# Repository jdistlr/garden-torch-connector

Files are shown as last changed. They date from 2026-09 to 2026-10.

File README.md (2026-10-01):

# Gartenfackel · gewählter Sockel D-V03

**Arbeitsstand 28.09.2026: prüfbares Konzept, keine Fertigungs- oder Betriebsfreigabe.** Ausschließlich Variante D wird weiterentwickelt: massive schwarze Aufnahme mit direkt eingeschnittenem axialem Gewindesackloch. Fünf Teile, keine Gewindebuchse oder Fügezone.

[Projekt öffnen](https://jdistlr.github.io/garden-torch-connector/web/projekt.html) · [Viewer öffnen](https://jdistlr.github.io/garden-torch-connector/web/variants.html) · [Entscheidungskette](docs/entscheidungen-d.md) · [Montage](docs/montage-d.md)

## Der rote Faden

1. **Verstehen:** [Originalfotos](sources/README.md) und [Steck-Dreh-Prinzip](docs/mechanik-d.md). Der frühere Erdspieß ist Referenz, kein Teil des neuen Sockels.
2. **Ausführung wählen:** 150 × 150 mm Grundplatte mit 5/8/9 mm, massive Aufnahme, radialer Stift, Senkschraube und geschlitztes Rohr. Detailmaße bleiben Konzeptwerte oder Fotoschätzungen.
3. **Nachweise unterscheiden:** Geometrie und nominale Bewegungsstichproben liegen vor. Reale Maße, Sicherungen, Werkzeugzugang, Kaufteilpassung und Standsicherheit sind offen.
4. **Teile abstimmen:** [Beschaffungskandidaten](docs/beschaffung-d.md) müssen gegen die [aktuelle Stückliste](docs/entscheidungen-d.md) freigegeben werden. Andere Rohr-/Stiftmaße sind bisher nicht im CAD übernommen.
5. **Kosten entscheiden:** [Budgetstudie](docs/kosten-d.md) für abweichende Kandidaten, ausschließlich 5 mm; noch kein Gesamtpreis des aktuellen CAD und kein Bestellpaket.
6. **Fertigen, montieren, prüfen:** [Konzeptanleitung und Prüfprotokoll](docs/montage-d.md). Erst nach den dokumentierten Nachweisen entsteht eine freigegebene Ausführung.

## Was vorhanden ist

- D-V03-STEP-Baugruppen und fünf Einzelteile für 5/8/9 mm, CAD-abgeleitete Browsermodelle.
- Je drei A3-Prüfzeichnungen für jede Plattenstärke. Im Viewer folgen PDF, Vorschau und STEP der Auswahl, auch wenn WebGL ausfällt.
- Freie 3D-Ansicht, Schnitt, Transparenz, Teileauswahl, Explosionsansicht, definierte Maße und PNG-Export.
- Geführte Konzeptmontage mit Pause, Schrittwahl, Zeitleiste und erklärenden Sockelschnitten. Die 50°-Demonstration zeigt keine Rastung.
- Regionale und Online-Beschaffungsrecherche, Budgetstudie für 1/5/10 Stück, druckbare Dokumentseiten.

Die gewählte Plattenstärke wird in Seitenlinks mitgeführt. Die Anzeige verändert keine CAD-Geometrie. Geometriebearbeitung im Frontend ist eine [spätere Ausbaustufe](docs/next-features.md).

## Was als Nächstes gebraucht wird

Drei Nachweispakete: (1) Rohr, Schlitz, Kopf und Stift direkt messen; (2) Originalbewegung einschließlich Rückweg filmen und Sicherung klären; (3) vollständige Fackel mit oberem Anschluss, Höhe und Gewicht erfassen. Daraus folgen passende Halbzeuge, Werkstoffe und eine gemeinsame Toleranz-/Sicherungsentscheidung. Verantwortlichkeiten und Abschlusskriterien: [Entscheidungskette](docs/entscheidungen-d.md).

## Dateien und Reproduzierbarkeit

| Bereich | Einstieg |
|---|---|
| Aktuelle Konstruktion / Grenzen | [sockel-d.md](docs/sockel-d.md) |
| Bestätigte Maße und offene Messungen | [measurements.md](docs/measurements.md) |
| CAD / Zeichnungen | `model/sockel_d.py`, `model/drawings_d.py` |
| Konzeptparameter | `parameters/sockel-d-v03.json` |
| Modelle, STEP, PDF, Prüfberichte | `web/assets/sockel-d/` |
| Bauen, prüfen, veröffentlichen | [viewer-runbook.md](docs/viewer-runbook.md) |
| Nächste Sitzung | [HANDOVER.md](docs/HANDOVER.md) |

`null` bedeutet unbekannt. 16 ursprüngliche Fotos entsprechen 14 verschiedenen Motiven; verkleinerte Vorschauen und Originalprüfsummen stehen unter `sources/`. Originaldateien nicht überschreiben.

D02 und V01 sind historische Referenzen. Der aktuelle Einstieg ist D-V03. GitHub Pages veröffentlicht den main-Branch; das Repository bleibt öffentlich.
# One More Thing

Zusätzlicher, Vectron-nah gestalteter, technisch fiktiver [Röntgenstrahler-Demonstrator](https://jdistlr.github.io/garden-torch-connector/web/one-more-thing.html): elf illustrative Baugruppen, schrittweise Erklärmontage, Kathode/Anodenteller/Flüssigmetalllager, schematische Strahlungsentstehung, erfundene Stückliste und zwei A3-Schemablätter. Kein realer Bauplan. [Abgrenzung und Implementierung](docs/xray-demo.md). Gartenfackel D-V03 bleibt ein eigenständiges Projekt.

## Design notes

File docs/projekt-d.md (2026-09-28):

# Gartenfackel · Projektübersicht

Alle Arbeitsbereiche der Gartenfackel an einem Ort. Aktuell: Sockel D-V03 und Rohrschnittstelle. Die vollständige Fackel und ihre Standsicherheit müssen noch erfasst werden.

[Zu allen Arbeitsbereichen](#im-projekt-arbeiten) · [Modell öffnen](variants.html)

## Jetzt: Original und gesamte Fackel erfassen

Der nächste Schritt ist ein belastbares Mess- und Funktionsprotokoll. Erst damit lassen sich passende Teile, Sicherungen und Kosten verbindlich festlegen.

1. **Rohr, Kopf, Stift und Schlitz messen.** [Messliste und zugehörige Fotos öffnen](quellen.html#erste-messrunde).
2. **Aufschieben, Verdrehen und Rückweg dokumentieren.** [Offene Funktionsprüfungen ansehen](mechanik.html#praktische-abnahme-noch-offen).
3. **Gesamte Fackel erfassen:** oberen Anschluss, Höhe, Gewicht, Wärme und Untergrund. [Entscheidungskette und Abschlusskriterien](entscheidungen.html#4-was-als-nachstes-getan-werden-muss).

Keine Maßzahl ist bislang als direkt gemessen bestätigt. Nominale CAD-Prüfungen ersetzen diese Arbeiten nicht.

## Im Projekt arbeiten

| Bereich | Was du dort tun kannst | Verbindung zum nächsten Schritt |
|---|---|---|
| [Fotos & Maße](quellen.html) | Originalbelege ansehen, Messliste und unbekannte Maße prüfen | Grundlage für [Bauteile](bauteile.html) und Passungen |
| [Entscheidungen](entscheidungen.html) | Festlegungen, Nachweise und offene Aufgaben nachvollziehen | Zeigt, welche Entscheidungen vor Fertigung fehlen |
| [Modell & Zeichnungen](variants.html) | 5/8/9 mm wählen; Schnitt, Transparenz, Explosion, Maße, Einzelteile und PNG nutzen | [A3-Zeichnungen](variants.html#drawing) und [STEP-Dateien](variants.html#engineering) folgen der Auswahl |
| [Bauteile](bauteile.html) | Jedes Teil mit Herkunft, CAD-Maß, Kandidat und offener Entscheidung verbinden | Direkt zu passender Beschaffung, Montage und STEP |
| [Mechanik & Prüfung](mechanik.html) | Bewegung, Spiel, Kontakte und Grenzen der Nachweise untersuchen | [Prüfprotokoll](montage.html#prufprotokoll-vor-freigabe) vor dem realen Einsatz |
| [Montage](montage.html) | Fertigung, Zusammenbau, Prüfung und Demontage nachvollziehen | [Geführte Animation öffnen](variants.html?mode=montage#design) |
| [Beschaffung](beschaffung.html) | Konkrete Artikel und regionale Anbieter vergleichen | Kandidaten erst nach Maß- und Materialentscheidung übernehmen |
| [Kosten](kosten.html) | 1/5/10 Stück, Eigenleistung und Werkstatt vergleichen | Noch keine vollständige Kalkulation der aktuellen CAD-Stückliste |

## Was zusammengehört

**Beispiel Querstift:** [Foto und Messung](quellen.html#foto-09) → [CAD, Kandidat und offene Sicherung](bauteile.html#pin) → [Artikel vergleichen](beschaffung.html#pin) → [Einbau erklären](variants.html?mode=montage&step=1#design) → [Funktion prüfen](mechanik.html#praktische-abnahme-noch-offen).

Die Plattenstärke gilt seitenübergreifend. Ein anderer Recherchekandidat verändert das CAD nicht automatisch. Downloads bleiben dem gewählten D-V03-Stand zugeordnet. Abweichungen und fehlende Kosten werden ausdrücklich angezeigt.

## Vorhanden und noch offen

Vorhanden: CAD/STEP, drei A3-Prüfblätter je Stärke, Modellwerkzeuge, geführte Konzeptanimation, geometrische Prüfberichte, Beschaffungsrecherche, Budgetstudie und Montageanleitung.

Offen: bestätigte Originalmaße, Werkstoffe und Oberflächen, realer Schraubenkopf, Stiftsicherung, Rückdrehsicherung, Einfluss auf die Sockelverschraubung und Nachweis der gesamten Fackel. **Keine Fertigungs- oder Betriebsfreigabe.**

Später: temporäre Maßänderungen im Browser mit Vergleich und Rücksetzen. Diese Funktion ist noch nicht implementiert; bestehende Prüfungen gelten nicht automatisch für veränderte Vorschauen.

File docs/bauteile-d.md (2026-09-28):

# Bauteile · vom Beleg zum Einbau

Fünf Teile bilden den aktuellen D-V03-Sockel. Jede Position verbindet ihre Herkunft mit CAD, Beschaffung und Montage. Alle Detailmaße sind Konzeptwerte oder Fotoschätzungen. Die vollständige Fackel oberhalb des Rohres ist noch nicht modelliert.

## 01 · Grundplatte

**CAD:** 150 × 150 mm; gewählte Stärke <span data-thickness>5</span> mm. Idealisierte Senkung Ø16,4 / 90°. Grundfläche aus vager Nutzerschätzung, Stärke eine Konzeptauswahl.

**Vor Übernahme entscheiden:** Werkstoff, Ebenheit, Beschichtung, reale Kopfkontur und Toleranzkette. Planer Bodenkontakt ist verbindlich, Belastbarkeit noch nicht belegt. Bepreister Kandidat bisher nur für 5 mm.

[Im Modell](variants.html?part=plate#design) · [Artikel für die Platte](beschaffung.html#plate) · [Senkung und Bodenfreiheit](mechanik.html#ergebnis-am-nominalen-konzept) · [Montageschritt](variants.html?mode=montage&step=4#design) · <a data-step-part="plate" href="assets/sockel-d/plate-5.step">STEP herunterladen</a>

## 02 · Massive Aufnahme

**CAD:** Ø24 × 50, direktes M8-Gewindesackloch. Vollmaterial ist entschieden; Länge, Sackloch und Stiftsitz sind Konzeptwerte. Der ursprüngliche Kopf ist Foto-Referenz, kein bestätigter Werkstoffnachweis.

**Kandidat:** Ø25-Vollmaterial auf Ø24 bearbeiten. Werkstoff, Oberfläche, tragende Gewindelänge und Stiftsitz auslegen. Keine separate Gewindebuchse.

[Originalkopf / Messung](quellen.html#foto-14) · [Im Modell](variants.html?part=adapter#design) · [Vollmaterial vergleichen](beschaffung.html#adapter) · [Gewindesitz erklären](variants.html?mode=montage&step=3#design) · <a data-step-part="adapter" href="assets/sockel-d/adapter-5.step">STEP herunterladen</a>

## 03 · Radialer Querstift

**CAD:** Ø4 × 21; 17 mm Überstand und 4 mm Sitz. Durchmesser und Überstand sind unbestätigte Fotoannahmen; Sitz ist eine Konzeptannahme.

**Kandidat:** Normstift Ø4 × 20 ist kein identischer Ersatz. Bei 4 mm Sitz verbleiben 16 statt 17 mm Überstand. Sicherung, Passung und Material klären; ein Händler nennt widersprüchlich A1/A2.

[Stiftfoto / Messung](quellen.html#foto-09) · [Im Modell](variants.html?part=pin#design) · [Stifte vergleichen](beschaffung.html#pin) · [Einbauschritt](variants.html?mode=montage&step=1#design) · [Kontakt und Rückdrehen](mechanik.html#kontakt-unter-gewicht-und-bedienmoment) · <a data-step-part="pin" href="assets/sockel-d/pin-5.step">STEP herunterladen</a>

## 04 · Senkschraube

**CAD:** M8 × 20 als idealisierte Hülle; nominal 0,2 mm über Bodenebene. Die Darstellung ist kein verifiziertes Normkaufteil.

**Vor Übernahme entscheiden:** Reale Kopfkontur, Festigkeitsklasse, Antrieb, tragendes Gewinde und Anziehverfahren. Die Schraube darf weder unterstehen noch am Sacklochgrund anschlagen.

[Senkkopf im Schnitt](variants.html?part=screw&view=detail#design) · [Schrauben vergleichen](beschaffung.html#screw) · [Verschraubung erklären](variants.html?mode=montage&step=3#design) · [Montageprüfung](montage.html#prufprotokoll-vor-freigabe) · <a data-step-part="screw" href="assets/sockel-d/screw-5.step">STEP herunterladen</a>

## 05 · Geschlitztes Fackelrohr

**CAD:** Ø27, innen Ø25, Länge 180; Schlitz aus unbestätigtem Fotoentwurf. Das Rohr verbindet den Sockel mit der noch zu erfassenden oberen Fackelschnittstelle.

**Kandidat:** Ø28 × 1,5 hat nominal ebenfalls Ø25 innen, aber eine andere Außengeometrie und Wandstärke. Ovalität, Naht, Schlitz, Oberfläche und oberen Anschluss prüfen; keine automatische Ersetzung.

[Rohr und Schlitz messen](quellen.html#erste-messrunde) · [Schlitzfoto](quellen.html#foto-15) · [Im Modell](variants.html?part=tube#design) · [Rohre vergleichen](beschaffung.html#tube) · [Aufschieben und Drehen](variants.html?mode=montage&step=6#design) · <a data-step-part="tube" href="assets/sockel-d/tube-5.step">STEP herunterladen</a>

## Kosten und gemeinsame Entscheidung

[Die Budgetstudie](kosten.html) verwendet das andere Rohr und den kürzeren Stift. Sie ist kein Gesamtpreis dieser unveränderten CAD-Stückliste. Nach der Teileentscheidung müssen CAD, Zeichnungen, Kosten und Anleitung gemeinsam aktualisiert werden. [Offene Entscheidungen](entscheidungen.html).

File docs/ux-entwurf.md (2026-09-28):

# Mobiler Bedienentwurf

Stand: 2026-09-28. Separate Vorschau `ux.html`; bestehender Viewer unverändert. Kein neuer CAD-Stand, keine Fertigungsfreigabe.

## Roter Faden

Modell verstehen → Aufbau nachvollziehen → Teile, Nachweise und Beschaffung beurteilen.
Drei gleichbleibende Bereiche: Modell, Aufbau, Projekt. Unterlagen bleiben aus ihrem sachlichen Zusammenhang erreichbar. Mobile Navigation unten, Desktop oben. Keine zweite globale Navigation.

## Kritik und konkrete Antwort

| Problem | Umsetzung |
|---|---|
| Konkurrierende Navigation und pseudoaktive Links | Drei echte Bereichsschalter mit eindeutigem Aktivzustand |
| Zu kleine mobile Schrift | 16 px Fließtext, 14–15 px ergänzende Texte; kleine Schrift nur für Metadaten |
| Beliebige Karten, Radien und Farbfelder | Offene Flächen, typografische Hierarchie, feine Trennlinien; Radien auf Bedienelemente begrenzt |
| Unruhige Grüntöne | Graphit, warmer neutraler Hintergrund, gezieltes Terrakotta für aktive Navigation und Hauptaktion |
| Unbeabsichtigtes Drehen statt Scrollen | Statische CAD-Vorschau als Einstieg; 3D ausdrücklich aktivieren und beenden |
| Nur Gesten als Steuerung | Drehen, Zoomen und Rücksetzen auch über Schaltflächen |
| Montagebild und Erklärung getrennt | Ein Bild, ein Schritt, ein erklärender Text und direkt anschließende Steuerung |
| Unlesbare Stücklistentabellen | Fünf ausklappbare Bauteilzeilen mit CAD, Kandidat und offener Entscheidung |
| A3-Blatt als kleiner Modellersatz | Eigene Bilder aus bestehenden CAD-Netzen; Zeichnungen separat groß öffnen |
| Unklare Belastbarkeit von Angaben | Konzeptstatus; Kandidatenabweichungen, fehlende Nachweise und Kostenbasis ausdrücklich benannt |

Primäre Touch-Ziele mindestens 48 px hoch. Dialoge verwenden native Fokusführung und Escape. Reduzierte Bewegung erhält manuelle Schritte. Keine automatische 3D-Bewegung. Die CAD-Bildfolge ist keine kontinuierliche Montageanimation und keine Kontakt- oder Kraftsimulation.

## Erweiterungsvertrag für spätere Browseränderungen

Noch nicht implementiert: geometrische Maßänderungen. Heute wählt die Oberfläche nur vorhandene 5-/8-/9-mm-Dateien.

| Zustand/Parameter | Bedeutung | Folge |
|---|---|---|
| sourceRevision | D-V03 mit Quelldatei-Prüfsumme | Ausgangsstand nachvollziehbar |
| plate | 5, 8 oder 9 mm | Modell, Bilder, Zeichnung und Download gemeinsam wechseln |
| view / step / selectedPart | Darstellung, Montageschritt, Bauteil | Reine Anzeigeänderung |
| camera / transparency | Ansicht und Transparenz | Keine Änderung der CAD-Geometrie |
| temporaryDimensions | Spätere temporäre Maßvorschau | Geometrisch veränderte Vorschau ausdrücklich ungeprüft |
| dirty / validationState | Änderung gegenüber Quelle; unbekannt, ungültig oder geprüft | Bestehende Nachweise nicht auf Vorschau übertragen |

Spätere Maßansicht: Ausgangswert, temporärer Wert, Einheit, Herkunft und zulässiger Eingabebereich zusammen anzeigen. Unbekannte Grenzen nicht erfinden. Aktionen: Vorschau anwenden, Ausgangsstand vergleichen, zurücksetzen. Keine STEP-Datei mit unveränderten Ausgangsmaßen als Export der geänderten Vorschau ausgeben. CAD-Neuberechnung bleibt ein eigenständiger späterer Arbeitsschritt.

## Prüfumfang

`ux-review.html` zeigt echte eingebettete Seiten bei 320, 375, 390 und 428 CSS-Pixeln. Dies ersetzt keine Prüfung auf iOS Safari oder Android. Desktop und schmale Browseransichten visuell prüfen; Navigation, Dialoge, Plattenwechsel und Downloads zusätzlich funktional prüfen. Ein grüner Build ist keine ästhetische Abnahme.

Die Modellbilder stammen aus den unveränderten D-V03-Netzen. Der Renderer verändert nur Projektion, Licht und bereits definierte Montagepositionen. Alle fünf Teile bleiben plate, adapter, pin, screw und tube.

### Durchgeführt

Live-Vorschau f00e2a9: Desktop visuell geprüft. Drei echte Browserrahmen mit Außenbreiten 320/375/390/428 px; wegen Rahmen und Desktop-Scrollbalken verfügbare Inhaltsbreite jeweils 17 px kleiner. Kein horizontaler Inhaltsüberlauf in Modell, Aufbau und Projekt. Geprüft: Plattenwechsel auf 9 mm einschließlich PDF-Link, Exportdialog öffnen/schließen, nächster Montageschritt, Abspielen/Pause, Kostenwahl 10 Stück. Screenshot: `ux-mobile-review.jpg`. Noch keine Geräteprüfung auf iOS/Android; 3D-WebGL-Funktion in dieser Cloud-Umgebung nicht visuell nachweisbar. Bestehende Unterseiten verwenden weiterhin ihr bisheriges Layout. Die neue Vorschau ist daher kein abgeschlossener Austausch aller Seiten.

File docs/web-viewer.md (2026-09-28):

# Viewer D-V03 · aktueller Funktionsvertrag

Fünf CAD-abgeleitete Teile, mm-Einheiten, drei vorhandene Plattenausführungen. Verfügbar: Drehen/Zoom, feste Ansichten, vorbereiteter Halbschnitt, Transparenz, Teileauswahl, Explosion, definierte Maßanzeigen, PNG-Export und geführte Konzeptmontage. Keine freie CAD-Messung, kein verschiebbarer exakter Schnitt, kein Geometrieeditor.

Plattenwahl, Zeichnungen, STEP und Dokumentnavigation funktionieren unabhängig von Three.js/WebGL. Die URL führt `plate=5`, `8` oder `9`; eine lokale Merkhilfe ist optional. Eine explizite URL-Auswahl hat Vorrang. Kosten zeigen die Auswahl, aber erklären ausdrücklich die abweichende 5-mm-Kandidatenstudie. Es wird kein Preis für 8/9 mm erfunden.

Montage: Zielbilder per Schrittwahl, passende Aktionsbeschreibung in Übergängen, Pause/Replay, kein Autoplay. Bei reduzierter Bewegung nur manuelle Schrittwahl. Freie Ansichts- und Ausblendwerkzeuge sind während geführter Montage gesperrt; Schnitt betrifft dort den Sockel, nicht das rotierende Rohr. Nach Verlassen ist freie Betrachtung wieder möglich. Auf kleinen Bildschirmen ist die Montageansicht verkleinert; sie bleibt im normalen Seitenfluss. Keine klebenden Elemente.

Keine Kraft-, Gewinde- oder Schwerkraftsimulation. Freier Rückweg; Kontakt unter Gewicht bleibt im Begleittext erklärt. Schnitte, Sichtbarkeit und Explosion verändern keine CAD-Datei. PNG enthält die 3D-Darstellung, keine vollständige Dokumentation oder Freigabe.

Fehlerfälle: 3D-Steuerung deaktivieren, verständlichen Status zeigen, keine veralteten Modelle als aktuelle Auswahl stehen lassen. Dokumente bleiben erreichbar. Revision und die fünf Teile-IDs werden beim Laden geprüft.

Spätere Vorschauänderungen ohne Modellgenerierung: [Backlog](next-features.md). Vor Umsetzung klare Trennung zwischen Anzeigeänderung und ungeprüfter Geometrieänderung festlegen.

## Gestaltung

Gemeinsame Navigation und `design.css` für alle sechs aktuellen Seiten. Keine dekorativen Karten, keine kastenförmigen Navigationslinks. Funktionale Bedienelemente sind von Dokumentlinks getrennt. Modell zuerst, weiterführende Texte auf den Fachseiten. WebGL-Ersatzansicht zeigt ausdrücklich die vorhandene Prüfzeichnung, kein vorgetäuschtes 3D.

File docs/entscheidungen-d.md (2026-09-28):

# D-V03 · Von der Entscheidung zum geprüften Sockel

Stand 28.09.2026. **Konzept, keine Fertigungs- oder Betriebsfreigabe.** Auf allen aktuellen Seiten bezeichnet D-V03 dieselben fünf CAD-Teile. Die Plattenwahl wählt einen vorhandenen Export; sie berechnet kein neues Modell.

## 1. Verbindlich entschieden

Nur Variante D: schwarze Aufnahme aus Vollmaterial mit direkt eingeschnittenem axialem Gewindesackloch; separater radialer Stift; Senkschraube von unten. Kein Bauteil darf unter die ebene Plattenunterseite ragen. Grundfläche etwa 150 × 150 mm, Plattenstärken 5/8/9 mm als Konzeptauswahl. Material, Toleranzen und Belastbarkeit sind damit nicht entschieden.

## 2. Eine Stückliste, klar getrennte Kandidaten

| Pos. / CAD-ID | Aktuelles CAD D-V03 | Recherchekandidat | Entscheidung vor Übernahme |
|---|---|---|---|
| 1 · plate | 150 × 150 × 5/8/9, ideale Senkung Ø16,4 / 90° | S235-Platte, bepreist nur 5 mm | Werkstoff, Ebenheit, reale Kopfkontur, Toleranzkette und Beschichtung festlegen |
| 2 · adapter | Ø24 × 50 massiv, direktes M8-Sackloch | Ø25-Vollstahl zu Ø24 bearbeiten | Material, Oberfläche, tragendes Gewinde und Stiftsitz auslegen |
| 3 · pin | Ø4 × 21, 17 Überstand + 4 Sitz | Normstift Ø4 × 20 | Kein identischer Ersatz. Sitz/Überstand/Sicherung und widersprüchliche Materialangabe klären |
| 4 · screw | M8 × 20, idealisierte Kopfhülle | Konkrete Norm-Senkschraube | Kopfkontur einschließlich Rand, Festigkeit, Antrieb und Anziehverfahren prüfen |
| 5 · tube | Ø27 / innen Ø25 × 180; Schlitz aus Fotoentwurf | Rohr Ø28 × 1,5, nominal innen Ø25 | Andere Wandstärke/Geometrie. Ovalität, Naht, Schlitz und obere Schnittstelle prüfen |

Die [Beschaffung](beschaffung-d.md) liefert Vergleichskandidaten. Die [Budgetstudie](kosten-d.md) rechnet mit dem anderen Rohr und dem kürzeren Stift. **Für die unveränderte CAD-Stückliste gibt es noch keine vollständige Gesamtsumme.** Kein Artikel ist allein durch einen Link als kompatibel freigegeben. Es wurden keine Händler kontaktiert.

## 3. Was belegt ist

- Fünf gültige CAD-Körper je Plattenstärke, keine Volumenüberschneidungen in der gespeicherten Einführlage, kein nominaler Bodenüberstand; STEP-Rückimport geprüft.
- Rohrweg und gesamte schematische Montage an diskreten Positionen geprüft. Keine lückenlose Bewegungs-, Toleranz-, Kraft- oder Dauerfestigkeitsprüfung.
- Rohrdrehung bis 50° als Demonstration; erster nominaler Anschlag etwa 55,8°. Rückweg frei. Keine selbsttätige Rastung nachgewiesen.
- In der Darstellung steht das Rohr mittig im 2-mm-Nutspiel. Unter Gewicht wäre etwa 1 mm Absenkung bis zum Kontakt nötig. Die Animation simuliert diesen Lastkontakt nicht.

Details und Prüfberichte: [Mechanik](mechanik-d.md). Die vollständige Fackel ist noch nicht Teil des CAD; der Sockel allein belegt keine Standsicherheit.

## 4. Was als Nächstes getan werden muss

| Reihenfolge | Tätigkeit / Zuständigkeit | Ergebnis, das die Entscheidung schließt |
|---|---|---|
| 1 | Besitzer des Originals: Rohrinnen-/Außenmaß, Kopf, Stift, Schlitz und Abzweig messen | Messprotokoll mit Bezug, Messmittel, Datum und Fotos; keine Foto-Schätzung als Istmaß |
| 2 | Besitzer / Werkstatt: kalte Originalbewegung bis Anschlag und zurück dokumentieren | Richtung, Endwinkel, Spiel, mögliche Rückdrehsicherung identifiziert; keine Freigabe durch Video allein |
| 3 | Besitzer: vollständige Fackel erfassen | Oberer Anschluss, Höhe, Gewicht, Schwerpunkt/Lastannahmen, Wärme und Untergrund bekannt |
| 4 | Konstruktion / Werkstatt: kompatible Halbzeuge, reale Schraube, Stiftsitz und Sicherung festlegen | Eine spezifizierte Stückliste; Toleranzen einschließlich Oberfläche, Gewinde und Klemmung ausgelegt |
| 5 | Werkstatt: Muster fertigen und Werkzeug-/Handzugang prüfen | Montage möglich; Kopf bleibt versenkt; Stift wandert nicht; Aufnahme dreht bei Bedienung nicht mit |
| 6 | Konstruktion / prüfende Werkstatt: Gesamtfunktion und Stand unter vorher festgelegten Lasten prüfen | Dokumentierte Abnahme einschließlich Rückdrehen, Kippen, Wiederholung und Pflege; erst dann Betriebsfreigabe |
| 7 | Nach Teileentscheidung: Preise und Fertigungsangebot vervollständigen | Gleiche Stückliste in CAD, Zeichnung, Kosten und Anleitung; Endpreise für gewünschte Mengen/Stärke |

Schritte 4 und 7 können vorbereitet werden. Die freigegebene Gesamtsumme kann erst nach Auswahl und Auslegung entstehen. Händlerkontakt und Bestellung benötigen einen gesonderten Auftrag.

## 5. So benutzt man die Seiten

**Viewer:** Form, Plattenstärke und nominelle Geometrie untersuchen. **Mechanik:** Weg, Kontakt und Grenzen verstehen. **Beschaffung:** Kandidaten vergleichen. **Kosten:** abweichende Budgetstudie bewusst einordnen. **Montage:** Herstellung, Benutzermontage und Prüfprotokoll unterscheiden.

Eine ganzzahlige Animationsposition zeigt das Zielbild des Schritts; dazwischen beschreibt der Text die laufende Bewegung zum nächsten Zielbild. Der Querstift-Einbau ist ein Fertigungsschritt. Der 35-mm-Hub zeigt lediglich Zugang von unten, keinen bestätigten Werkzeugfreiraum. Während der Montage bleibt das Rohr ungeschnitten, damit keine mitrotierende Halbschnittfläche als feste Schnittebene missverstanden wird.

## Später: im Frontend ausprobieren

Zurückgestellt: Maße als temporäre Vorschau verändern, ohne STEP/PDF neu zu erzeugen. Vor Umsetzung festlegen, welche Änderungen rein visuell sind und welche Geometrie/Passung verändern. Jede solche Vorschau muss als **ungeprüft** erscheinen; gespeicherte Prüfwerte, Zeichnungen und Preise dürfen nicht auf sie übertragen werden. Rücksetzen und Vergleich zum geprüften Ausgangsstand vorsehen. Noch nicht implementiert.

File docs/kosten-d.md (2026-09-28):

# Budgetstudie · abweichende Teile, 5-mm-Platte

[Gemeinsamer Stand, Stückliste und nächste Entscheidungen](entscheidungen-d.md)

Stand28.09.2026. **Vollständiges Kostenschema mit Planungsszenarien, kein vollständiges Händlerangebot.** Die Fertigungs-/Oberflächenkosten sind eigene Budgetannahmen. Für8/9mm Platte fehlen passende Endpreise; die folgende Rechnung gilt ausschließlich für5mm. Das Beispiel nutzt außerdem Kandidatenrohr28×1,5 und Stift4×20, die noch nicht die unveränderte D-V03-Geometrie darstellen. Nicht als fertigen Einkaufsauftrag benutzen.

## Öffentlich bepreister Teilwarenkorb

Quellen und Artikelnummern: [Beschaffungsmatrix](beschaffung-d.md). Kein tatsächlicher Warenkorb wurde bestellt oder reserviert. Keine Mehrwertsteuer doppelt addieren: Händlerpreise hier brutto.

| Position | 1 Stück | 5 Stück | 10 Stück |
|---|---:|---:|---:|
| Platte5mm, je5,99 | 5,99 | 29,95 | 59,90 |
| RundvollstahlØ25, ganzer1m-Stab | 10,78 | 10,78 | 10,78 |
| Versand Stahl-Shop24 gemeinsam | 8,90 | 8,90 | 8,90 |
| 10 Senkschrauben Norm-genau, Versand enthalten | 5,32 | 5,32 | 5,32 |
| RST Stifte4×20, Einzelteile bzw.10er-Pack | 0,17 | 0,85 | 1,54 |
| RST Versanduntergrenze | 5,90 | 5,90 | 5,90 |
| **Teilwarenkorb, noch ohne Rohr/Bearbeitung/Oberfläche** | **37,06** | **61,70** | **92,34** |

RST-Materialangabe ist widersprüchlich; diese Preisposition ist deshalb ein Vergleichskandidat. Versand5,90 ist als „ab“-Wert belegt, keine geprüfte finale Versandquote.

Rohr-DOLD: rechnerisch5€/m +0,50 je Schnitt, dazu3€ Logistik. Für185mm Rohling (180mm fertig plus5mm Planreserve) sind das1,425€ vor Logistik. Konservative Rechnung: **3€ je Zuschnitt** bis die tatsächliche Zuordnung im Warenkorb geklärt ist; Rohr und Logistik somit4,425€/St. Zusätzlich eigener Versandplatzhalter6/10/20€ je Auftrag. Das ist keine verifizierte Versandgebühr. Wenn3€ nur einmal pro Auftrag anfallen, reduziert sich die Rechnung um3×(n−1)€.

## Restmengen und Verschnitt vollständig bezahlen

| Kaufmenge / Verwendung | 1 | 5 | 10 |
|---|---:|---:|---:|
| Vollstab gekauft | 1000mm | 1000mm | 1000mm |
| Verbrauch mit angenommener Teilung55mm pro fertiger50-mm-Aufnahme | 55mm | 275mm | 550mm |
| Bezahltes Reststück vor Endverlusten | 945mm | 725mm | 450mm |
| Restschrauben aus10er-Pack | 9 | 5 | 0 |
| Rohr gekauft als185-mm-Zuschnitt | 185mm | 925mm | 1850mm |
| Rohr-Planreserve insgesamt | 5mm | 25mm | 50mm |

Sägeschnitt und Planreserve am Vollstab zusammen5mm/St. sind Kalkulationsannahmen, mit Werkstatt abstimmen. Kein Restmaterialverkaufserlös gegengerechnet. Reste sind in obigen Kaufbeträgen vollständig enthalten. 9/5 Restschrauben werden nicht fiktiv weiterverkauft.

## Eigene Budgetannahmen

| Kostenart | Niedrig | Mittel | Hoch |
|---|---:|---:|---:|
| Noch offener Rohrversand, brutto/Auftrag | 6 | 10 | 20 |
| Eigenleistung: Werkzeugzukauf/Auftrag | 25 | 50 | 90 |
| Eigenleistung: Oberflächenmittel, ganze Gebinde/Auftrag | 15 | 30 | 60 |
| Hilfsmittel, Reinigen, Sicherung nach Auswahl/Auftrag | 5 | 10 | 20 |
| Werkstatt: Rüsten/Programmieren h/Auftrag | 1 | 1,5 | 2,5 |
| Werkstatt: Bearbeitung/Montage/Prüfung h/Stück | 0,65 | 1 | 1,5 |
| Werkstatt: Stundensatz **netto** | 60 | 85 | 120 |
| Werkstatt: Oberflächencharge **brutto** | max(60;12×n) | max(100;20×n) | max(180;35×n) |

Bearbeitungszeit umfasst Ablängen/Planen/Ø24-Drehen, Direktgewinde und radialen Stiftsitz, Platte bohren/senken, Rohrschlitze, Entgraten, Montage und Maß-/Funktionskontrolle. Kein kalkuliertes Verfahren für eine zusätzliche Rückdrehsicherung. Dafür ist die Konstruktion noch offen. Werkstattsätze und Zeiten sind **keine recherchierten regionalen Angebote**.

Eigenleistung setzt bereits vorhandene geeignete Dreh-/Fräsmöglichkeit, sichere Spannmittel und Messausrüstung voraus; Maschinenkauf ist nicht in25–90€ Werkzeug enthalten. Fehlt diese Ausstattung, ist dieses Szenario nicht nutzbar. Eigenzeit: angenommene2h Vorbereitung plus1,5h/Stück, also3,5/9,5/17h; monetär mit0€ bewertet und separat ausgewiesen. Selbstkosten lassen sich durch persönlichen Stundenwert×Eigenzeit ergänzen.

## Gerundete Planungsspannen für die Kandidatenstudie

Bewusst auf etwa 10 EUR gerundet; die Rechenwerte im JSON sind keine Preisgenauigkeit. **Keine Gesamtsumme für das unveränderte D-V03-CAD.**

| Menge | Eigenleistung niedrig / mittel / hoch, EUR Auszahlung | Werkstatt niedrig / mittel / hoch, EUR gesamt brutto |
|---|---|---|
| 1 | ca. 90 / 140 / 230 | ca. 230 / 410 / 830 |
| 5 | ca. 130 / 180 / 270 | ca. 460 / 860 / 1.730 |
| 10 | ca. 190 / 240 / 330 | ca. 800 / 1.520 / 3.030 |

Keine Preisprognose oder garantierte Obergrenze. Externe Mindestauftragswerte, Rückdrehsicherung, andere Werkstoffe, Prototypwiederholungen und zusätzliche Nachweise sind nicht abschließend kalkuliert. Oberfläche enthält nur ein Budget für schwarze Aufnahme und Korrosionsschutz; Verfahren und Temperaturbeständigkeit bleiben offen. Für 8/9 mm fehlt eine entsprechende Studie.

Formel Werkstatt: bepreister Teilwarenkorb + Rohr/Logistik + Rohrversandplatzhalter + (Rüstzeit + n×Bearbeitungszeit)×Nettostundensatz×1,19 + Oberflächencharge brutto + Hilfsmittel. Eigenleistung: Teilwarenkorb + Rohr/Logistik + Versandplatzhalter + Werkzeug + Oberflächengebinde + Hilfsmittel.

Reproduzierbar: `python3 model/cost_d.py`; [JSON](../web/assets/sockel-d/cost-scenarios.json). Angebotspreise ersetzen die Annahmen positionsweise. Erst danach darf eine finale Gesamtsumme entstehen.

## Wirtschaftliche Reihenfolge

Für1Stück zuerst ein regionales Reststück-/Komplettfertigungsangebot vergleichen: der1m-Stab wird überwiegend Rest. Für5/10Stück gemeinsame Materialbestellung und gemeinsame Oberflächencharge; nicht pro Stück Versand/Rüsten berechnen. Bei passendem vorhandenen Rohr dessen Wiederverwendung als eigenes Szenario rechnen, nicht kommentarlos0€ ansetzen. Ein Händler mit billigstem Einzelpreis kann durch Versand und Restmengen insgesamt teurer sein.

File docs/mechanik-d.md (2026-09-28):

# D-V03 – Steck-Dreh-Prüfung

[Gemeinsamer Stand, Stückliste und nächste Entscheidungen](entscheidungen-d.md)

Stand 28.09.2026. Geprüft werden vorhandene STEP-Körper, keine gemessenen Originalteile. Geometrie und Zeichnungsrevision bleiben D-V03.

## Bezug und Bewegung

Boden z=0, Rohrachse +Z, Stift zeigt +Y. Blick **von oben zur Platte**: positive Rohrdrehung gegen den Uhrzeigersinn. Die bisherige STEP-Baugruppe zeigt die **Einführlage** (0°), nicht die verdrehte Endlage. Für die Animation wird ausschließlich das Rohr bewegt; die Sockelaufnahme bleibt fest.

1. Rohr 40 mm oberhalb der bisherigen Einführlage halten, Schlitz mittig auf +Y.
2. Rohr ohne Rotation um 40 mm absenken. Die Unterkante liegt anschließend bei Plattendicke +14 mm, die Stiftmitte bei Plattendicke +35 mm.
3. Rohr um +50° drehen. Diese Darstellungsposition liegt vor dem ersten geometrischen Anschlag, sie ist keine eingerastete Endlage.
4. Zum Lösen um −50° zurückdrehen und axial abziehen. Der Rückweg ist geometrisch ebenso frei.

## Ergebnis am nominalen Konzept

| Merkmal | Ableitung | Bedeutung |
|---|---|---|
| Radiales Spiel | (25−24)/2 = 0,5 mm | Unbelastet konzentrisch; kein Toleranznachweis |
| Schlitzspiel je Seite | (5−4)/2 = 0,5 mm | Ausrichtung beim Einführen erforderlich |
| Axiales Spiel im Abzweig | 6−4 = 2 mm gesamt | Von mittiger Lage je 1 mm bis Kontakt |
| Nutsektor | 65° | Ist nicht der mögliche Drehwinkel des endlichen Stifts |
| Erster Drehkontakt | 65°−asin(2/12,5) ≈ 55,79° | Stift berührt die radiale Endwand am Innenradius des Rohrs |
| Anzeigeweg | 0…50° | Nominale Reserve vor Anschlag; kein Fertigungs-Sicherheitsabstand |
| Rückdrehsicherung | nicht modelliert | Keine Rastung, Feder, Rampe oder Hinterschneidung, die Zurückdrehen blockiert |

`python3 model/check_motion_d.py` prüft jede Plattenstärke in Schritten von 0,5 mm bzw. 0,5° gegen die vier festen Körper. Der JSON-Bericht enthält Stichprobenzahl, Schnittvolumen, Mindestabstand, Gegenproben und STEP-Prüfsummen. Abtastung ist kein mathematisch lückenloser Hüllvolumennachweis. Konzentrische Zylinder und der durchgehende Einführschlitz erklären die freien Zwischenlagen zusätzlich geometrisch.

Absichtliche Gegenproben: −5° in falscher Richtung; +60° über den Anschlag; nach +50° axial um ±1,1 mm verschieben. Diese Lagen überschneiden den Stift. Damit wird insbesondere nicht nur das Ausbleiben einer Fehlermeldung als Prüfung gewertet.

## Kontakt unter Gewicht und Bedienmoment

In der mittigen Darstellungsposition trägt der Stift das Rohr noch nicht: je 1 mm axiale Luft. Unter Eigengewicht sinkt das Rohr bis zur oberen axialen Nutwand ab. Beim Hochziehen liegt die gegenüberliegende Wand am Stift an. Diese Kontaktlagen sind weder Reibungs- noch Festigkeitsnachweise. Die Animation stellt die mittige geometrische Position dar und simuliert keine Schwerkraft.

Drehmoment gelangt über Nutwand/Stift in die massive Aufnahme und über deren Klemmkontakt zur Platte. Bei festgehaltener Schraube mit Rechtsgewinde kann eine Mitdrehung der Aufnahme **gegen den Uhrzeigersinn von oben** die Aufnahme vom Schraubenkopf wegbewegen und die Klemmung lösen; **im Uhrzeigersinn von oben** kann sie sich weiter auf das Gewinde ziehen. Gerade das Eindrehen des Rohres muss deshalb am Muster geprüft werden. Drehrichtung allein ersetzt keine ausreichende Vorspannung oder Losdrehsicherung.

Der idealisierte Schraubenkonus liegt nominal an der Senkfläche: bei z=0,2 besitzt die Senkung Radius 8,0 mm, ebenso der Kopf. Reale Kopfkontur einschließlich Kopfrand ist hiervon nicht abgedeckt. Keine Vorspannung aus dem reinen Schnittvolumen ableiten.

## Toleranzen und Beschichtung

Reale Mindestluft radial = (kleinster Rohrinnendurchmesser − größter fertiger Kopfdurchmesser)/2; Beschichtung auf Kopf und Rohrinnenfläche reduziert das Spiel zusätzlich. Ovalität, Schweißnaht, Grat und Achsversatz berücksichtigen. Entsprechend Nutbreite minus größter fertiger Stiftdurchmesser prüfen. Bei Rohrersatz oder geändertem Stift CAD, Zeichnungen und Bewegungsprüfung gemeinsam neu erzeugen.

## Praktische Abnahme – noch offen

- Kalt und ohne Brennstoff prüfen; Stiftfestigkeit und Verschraubung vorher freigeben.
- Aufnahme/Platte mit gemeinsamem Kontrollstrich markieren, Einstecken und Drehen mehrfach durchführen. Kein Mitdrehen, kein Klemmen; reales Drehmoment erfassen.
- Axialspiel und Endwinkel messen; Stift darf nicht wandern. Gegen Zurückdrehen ist aktuell keine positive Sicherung nachgewiesen.
- Fackelhöhe, Gesamtgewicht, Schwerpunkt, Wind-/Stoßlast und Untergrund für Standprüfung festlegen. Die 150-mm-Platte ist kein Standsicherheitsnachweis.

Drei nächste Rückfragen: (1) Rohrinnen- und Kopfdurchmesser sowie Stiftmaß messen; (2) Originalbewegung bis Anschlag und zurück filmen, insbesondere mögliche Rastung; (3) vollständige Fackel mit Höhe/Gewicht und oberem Anschluss zeigen.

## Gesamte Montagefolge

Zusätzlich wurden je71Posen der vollständigen Animation für5/8/9mm geprüft: alle zehn Körperpaare, einschließlich radialem Stifteinsetzen, axialem Aufsetzen, Schraubenzuführung und Absetzen. Keine Volumenüberschneidung und kein Bodenunterstand an den Abtastpunkten. Bericht `web/assets/sockel-d/assembly-motion-checks.json`. Montageauflagen/Hand/Werkzeug fehlen im CAD; der35-mm-Hub zeigt den erforderlichen Zugang schematisch. Beim Schrauben wird nur die glatte Hülle geprüft, nicht das Gewindeprofil oder Vorspannung.

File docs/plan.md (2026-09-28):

# Aktueller Arbeitsplan D-V03

Der operative Einstieg ist die [Entscheidungskette](entscheidungen-d.md). Sie verbindet fünf Teile, Nachweise, Kandidaten und die nächsten Tätigkeiten.

Aktuell vorhanden: CAD/STEP/A3 für 5/8/9 mm, Viewer und Konzeptanimation, nominale Prüfberichte, Recherche, Budgetstudie und Konzeptanleitung. Kein Neubeginn bei D02; keine Varianten A–C weiterentwickeln.

Nächste reale Ergebnisse: Originalmaße und Bewegung, vollständige Fackel, kompatible Stückliste, Toleranz- und Sicherungsauslegung, Musterprüfung, darauf abgestimmte Kosten und Auftragspaket. Softwarekorrekturen ersetzen diese Nachweise nicht.

[Ausbaustufen und spätere Frontend-Vorschau](next-features.md) · [Reproduzieren](viewer-runbook.md)

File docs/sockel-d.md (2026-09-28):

# Gewählte Sockelvariante D-V03

Konzeptstand vom 28.09.2026. Grundplatte 150 × 150 mm; 5, 8 oder 9 mm Stärke. Massive Aufnahme mit direkt eingeschnittenem Gewindesackloch, von unten versenkte Schraube. Alle neuen Detailmaße sind Konstruktionsannahmen; ursprüngliche Maße sind unbestätigte Fotoschätzungen.

## Prüfergebnis

| Plattenstärke | Kopf über Bodenebene | Restdicke neben Senkung | Nominale Gewindeüberdeckung |
|---|---|---|---|
| 5 mm | 0,2 mm | 1,3 mm | 15,2 mm |
| 8 mm | 0,2 mm | 4,3 mm | 12,2 mm |
| 9 mm | 0,2 mm | 5,3 mm | 11,2 mm |

Für jeden Stand: fünf gültige Einzelkörper, keine volumetrischen Überschneidungen in Montagelage, kein Körper unter z=0, STEP-Rückimport mit fünf Körpern und übereinstimmendem Volumen. Siehe maschinenlesbare Ergebnisse in `web/assets/sockel-d/checks.json`.

Das beweist die geometrische Montagelage, nicht Festigkeit, Kippsicherheit oder Kollisionsfreiheit während der Montage. Die Gewindeüberdeckung ist geometrisch, nicht wirksame tragende Gewindelänge. Gewinde sind vereinfacht dargestellt. Schraube und Senkung sind ideale Konzeptgeometrie, noch kein maßgetreu verifiziertes Normkaufteil. Die Aufnahme ist Vollmaterial. Querstift und Aufnahme sind separate Körper; Stiftsitz und Sicherung sind auszulegen. Das M8-Gewinde ist als nominale glatte Hülle dargestellt, nicht als Kernloch-Fertigungsmaß. Konzept: Gewinde-Zieltiefe 18 mm, zylindrische Bohrtiefe 20 mm plus 2,4 mm Spitze. Platte und Fackelhöhe, Gewicht und Seitenlasten müssen gemeinsam beurteilt werden.

## Ansichten und Dateien

- `web/variants.html`: ausgewählte D-Version mit Plattenwahl, Schnitt, Explosion, Bodenansicht, Detail, Transparenz, Rohr ein/aus, Maßen und PNG-Export.
- `web/assets/sockel-d/`: STEP-Baugruppen und Einzelteile für jede Stärke, Viewer-Geometrien und Prüfbericht.
- `zeichnungen-D-V03-{5,8,9}mm.pdf`: je drei A3-Blätter pro Plattenstärke; Platte/Senkung, massive Aufnahme/Querstift, Zusammenbau. Klassische Schwarzweißdarstellung mit Schnitten und Schriftfeld, keine Behauptung vollständiger historischer Normkonformität.
- `web/variants-v01.html`: verworfenes Variantenarchiv.

## Reproduzieren

Python mit CadQuery und ReportLab: `python3 model/sockel_d.py`, danach je Stärke `D_PLATE_THICKNESS=5 python3 model/drawings_d.py` (ebenso mit 8 und 9). Die dokumentierten Konzeptparameter liegen in `parameters/sockel-d-v03.json`. Bei Maßänderungen Generator, Parameterdatei, Zeichnungen und Prüfwerte gemeinsam aktualisieren; noch keine universelle Parametrik für beliebige Produkte.

## Nächste Entscheidungen

[Entscheidungskette](entscheidungen-d.md): reale Maße und Funktion, vollständige Fackel, kompatible Stückliste, Sicherung und Belastbarkeit. Recherche, Budgetstudie, Konzeptanleitung und Animation sind vorhanden. Die Budgetstudie verwendet teilweise andere Teile und ist kein Preis des aktuellen CAD.

## Stückliste D-V03

| Pos. | Teil | Menge | Status |
|---|---|---|---|
| 1 | Grundplatte 150 × 150 × 5/8/9 | 1 | Stärke auswählen |
| 2 | Massive Aufnahme Ø24 × 50, direktes M8-Sackloch | 1 | Werkstoff und Detailmaße offen |
| 3 | Radialer Querstift Ø4, Gesamtlänge 21 | 1 | 17 Überstand + 4 Sitz: Konzept, Sicherung offen |
| 4 | Senkschraube M8 × 20 | 1 | Kaufteil auswählen, derzeit idealisierte Hülle |
| 5 | Geschlitztes Fackelrohr | 1 | D02-Fotoschätzung |

Keine Gewindebuchse, Passhülse oder ringförmige Fügezone. D-V02 wurde durch D-V03 ersetzt und bleibt nur in der Git-Historie rekonstruierbar. V01 ist ausdrücklich verworfenes Archiv.

Sacklochabstand zur Schraubenspitze: 4,8 / 7,8 / 8,8 mm für Platte 5 / 8 / 9 mm, gemessen bis zum Beginn der Bohrspitze. Die nominale Überdeckung beträgt weiterhin 15,2 / 12,2 / 11,2 mm; Gewindeauslauf und reale Schraubenspitze sind zusätzlich zu berücksichtigen.

## Montageübersicht

Aufnahme aus Vollmaterial fertigen, direktes Sacklochgewinde herstellen und Querstift sichern. Platte anheben, Aufnahme aufsetzen, Senkschraube von unten einschrauben und mit noch festzulegender Vorspannung sichern. Schraube darf nicht am Sacklochgrund anschlagen. Platte absetzen, Bodenfreiheit prüfen. Rohr erst nach Prüfung des Steck-Dreh-Wegs aufschieben und drehen. Kein bestätigtes Einrasten voraussetzen. Die Explosionsansicht ist eine Teileübersicht, keine geprüfte Bewegungsanimation.

## Ergänzung: Einführlage und geführte Montage

Die bestehende STEP-Baugruppe ist bei0° in **Einführlage**, nicht in verdrehter Endlage. Der nominale Weg bis50° ist abgetastet; ca.55,8° ist der erste geometrische Drehkontakt, obwohl der Nutsektor65° beträgt. Rückdrehen bleibt frei. Siehe [Mechanik](mechanik-d.md), [Montage](montage-d.md), [Beschaffung](beschaffung-d.md) und [Kosten](kosten-d.md). Die geführte Animation ersetzt nicht den Versuch am Original.

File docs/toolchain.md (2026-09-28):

# Aktuelle Werkzeugkette D-V03

CadQuery 2.7.0 erzeugt Volumenkörper, STEP und Mesh-JSON in Millimetern. `model/drawings_d.py` erzeugt die A3-PDFs mit ReportLab. Three.js stellt die CAD-abgeleiteten Netze und vorbereiteten Schnitte dar. FreeCAD/TechDraw war eine frühere Option und ist keine Voraussetzung des vorhandenen Exports. GLB ist derzeit nicht im Einsatz.

`model/render_docs.cjs` erzeugt Dokumentseiten aus Markdown. `model/check_release.py` prüft die gemeinsame Veröffentlichung gegen ein Dateihash-Manifest. Dieses Manifest dokumentiert Zusammengehörigkeit; es ist kein zusätzlicher mechanischer Nachweis.

Generatoren enthalten noch Konzeptkonstanten außerhalb der JSON-Parameterdatei. Bis zu einer vollständigen Parametrisierung müssen Geometrieänderungen gemeinsam durch CAD-, Zeichnungs-, Bewegungs- und Dokumentprüfung laufen. Keine beliebigen Werte als automatisch unterstützt darstellen.

[Konkrete Befehle und Grenzen](viewer-runbook.md).

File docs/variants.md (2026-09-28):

# Archivhinweis

Die ursprünglichen Varianten A–D (V01) sind überholt. Gewählt ist [D-V03](sockel-d.md) mit vollständig versenktem Schraubenkopf. Angaben unten dienen nur der Historie.

# Sockelvarianten V01

Zweite Seite: web/variants.html. Bestand D02 und seine Zeichnungen bleiben unverändert.

## Herkunft

Nutzerschätzung vom 28.09.2026: Grundplatte 150 × 150 mm, vorläufig 5 mm stark, eventuell 8–9 mm. Dargestellt ist nur die 5-mm-Version. Kopf und radialer Stift folgen den unbestätigten D02-Fotomaßen. Alle übrigen Maße sind frei gewählte Konzeptannahmen, in der Webseite aufgelistet und im Generator model/variants.py dokumentiert. Sie sind keine Fertigungsmaße.

A: Original kürzen, axialer Gewindegang als glatte Bohrung. B: breiter Fuß, Zentralverschraubung und Passstift. C: Flansch mit drei Schrauben. D: Hülse und gefügte Gewindebuchse; Fügezone nur schematisch. Schrauben sind vereinfachte Platzhalter, keine normmaßhaltigen Kaufteilmodelle. Das Gewinde selbst ist nicht modelliert. Für die 5-mm-Platte stehen Köpfe unterhalb hervor; Freiraum/Füße oder ein späteres Senkkopfkonzept erforderlich. Keine Füße im Modell.

## Reproduzieren

Nach model/build.py: `python3 model/variants.py`. CadQuery erzeugt volle Solids, echte halbe Schnittkörper, gemeinsame STEP-Konzeptdateien und Meshes je Variante. Schnitt zeigt y >= 0; Explosionsverschiebungen dienen nur der Darstellung. Modelleinheit mm. Alle Teile vor Export auf gültigen einzelnen Solid und positives Volumen geprüft.

## Kostenschätzung

Eigene Rechenannahme: 80–120 €/h netto. Zeit inklusive einfacher Rüst-/Bearbeitungsschritte, Material/Kleinteile zusätzlich; Gesamt brutto = (Stunden × Satz + Material) × 1,19. Einzelstück, bereitgestellte Platte. Anschlussbohrungen inklusive; Plattenbeschaffung, Oberfläche, Versand, Konstruktion und Prüfung nicht enthalten.

| Konzept | Zeit h | Material/Kleinteile netto | Gesamt brutto |
|---|---|---|---|
| A | 0,75–1,5 | 15–35 € | 89–256 € |
| B | 1,5–3 | 30–60 € | 179–500 € |
| C | 2–4 | 40–80 € | 238–666 € |
| D | 2–4 | 30–70 € | 226–655 € |

Kein Angebot, keine behauptete aktuelle Marktpreisliste. Hintergrund zu Kostentreibern: https://instawerk.de/wie-entstehen-die-kosten-bei-der-fraesteilfertigung (Artikel 2021; abgerufen 28.09.2026). Die Projektwerte sind eigene Schätzungen.

## Stabilität

Nur qualitative Konzeptbewertung. B ist der bevorzugte Kompromiss; C hat günstig verteilte Befestigungspunkte. A hängt stark vom unbekannten Original ab. D enthält eine zusätzlich auszulegende Fügezone. Halsquerschnitt, Gewinde, Vorspannung, Auflageflächen und Platte bleiben zu bemessen. Es gibt keine zulässige Last, keine FEM und keine Freigabe. Höhe, Gewicht, Schwerpunkt, Wind-/Stoßlast, Untergrund und freier/fester Stand fehlen.

Beispielgewicht bei angenommener Stahldichte 7.850 kg/m³: volle Platte 150 × 150 × 5 / 8 / 9 mm = 0,883 / 1,413 / 1,590 kg vor Bohrungen. Kein Nachweis gegen Kippen.

Technische Grundlagen: https://www.bossard.com/de-de/wissen/ressourcen/technische-informationen/flaechenpressung/ und https://website-assets.bossard.com/Thread-engagement-length-calculator/thread-engagement-length-calculator-en.html

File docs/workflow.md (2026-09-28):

# Wiederverwendbarer Ablauf: Foto → CAD → Ansicht → Auftrag

Für überschaubare mechanische Bauteile. Kein automatischer 3D-Scan: Aus Fotos wird die Geometrie interpretiert und durch gezielte Messungen abgesichert.

1. Quellen sammeln, Bilder nummerieren, Duplikate erkennen.
2. Zuerst alle getrennten Bauteile inventarisieren und den Modellumfang abgleichen. Dann sichtbare Merkmale markieren und die Funktion in einem Satz festhalten.
3. Nur die für den nächsten Entwurf erforderlichen Maße erfassen.
4. Ein parametrisches Modell und wenige Ansichten erzeugen.
5. Mit dem Original vergleichen, höchstens drei konkrete Fragen stellen, korrigieren.
6. Dasselbe Modell im einfachen Browser-Viewer zeigen.
7. Erst nach Maß- und Funktionsklärung Fertigungsunterlagen ableiten.

## Minimale Projektdaten

| Feld | Bedeutung |
|---|---|
| Bauteil | Name und Zweck |
| Merkmal | Eindeutige Bezeichnung, etwa Rohrlänge oder Schlitzbreite |
| Wert und Einheit | Unbekannt bleibt leer/null |
| Status | Foto-Schätzung, bestätigte Messung oder konstruktive Entscheidung |
| Quelle | Bildnummer, Messangabe oder Entscheidung |
| Unsicherheit | Ablesebereich oder Messunsicherheit, soweit bekannt |
| Revision | Stand, zu dem Angabe und Modell gehören |

Beispielstruktur ohne erfundene Maßzahlen:

```json
{
  "feature": "tube_length",
  "value": null,
  "unit": "mm",
  "status": "unknown",
  "source": null,
  "uncertainty": null
}
```

## Wiederverwenden ohne Umbau

Beim nächsten Bauteil diese Anleitung und die Ordnertrennung übernehmen: sources, parameters, model, exports und gegebenenfalls viewer. Ordner erst anlegen, sobald Inhalt entsteht. Bauteilgeometrie bleibt projektspezifisch. Ein gemeinsamer Viewer oder Exporthelfer wird erst nach praktischer Bewährung extrahiert.

## Qualität von Anfang an

Status und Einheiten sichtbar machen. Modell, Ansichten und Downloads aus derselben Revision ableiten. CAD-Kennwerte im CAD-Kern berechnen. Foto-Schätzungen nie als Fertigungsmaße ausgeben. Neue Infrastruktur nur hinzufügen, wenn sie ein beobachtetes Problem löst.

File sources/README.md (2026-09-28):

# Bildquellen

16 Originaldateien, 14 unterschiedliche Inhalte. 07 ist bytegleich mit 02; 12 mit 03. Prüfsummen beziehen sich auf die Originale, nicht auf die Vorschauen. Vorschauen: maximal 1000 Pixel Kantenlänge, neu als JPEG gespeichert. Originaldateien bleiben außerhalb dieses Repositories verfügbar; sie wurden nicht verändert.

## 10 — Rohrlänge mit Lineal

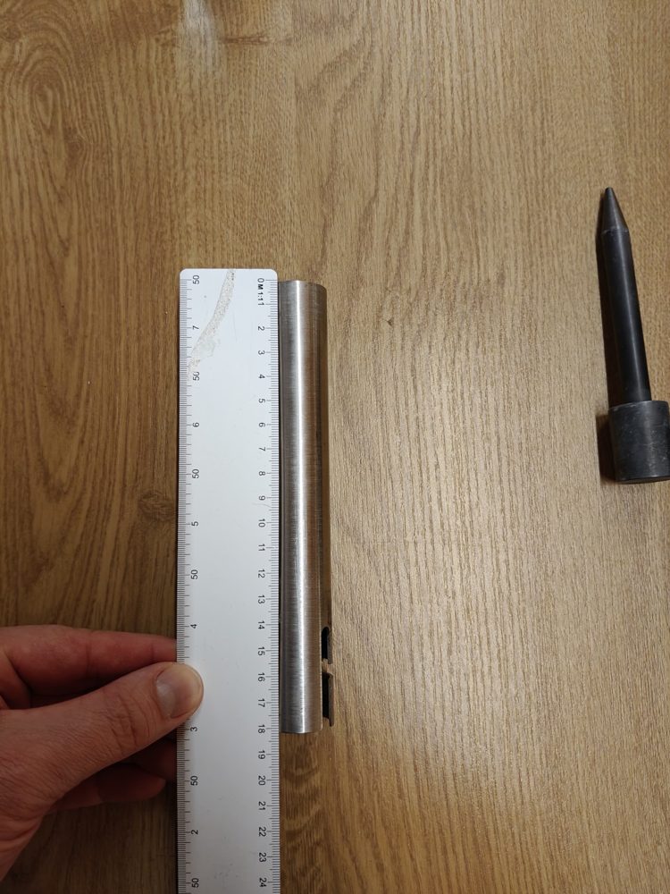
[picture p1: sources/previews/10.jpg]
Rohrlänge mit Lineal


## 11 — Schlitztiefe mit Lineal

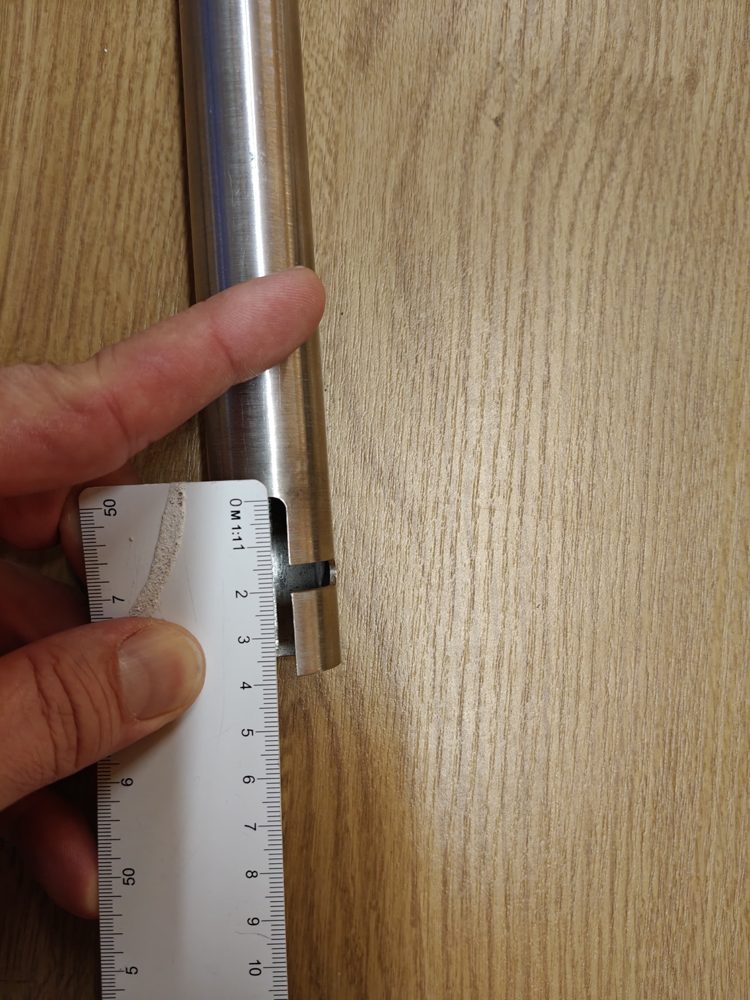
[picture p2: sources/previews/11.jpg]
Schlitztiefe mit Lineal


## 13 — Seitliche Aussparung mit Lineal

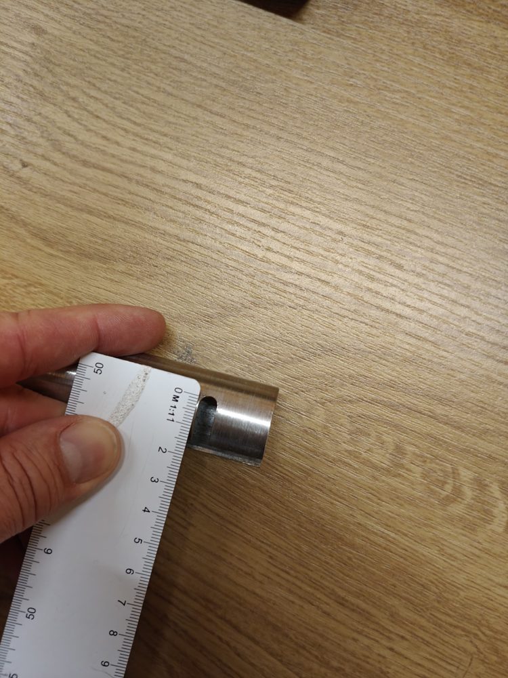
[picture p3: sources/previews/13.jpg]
Seitliche Aussparung mit Lineal


## 14 — Kopflänge mit Lineal

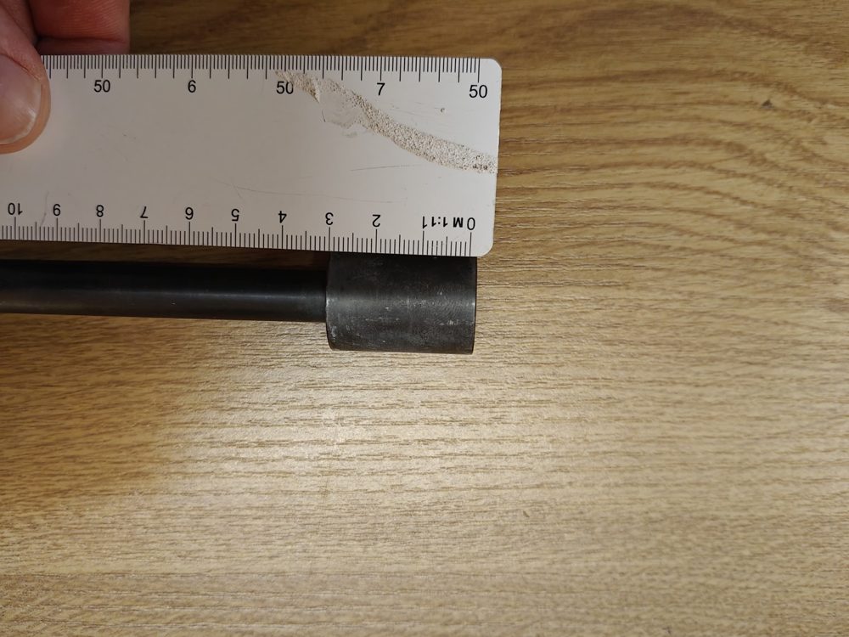
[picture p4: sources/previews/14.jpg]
Kopflänge mit Lineal


## 15 — Rohr und Ausschnitt ohne Gegenstück

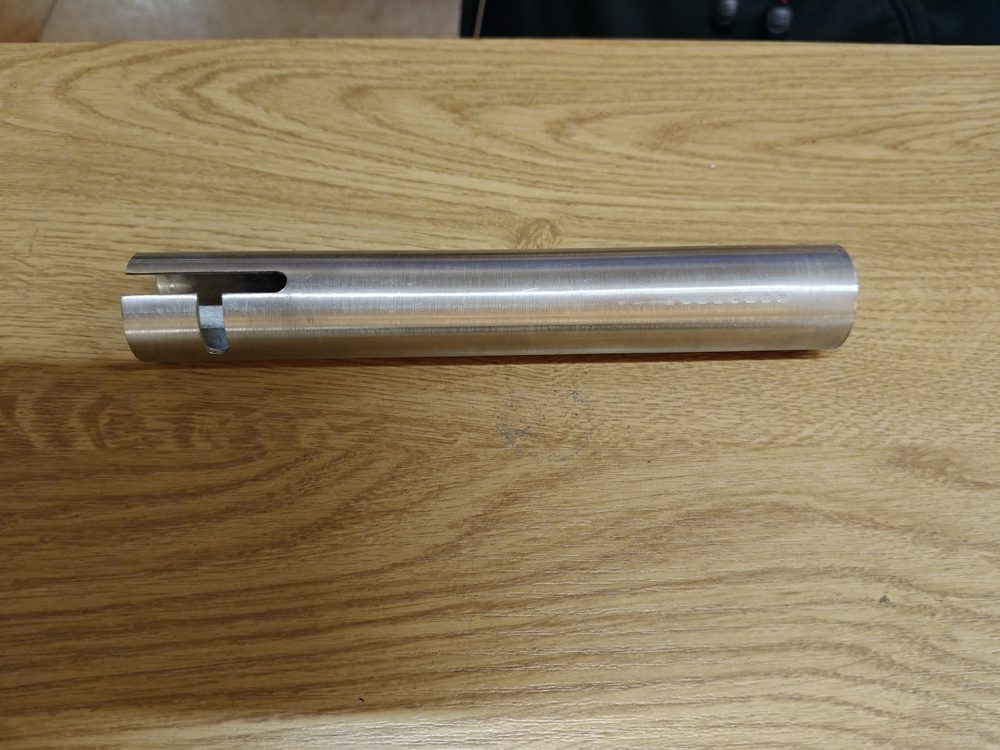
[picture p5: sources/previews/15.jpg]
Rohr und Ausschnitt ohne Gegenstück


## 16 — Kopf mit Lineal aus weiterer Ansicht

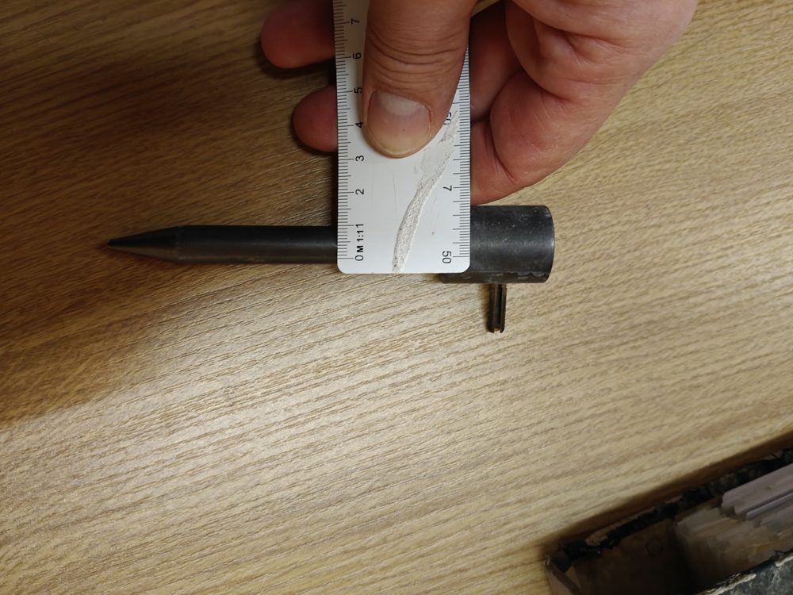
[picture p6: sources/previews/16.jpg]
Kopf mit Lineal aus weiterer Ansicht


## 01 — Montiertes Rohr und Stift

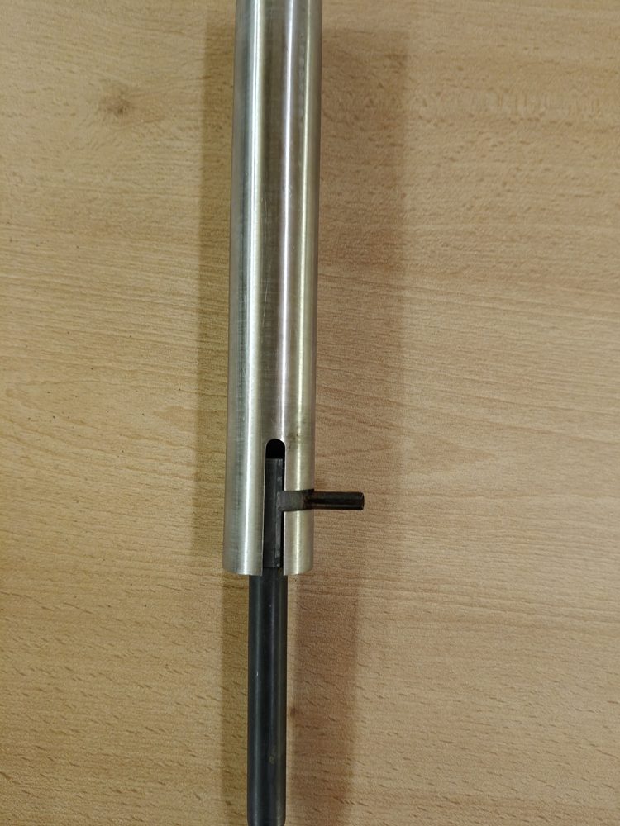
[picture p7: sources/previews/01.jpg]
Montiertes Rohr und Stift


## 02 — Separater Erdspieß

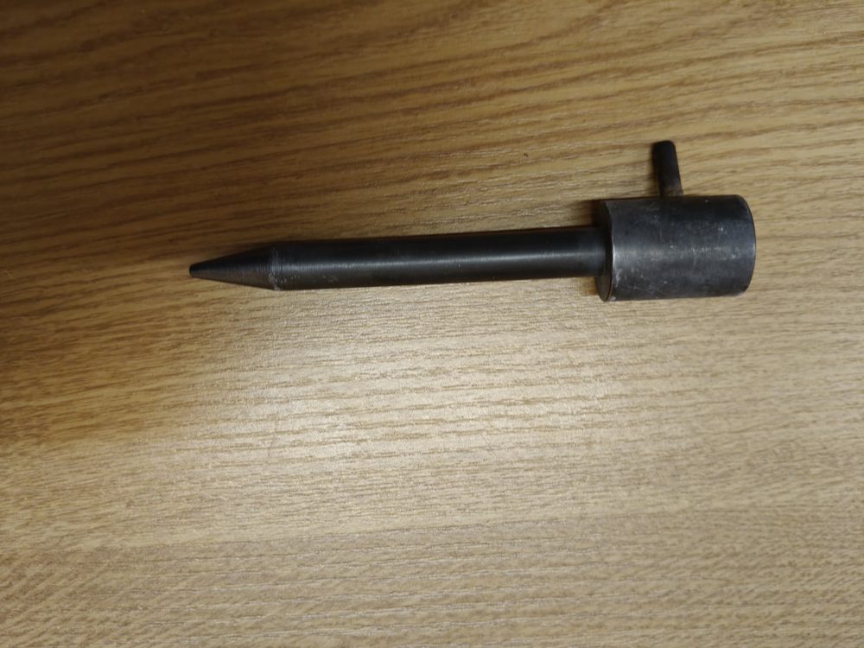
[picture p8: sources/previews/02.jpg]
Separater Erdspieß


## 03 — Kopf mit Lineal

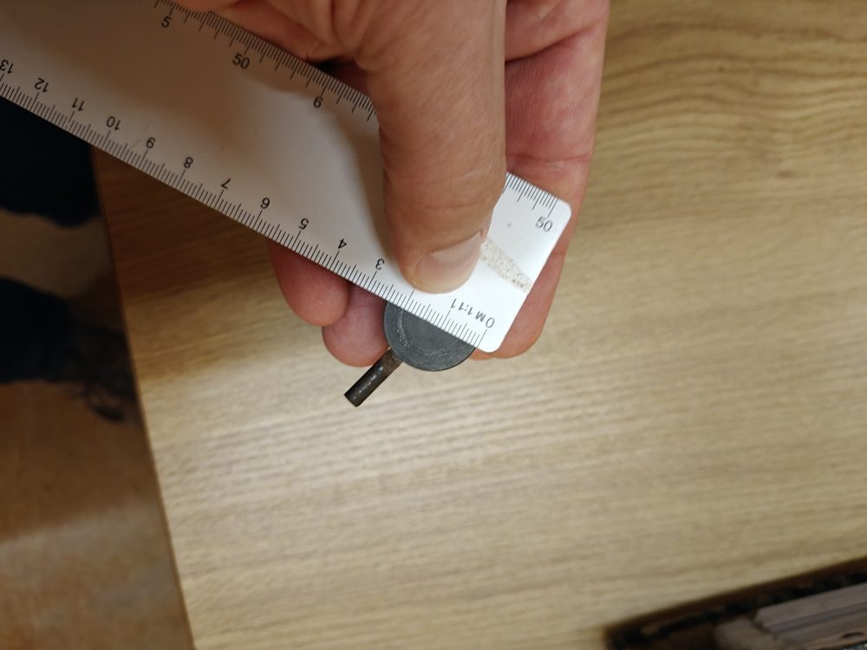
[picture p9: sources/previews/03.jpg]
Kopf mit Lineal


## 04 — Schlitzbereich mit Lineal

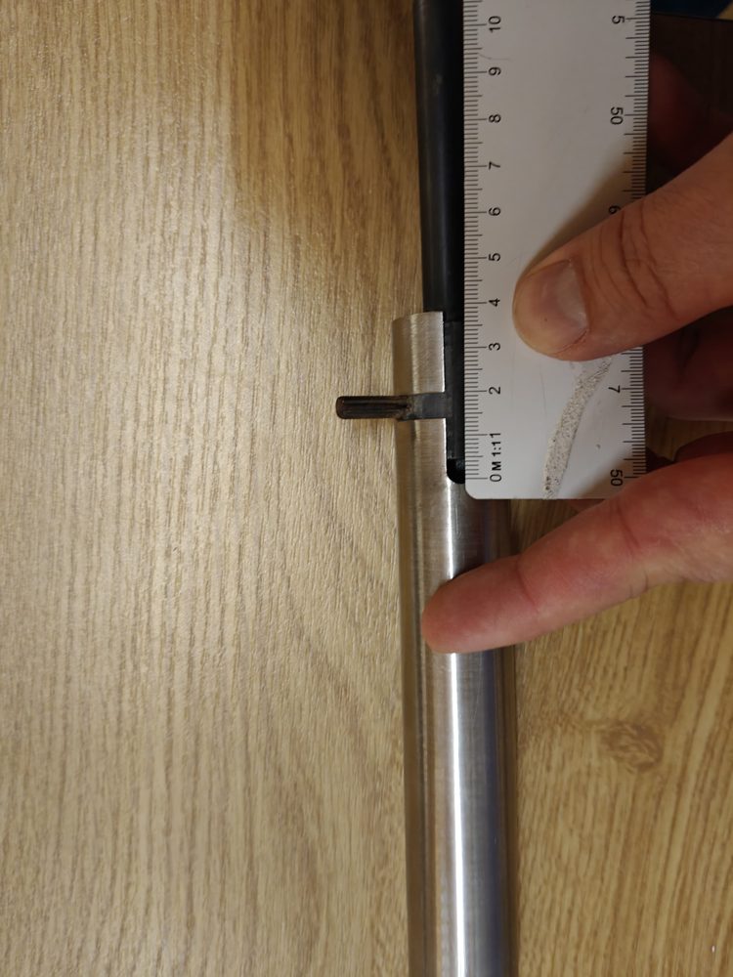
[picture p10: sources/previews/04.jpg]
Schlitzbereich mit Lineal


## 05 — Rohrstirnseite mit Lineal

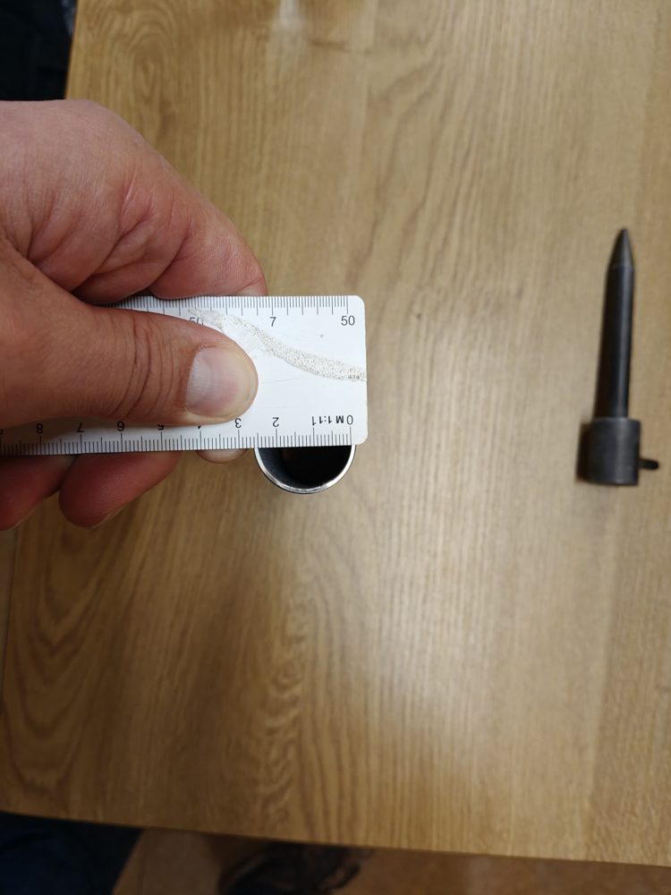
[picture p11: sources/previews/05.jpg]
Rohrstirnseite mit Lineal


## 06 — Rohr und Erdspieß nebeneinander

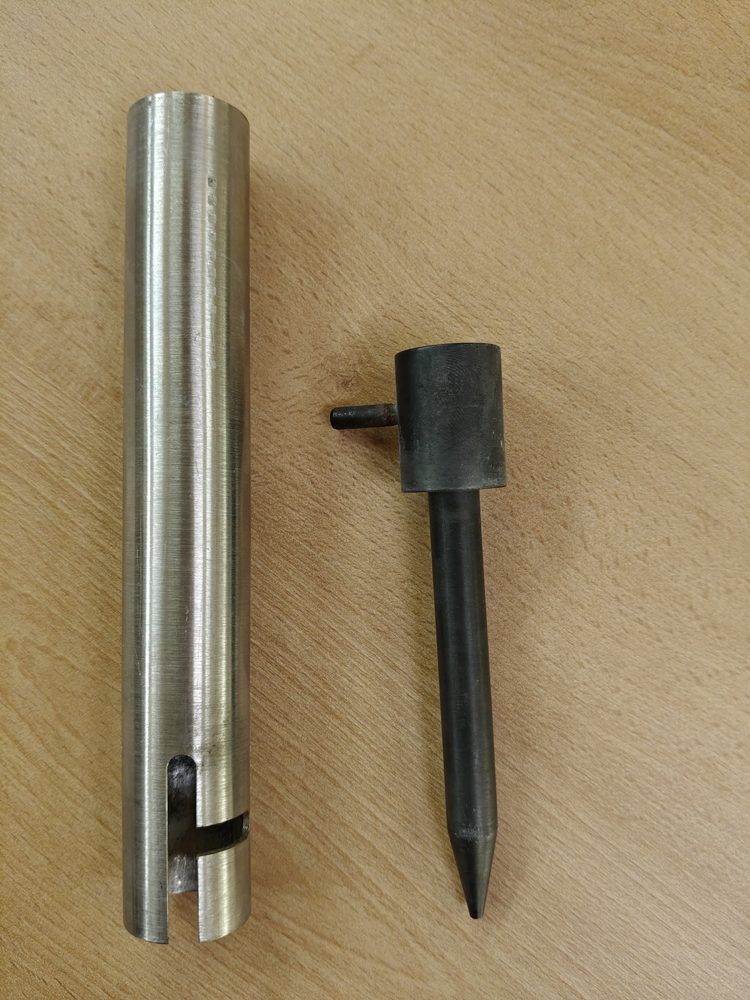
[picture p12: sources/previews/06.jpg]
Rohr und Erdspieß nebeneinander


## 08 — Erdspieß mit Längenvergleich

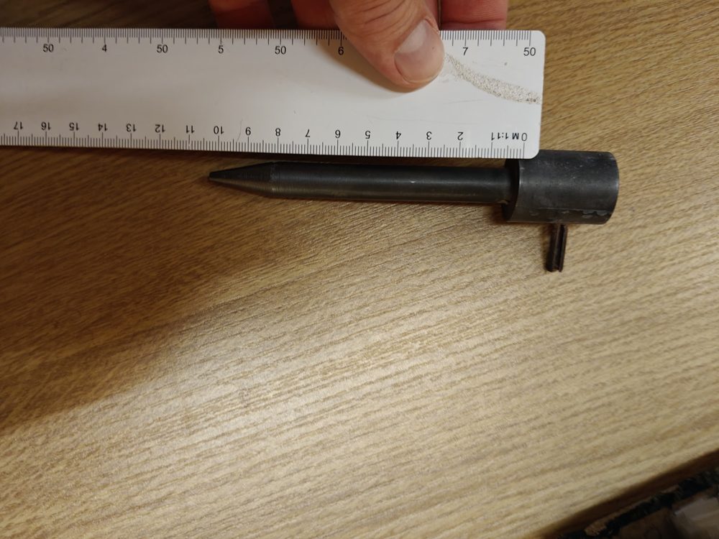
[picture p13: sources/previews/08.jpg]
Erdspieß mit Längenvergleich


## 09 — Radialer Stift mit Lineal

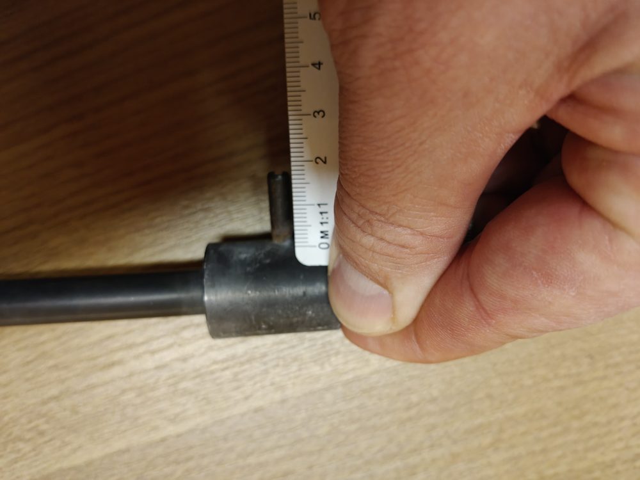
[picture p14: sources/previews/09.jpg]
Radialer Stift mit Lineal


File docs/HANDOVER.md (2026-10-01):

# Übergabe · D-V03 nach Konsistenzaudit

## Desktop-Arbeitsoberfläche · 01.10.2026

Neue gemeinsame Layoutschicht `web/workbench.css`: ab 1100 px dauerhafte, nach Tätigkeit gruppierte Projektnavigation. Bildgestützter Projekteinstieg aus vorhandener CAD-Explosionsansicht, nächster realer Messaufgabe und drei Arbeitsphasen. Fachseiten erhalten eine Abschnittsnavigation; Bauteile, Mechanik und Montage nutzen CAD-Abbildungen mit Verweis zum Viewer. Modell: Szene links, zusammenhängender Inspektor rechts, Nachweise darunter. Die bisher unsichtbare Überschrift der geschlossenen Darstellungsoptionen ist wieder bedienbar. Unter 760 px wird gestapelt; keine zweite Kopie der Modellsteuerung. Preview-Bilder folgen der Plattenwahl. Neue Präsentationsbausteine im Generator `model/desktop-layout.cjs`; Dokumentquellen und bestehende Funktions-IDs bleiben erhalten. Keine CAD-, Materialfestlegungs- oder Bewegungsänderung. `python3 model/test_workbench.py` prüft Navigation, IDs und Abschnittsanker aller neun Seiten. Visuelle Browserprüfung zusätzlich erforderlich; WebGL-Fähigkeit getrennt vom HTML-Layout bewerten.

Stand 28.09.2026. Ausgangscommit der Reparatur: `59661168c681c6fc0ee955d2f77ed9527727616c`. Frühere Übergabetexte sind in Git erhalten. Aktueller Einstieg: README und [Entscheidungskette](entscheidungen-d.md).

## Verbindlich

Nur D, Vollmaterial mit direktem axialem Gewindesackloch; fünf Teile plate/adapter/pin/screw/tube. Kein Bodenunterstand. Keine Buchse/Fügezone, keine Varianten A–C. Repository und Veröffentlichung autorisiert; Händlerkontakt/Bestellung nicht. Deutsch, sichtbare kleine Ergebnisse und regelmäßige Statusmeldungen; nach Abschluss keine laufenden Tasks behaupten.

## Reparaturumfang

- D-V03 als einheitlicher Einstieg, Original D02 und V01 als historische Referenzen; README/Plan/Toolchain/Viewer-Dokumentation bereinigt.
- Gemeinsame Entscheidungskette mit aktueller CAD-Stückliste, ausdrücklich abweichenden Recherchekandidaten, Nachweisen, Tätigkeiten und Abschlusskriterien.
- Plattenzustand über URL und Seitenlinks; Zeichnungs-/STEP-Auswahl unabhängig von WebGL. Keine 8/9-mm-Gesamtkosten vorgetäuscht.
- Animation erklärt die laufende Aktion statt den vorherigen Schritt. Ganzzahlige Schrittwahl zeigt Zielbild. Posefunktion unverändert. Sockelschnitt ohne rotierende Rohr-Halbschnitte; freie Ansichts-/Teilewerkzeuge während Montage gesperrt. Reset und Fehlerzustände bereinigt; reduzierte Bewegung über manuelle Schritte.
- Kostensummen im Text gerundet; exakte Rechenwerte bleiben im JSON. Studie betrifft andere Teile und ist kein Preis des aktuellen CAD.
- Dateihash-Manifest und Prüfung gegen generierte Dokumentseiten/lokale Links. Keine automatische universelle CAD-Parametrisierung behaupten.
- Frontend-Modifikationen ohne neue Modelle nur als spätere Ausbaustufe dokumentiert.

## Unverändert / offen

CAD, STEP, A3 und nominale Bewegungspose bleiben unverändert. Die gespeicherten mechanischen Prüfberichte stammen aus der vorherigen Sitzung. Aktuelle Softwareprüfung erzeugt keinen zusätzlichen Festigkeitsnachweis. Reale Maße, Schraubenkopf, Stiftsicherung, Losdrehen, Werkzeugzugang, obere Fackelschnittstelle und Standfestigkeit müssen physisch bzw. konstruktiv geklärt werden. Keine Fertigungs-/Betriebsfreigabe.

## Fortsetzung

Zuerst Remote-HEAD und Pages prüfen. `docs/viewer-runbook.md` enthält Befehle und Veröffentlichungskriterien. Bilder in `sources/previews/` zuerst nutzen; alte Scratch-Pfade können fehlen. Details zur Originalbewegung, Spiel und Schraubenwirkung: `docs/mechanik-d.md`. Nächste drei Nachweispakete in `docs/entscheidungen-d.md`.

## Softwareprüfung dieser Reparatur

Release-Prüfung: drei Modellidentitäten, generierte Dokumentseiten und lokale Links. 2.103 Posen gegenüber dem Ausgangscommit exakt identisch; ein festgehaltener Hash der 213 nominalen Abtastposen erkennt spätere Bewegungsänderungen. DOM-Integration prüft Plattenwahl und Downloads mit/ohne WebGL, Seitenkontext, Aktionszuordnung, Pause/Reset und reduzierte Bewegung. Dafür wird der Renderer ersetzt; das ist keine visuelle 3D-Prüfung. Der lokale Chromium-Download schlug fehl. Live-Dokumentprüfung folgt nach Veröffentlichung.

## Layoutkorrektur nach Nutzerkritik

Die frühere Karten-/Linkleisten-Erweiterung wurde gestalterisch zurückgenommen. Aktuelle Seiten nutzen `web/design.css` und die gemeinsame Navigation aus `model/site-shell.cjs`. Hauptseite: kurzer Kopf, drei Sprunglinks, Modellarbeitsfläche, danach Zeichnungen und Maße/Dateien. Doppelte Budget-/Montage-/Statuszusammenfassungen entfernt; vollständiger Inhalt bleibt auf den Fachseiten. Darstellungsoptionen sind aufklappbar, Montagebedienung erscheint nur im Modus. Kein klebender Kopf oder klebender Viewer. Bei WebGL-Ausfall wird die vorhandene Zusammenbau-Prüfzeichnung eindeutig als Ersatzansicht gezeigt. CAD und Posen unverändert.

## Separate mobile UX-Vorschau (2026-09-28)

`web/ux.html` bietet Modell / Aufbau / Projekt; `web/ux-review.html` dient der schmalen Browserprüfung. Hauptviewer nicht ersetzt. Konzept, Erweiterungsvertrag und tatsächlicher Prüfumfang: `docs/ux-entwurf.md`. CAD unverändert. Bildfolge mit acht Zielbildern, keine neue kontinuierliche Montageanimation. Mobile Browserrahmen geprüft, reale iOS-/Android-Geräte und WebGL noch offen. Für vollständige Umstellung müssen auch verlinkte Bestandsdokumente ins neue Layout überführt werden.

## Gemeinsame Projektoberfläche · 29.09.2026

Nutzer lehnt auch die Drei-Bereiche-Vorschau ab: vollständige Orchestrierung aller vorhandenen Funktionen beauftragt. Neuer Einstieg `web/projekt.html` mit nächster Tätigkeit und vollständigem Funktionsverzeichnis. Fotos/Maße, Entscheidungen, Modell/Zeichnungen, Bauteile, Mechanik, Montage, Beschaffung und Kosten verwenden die gemeinsame Oberfläche. `docs/projekt-integration.md` dokumentiert Quelle und Verbindung jeder Funktion. Bauteile verbinden Fotos, Kandidaten, Prüfungen, STEP und konkrete Animationsschritte. `web/ux.html` bleibt alter Entwurf; nicht zur Hauptseite machen. CAD und Posen unverändert. Reale Smartphone-Geräte und WebGL in der Cloud weiterhin nicht nachweisbar.

## Szenenwerkzeuge · September 2026

- Bauteilwahl per Liste und 3D-Treffer, Hervorhebung und Verbindungen zu Bauteilangaben, Fotos/Messliste, Beschaffung und Einbauschritt. Die Textauswahl funktioniert auch ohne WebGL.
- Fünf Untersuchungsfragen führen zu Kamerapositionen; Übergänge sind unterbrechbar und bei reduzierter Bewegung unmittelbar.
- Verschiebbarer Y-Schnitt mit Stencil-Schnittflächen; nur Darstellung, keine Änderung an CAD oder Downloads. Während Montage gelten die vorhandenen erklärenden Sockelschnitte.
- Montage hebt das aktive Teil hervor; Richtungspfeile und optionale vorherige Position ergänzen die unveränderte Posefunktion. Keine Rastung ergänzt.
- Technische/Produktdarstellung mit prozeduraler Studioumgebung; automatische oder manuelle Renderqualität. Oberflächen sind Visualisierungen, keine Materialfestlegung.
- Ansichtslink speichert Kamera, Plattenwahl, Teil, Darstellungszustand und pausierten Montageschritt. PNG kann Revision, Plattenstärke und Konzeptstatus enthalten.

Prüfung: DOM-Integration mit realer Three.js-Geometrie/Mathematik und ersetztem Renderer prüft Auswahl, Schnittzustand, Montage, Positionshilfe, Teilen, Reset und Qualität. Nominale Posen bleiben durch bestehenden Regressionstest geschützt. Der Cloud-Browser kann keinen WebGL-Kontext erstellen: Licht, Schatten, Stencil-Kappen und Antialiasing sind dort **nicht visuell geprüft**. Vor visueller Abnahme auf einem WebGL-fähigen Smartphone und Desktop insbesondere Schnitt durch Gewindesackloch, Bauteilauswahl, Touch-Scroll/Drehen und Wiederöffnung eines Ansichtslinks prüfen.
# Zusatzübergabe · One More Thing · 01.10.2026

Aktuell XR-DEMO / 02: vom Nutzer gewählte Vectron-nahe Designstudie. Formreferenz, Abgrenzung und Quellen in `docs/xray-demo.md`. Bronzehaube, Schraubflansch, Silberrahmen, runder Körper und seitliche Anschlüsse ersetzen das Kastengehäuse. Elf Teile-IDs bleiben erhalten; Größen kommen aus den illustrativen Netzen. Alle XR-Exporte nach Geometrieänderung mit `model/render_xray.mjs` neu erzeugen. Revision 01 ist historisch.

`web/one-more-thing.html` ergänzt den separat beauftragten XR-DEMO. Elf fiktive Baugruppen einschließlich Kathode, Anodenteller/Rotormodul und symbolischem Flüssigmetalllager. Modellmontage und Funktionsprinzip sind getrennte steuerbare Erklärabläufe. Alle Maße, Anbieter und Kosten erfunden; keine technische Auslegung. Details und Grenzen: [xray-demo.md](xray-demo.md). D-V03-Geometrie und Montageposen nicht verändern. Nach Änderungen `npm run docs`, betroffene Prüfungen, anschließend Release-Manifest prüfen/erneuern.

## Navigation vereinfacht · 01.10.2026

Gemeinsame Sidebar für alle zehn aktiven Seiten: heller Hintergrund, typografischer Projektkopf ohne Logo-Kachel, keine Statuspunkte, keine abgerundeten Navigationsflächen oder linke aktive Akzentkante. Aktive Links nutzen Schriftgewicht, Kupferton und Unterstreichung; Tastaturfokus bleibt sichtbar. Mobile Navigation bleibt ein natives aufklappbares Menü mit mindestens 48 px hohen Linkzeilen. Gemeinsame Quelle `model/site-shell.cjs`, Darstellung `web/workbench.css` Revision 4; XR-Sonderregel für gefüllte aktive Links entfernt. Modellgeometrie und Funktionen unverändert.

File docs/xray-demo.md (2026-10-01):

# One More Thing · XR-DEMO / 02 · Vectron-nahe Designstudie

## Formwechsel vom 01.10.2026

Auf ausdrücklichen Nutzerwunsch wird die äußere Erscheinung jetzt an der öffentlich abgebildeten Siemens-Healthineers-Vectron-Baugruppe orientiert: bronzefarbene konturierte Haube mit Schraubflansch, silberner Trägerrahmen, kompakter runder Röhrenkörper und seitliche Leitungs-/Anschlussattrappen. Kein Logo, keine Herstellerzugehörigkeit, keine Behauptung einer originalgetreuen Replik. Innengeometrie, Proportionen und Montagebewegungen sind weiterhin eigene schematische Darstellungen. Die Maßanzeigen werden aus den erfundenen Modellnetzen abgeleitet, nicht aus dem Produktfoto gemessen.

Öffentliche Formreferenz: [NAEOTOM Alpha / Full Vectron X-ray power](https://www.siemens-healthineers.com/en-us/computed-tomography/naeotom/naeotom-alpha), dort [Produktabbildung](https://marketing.webassets.siemens-healthineers.com/ddef0cf99f6e35a6/a8002f0892c5/v/ceff17427d70/siemens-healthineers_DI_CT_PCCT_Vectron-tube.jpg). Das Herstellerbild wird verlinkt, nicht als eigene Darstellung oder als Download neu veröffentlicht.

Das öffentliche [SOMATOM-Force-Whitepaper, Abb. 2](https://academy.siemens-healthineers.com/_/en-us/somatom-force--get-two-steps-ahead-with-dual-source-ct/) benennt beim Vectron-Schema unter anderem Flüssigkeitslager, Kathode, Anode, Stator, Ablenkspulen, Elektronenfänger und Wasserkühlung. Das belegt die allgemeine Komponentenbenennung, nicht unsere vereinfachte Baugruppenaufteilung oder Geometrie. Das Flüssigmetalllager bleibt als Symbol gekennzeichnet; keine Spalte, Zusammensetzung oder Betriebsdaten werden übernommen.

Separater Nutzerauftrag vom 01.10.2026: eine fiktive Röntgenstrahler-Demonstration als Beleg für die Übertragbarkeit des Projekt-Workflows. **Kein realer Bauplan, keine Strahlenquelle, keine Fertigungs- oder Betriebsfreigabe.** D-V03 bleibt unverändert.

## Zusammenhängender Ablauf

Menüpunkt → Übersicht → Modell und Erklärmontage → Funktionsprinzip → fiktive Stückliste/Beschaffung → zwei A3-Schemablätter → zurück zur Gartenfackel.

Elf auswählbare Baugruppen einschließlich Kathode, Anodenteller mit Rotor und symbolischem Flüssigmetalllager. Die Erklärmontage verschiebt Baugruppen einzeln; sie ist weder Kollisionsprüfung noch reale Fertigungsfolge. Der separate Funktionsablauf visualisiert Elektronen, Entstehung von Röntgenstrahlung und Wärme sowie die Rolle der Rotation/Lagerung. Farben und Teilchenbahnen sind Symbolik, keine Simulation. Keine Betriebswerte oder reale Lagerauslegung.

Alle Maßzahlen, Anbieter und Preise sind erfunden. Summe 1.065 Demo-Euro pro Satz; keine echte Kostenkalkulation. Keine Händlerkontakte oder Bestellungen.

## Implementierung und Grenzen

- `web/xray-model.js`: gemeinsame illustrative Three.js-Netze, Posen, Metadaten und CPU-Vektorprojektion.
- `model/render_xray.mjs`: reproduzierbare HTML-, SVG-, JSON- und STL-Ausgaben. STL enthält Darstellungsnetze, keine fertigungstauglichen Volumenkörper; bewusst kein STEP.
- `web/xray.js`: Auswahl, Fokussieren, Sichtbarkeit, Transparenz, offener Halbschnitt, Schrittsteuerung/Pause, Ansichtslink und gekennzeichneter PNG-Export.
- `web/xray-principle.js`: separat steuerbarer schematischer Erklärablauf.
- Browser ohne WebGL erhalten dieselben Netze als interaktive CPU-SVG-Projektion. Überdeckungen und Transparenz sind vereinfacht. Reduzierte Bewegung verhindert automatisches Abspielen; Einzelsteps bleiben möglich.
- `npm run check` prüft Datenbezüge, endliche Posen, Sichtbarkeit und Veröffentlichungskonsistenz. Kein Test bestätigt Strahlenschutz, Festigkeit, Herstellbarkeit oder Physik.

## Hintergrundquellen

Zusätzliche Grundlagen für die allgemein erklärten Zusammenhänge; die Formreferenz der Revision 02 ist oben getrennt aufgeführt:

- [Siemens Healthineers Academy: X-ray technology basics](https://academy.siemens-healthineers.com/_/en-us/x-ray-essentials-basics-of-x-ray-technology-job-aid/)
- [Siemens Healthineers OEM: X-ray tubes](https://www.oem-products.siemens-healthineers.com/x-ray-tube)

Quellenstand: 01.10.2026. Keine maßgetreue oder funktionsfähige Nachbildung eines Herstellerprodukts.

## Vorheriger Prüfstand der Revision 01

Revision 02: sämtliche elf Netze und abgeleiteten STL-/SVG-Dateien neu erzeugt. Größenkonsistenz pro Teil und Gesamt-Hüllmaße automatisch geprüft; 45 Montagezustände weiterhin endlich. Zusätzliche Projektionstests prüfen, dass die neue Standardkamera bei 320-/375-Pixel-Seitenbreite das vollständige Modell zeigt. Schemablätter und Explosionsansicht lokal gerendert und visuell geprüft. Keine mechanische Kollisions- oder Herstellbarkeitsprüfung. WebGL-GPU-Abnahme weiterhin offen.

Automatische Prüfungen erfolgreich: elf IDs, 45 endliche Montageposen, Stücklisten-/Beschaffungsanker, isolierte Bauteilwahl, transparente Hülle, SVG-Projektion und unveränderte D-V03-Posen. Vier SVG-Dateien als XML geprüft.

Live-Browser: Desktop-Einstieg, Lagerauswahl/Fokussieren, Lager-Einbauschritt 4 → Kathode Schritt 5, Montage-Start/Pause, Funktionsschritte und Rücksprung zum Anodenteller sowie Ansichtslink-Erzeugung geprüft. Mobile 320-Pixel-Prüfansicht: Schrittwahl und Bedienelemente nutzbar; Kamera nach Prüfung an schmale Szenen angepasst. `web/xray-review.html` stellt echte 320/375/768/1280-Pixel-Browserrahmen bereit, keine Geräteemulation.

Der Cloud-Browser bietet keinen WebGL-Kontext. Visuell geprüft ist deshalb die CPU-Vektor-Ersatzansicht; reale GPU-Beleuchtung/Transparenz und Touch-Gesten auf einem physischen Telefon sind weiterhin nicht abgenommen. Schematische Bewegung ist kein Kollisionsnachweis.

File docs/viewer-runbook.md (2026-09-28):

# D-V03 · Bauen, prüfen, veröffentlichen

Öffentlicher Einstieg: https://jdistlr.github.io/garden-torch-connector/ → `web/projekt.html`. Historisches Original: `web/index.html`. Aktueller Arbeitsstand: [Entscheidungskette](entscheidungen-d.md).

## Dokumente und Oberfläche

- `npm ci` installiert die fixierte Markdown-Abhängigkeit.
- `npm run docs` erzeugt die acht Dokumentseiten einschließlich Projekt, Bauteile und Fotos/Maße aus `docs/*-d.md`.
- `python3 -m http.server 8765 --directory web`; lokal `/variants.html?plate=9` öffnen.
- `web/project-state.js` hält Plattenwahl/URL, Dokumentlinks, PDF/STEP und Vorschau unabhängig von Three.js aktuell. Explizite URL gewinnt vor lokaler Merkhilfe. Keine Modell-Neugenerierung.
- `web/montage-d.js` definiert Posen und Aktionszuordnung. Ganzzahlen sind Zielbilder; Übergänge erklären die nächste Handlung. Änderungen an `stepAt` sind keine Änderungen an `poseAt`.
- `node model/test_montage.mjs` prüft die Handlungszuordnung und die nominalen Rohrposen.

## CAD und geometrische Prüfung

Python-Abhängigkeiten: `python3 -m pip install -r model/requirements.txt`. D-V03: `python3 model/sockel_d.py`, dann `D_PLATE_THICKNESS=5 python3 model/drawings_d.py` (auch 8 und 9). PNG-Vorschauen aus den entsprechenden PDFs erzeugen und vollständig dekodieren/visuell prüfen.

`python3 model/check_motion_d.py` prüft den nominalen Rohrweg aus STEP und schreibt `motion-checks.json` mit STEP-Hashes. `node model/export_assembly_poses.mjs /tmp/torch-poses.json`, danach `python3 model/check_assembly_d.py /tmp/torch-poses.json` prüft die Gesamtmontage. Keine Kraft-/Gewindeflanken-/Schwerkraftsimulation; diskrete Prüfung ist kein lückenloser Bewegungsnachweis.

`python3 model/cost_d.py` reproduziert die abweichende 5-mm-Kandidatenstudie. Nicht als CAD-Stücklistenkosten behandeln.

## Freigabe einer Veröffentlichung

1. Geänderte Inhalte prüfen; bei Geometrie/Posenänderungen auch CAD, Zeichnungen und beide Bewegungsprüfungen erneuern. Kopierte Zahlen in Generator/Parametern/Dokumenten bleiben bis zur vollständigen Parametrisierung eine manuelle Prüfpflicht.
2. `npm run docs`; Browserfälle prüfen: 5/8/9, URL/Seitenwechsel, Downloads ohne WebGL, echte 3D-Funktionen, Fehlerzustand, Schritte/Übergänge, reduzierte Bewegung, mobile Ansicht. Nicht erfolgreich prüfbare Fälle im Übergabetext benennen.
3. `python3 model/check_release.py --write` erstellt nach der Prüfung das Dateihash-Manifest. `npm run check` prüft Modellidentität, Aktionszuordnung, aktuelle HTML-Generierung, lokale Links und Manifestgleichheit. Das Manifest verhindert stilles Dateidriften, ist aber kein mechanischer Nachweis.
4. Commit auf main ohne Force-Push. Vorhandenes GitHub Pages aus Branch/root verwenden. Erfolgreichen Lauf zum neuen Commit und live ausgelieferte geänderte Dateien verifizieren.

## Tatsächliche Grenzen

Rohraufschieben und Drehen sind nominal geprüft, Originalfunktion und Rückdrehsicherung bleiben offen. 50° ist keine eingerastete Endlage. Werkzeug-/Handzugang ist nicht modelliert. Download-Auswahl funktioniert auch bei WebGL-Ausfall; bei vollständig deaktiviertem JavaScript gilt die sichtbare statische 5-mm-Vorauswahl. Keine Frontend-Geometriebearbeitung implementiert.

## Szenenwerkzeuge · September 2026

- Bauteilwahl per Liste und 3D-Treffer, Hervorhebung und Verbindungen zu Bauteilangaben, Fotos/Messliste, Beschaffung und Einbauschritt. Die Textauswahl funktioniert auch ohne WebGL.
- Fünf Untersuchungsfragen führen zu Kamerapositionen; Übergänge sind unterbrechbar und bei reduzierter Bewegung unmittelbar.
- Verschiebbarer Y-Schnitt mit Stencil-Schnittflächen; nur Darstellung, keine Änderung an CAD oder Downloads. Während Montage gelten die vorhandenen erklärenden Sockelschnitte.
- Montage hebt das aktive Teil hervor; Richtungspfeile und optionale vorherige Position ergänzen die unveränderte Posefunktion. Keine Rastung ergänzt.
- Technische/Produktdarstellung mit prozeduraler Studioumgebung; automatische oder manuelle Renderqualität. Oberflächen sind Visualisierungen, keine Materialfestlegung.
- Ansichtslink speichert Kamera, Plattenwahl, Teil, Darstellungszustand und pausierten Montageschritt. PNG kann Revision, Plattenstärke und Konzeptstatus enthalten.

Prüfung: DOM-Integration mit realer Three.js-Geometrie/Mathematik und ersetztem Renderer prüft Auswahl, Schnittzustand, Montage, Positionshilfe, Teilen, Reset und Qualität. Nominale Posen bleiben durch bestehenden Regressionstest geschützt. Der Cloud-Browser kann keinen WebGL-Kontext erstellen: Licht, Schatten, Stencil-Kappen und Antialiasing sind dort **nicht visuell geprüft**. Vor visueller Abnahme auf einem WebGL-fähigen Smartphone und Desktop insbesondere Schnitt durch Gewindesackloch, Bauteilauswahl, Touch-Scroll/Drehen und Wiederöffnung eines Ansichtslinks prüfen.

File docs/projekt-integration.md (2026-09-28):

# Projektintegration · 29.09.2026

Der Nutzer hat die Reduktion auf einen Sockel-Viewer und die Drei-Bereiche-Vorschau verworfen. Ziel ist die gemeinsame Arbeitsumgebung für alle vorhandenen Funktionen. Der neue Einstieg ist `projekt.html`; `ux.html` ist kein aktueller Projekteinstieg.

| Funktion | Erreichbarkeit | Quelle / Zustand |
|---|---|---|
| Übersicht und nächste Tätigkeit | Projektstart | projekt-d.md; keine behauptete physische Erledigung |
| Originalfotos und Messliste | Fotos & Maße, Bauteillinks | measurements.md und sources/README.md; beim Rendern zusammengeführt |
| Festlegungen und offene Entscheidungen | Entscheidungen | entscheidungen-d.md |
| Modell, Schnitt, Transparenz, Explosion, Maße, Sichtbarkeit, PNG | Modell & Zeichnungen | unveränderte D-V03-Geometrien, sockel-d.js |
| Geführte Animation, Schritte, Pause, Tempo | Montage-Link öffnet Modell im Montagemodus | montage-d.js; Posen unverändert |
| Bauteilherkunft, Kandidat und Einbau | Bauteile, Modellseitenleiste | bauteile-d.md; Querverweise auf Originalbeleg und Artikelposition |
| Mechanik und Prüfberichte | Mechanik & Prüfung | bestehende geometrische Nachweise; keine neue Lastprüfung |
| Artikel und Händler | Beschaffung; Anker je Position mit Rückweg zum Bauteil | bestehende Recherche vom 28.09.; keine neue Preisabfrage |
| Mengen und Fertigungsannahmen | Kosten | bestehende 1/5/10-Studie mit abweichenden Teilen; keine 8/9-mm-Gesamtsumme |
| Zeichnungen, STEP und Druck | Modell & Zeichnungen, Bauteile, Dokumentdruck | Plattenwahl über URL und lokale Merkhilfe |

Auf allen neun aktuellen Seiten dieselbe Navigation. Plattenwahl 5/8/9 auf jeder Fachseite, URL gewinnt vor Merkhilfe. Bauteil- und Animationslinks erhalten zusätzliche Parameter. Mobile Tabellen zeigen Feldbeschriftungen ohne horizontalen Leseweg. Viewerwerkzeuge bleiben sichtbar. Modellgesten ausdrücklich aktivieren und beenden, Zoom auch mit Tasten.

Spätere Geometriebearbeitung bleibt zurückgestellt. Nachweise, Angebote und physische Prüfungen werden durch die Projektintegration nicht vervollständigt. Keine Händlerkommunikation.

## Verifikation

27 Kombinationen aus neun Seiten und drei Plattenstärken sowie Zustandswechsel per DOM geprüft. Alle neuen lokalen Sprungziele auf Existenz geprüft. Live: Plattenparameter im Montage-Link, Bauteil → Beschaffung und Rückverweis; mobile Rahmen 320/375/390 ohne horizontalen Inhaltsüberlauf. Desktop-Einstieg visuell geprüft. Cloud-WebGL nicht verfügbar; CAD-Bild und Downloads bleiben nutzbar. Keine reale iOS-/Android-Prüfung. Dokument- und Modellansichten enthalten weiterhin die vollständigen vorhandenen Fachinformationen.

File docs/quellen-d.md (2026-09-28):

# Maßaufnahme und offene Entscheidungen

Alle Längen in mm. Noch keine Maßzahl ist als bestätigt eingetragen.

Aktueller Verwendungszweck: die Originalschnittstelle für D-V03 bestätigen. Schaft und Spitze unten dokumentieren nur den historischen Erdspieß; sie gehören nicht zum neuen Sockel. Neue Sockelparameter und Nachweise: [Entscheidungskette](entscheidungen.html).

## Bezugssystem der Originalmessung (Vorschlag)

A = Stirnfläche am geschlitzten Rohrende; z zeigt von A entlang der Rohrachse zum anderen Ende. Winkelnull = Mitte des Längsschlitzes. Drehrichtung ausdrücklich mit Blickrichtung angeben. Diese Definition vor dem Modellaufbau gemeinsam bestätigen.

| Parameter | Zu erfassendes Maß | Bildhinweis | Status |
|---|---|---|---|
| tube_length | Gesamtlänge des Rohres | 10 | offen |
| outer_diameter | Außendurchmesser, an mehreren Stellen | 05 | offen |
| inner_diameter | Innendurchmesser an ungeschlitztem Ende | 05 | offen |
| slot_width | Breite des Längsschlitzes | 01, 04, 11, 15 | offen |
| slot_total_depth | Abstand von A bis zum entferntesten Schlitzpunkt, einschließlich Rundung | 04, 11 | offen |
| slot_end_radius | Radius des Schlitzendes | 01, 15 | offen |
| branch_z_min / branch_z_max | Beide axialen Begrenzungen der seitlichen Aussparung ab A | 13, 15 | offen |
| branch_angle | Umfangsausdehnung der seitlichen Aussparung, nicht aus schrägem Foto ableiten | 15 | offen |
| head_diameter | Durchmesser des Gegenstückkopfes | 03, 16 | offen |
| head_length | Axiale Länge des Kopfes | 14 | offen |
| shaft_length | Schaft einschließlich Spitze ab Kopfschulter | 08 | offen |
| shaft_diameter | Durchmesser des dünnen Schafts | 08 | offen |
| tip_length | Länge des konischen Endes | 08 | offen |
| pin_diameter | Durchmesser des radialen Stifts | 09 | offen |
| pin_projection | Überstand ab Mantelfläche des Kopfes | 09 | offen |
| pin_axial_position | Abstand Stiftmitte zu eindeutig benannter Kopfstirnfläche | 02, 14 | offen |

Wandstärke nach bestätigten Durchmessern als (Außendurchmesser − Innendurchmesser)/2 ableiten und möglichst direkt gegenprüfen. Slotradius nicht ungeprüft als halbe Schlitzbreite setzen.

## Erste Messrunde

1. Rohrlänge.
2. Außen- und Innendurchmesser, möglichst mit Messschieber.
3. Schlitzbreite und gesamte Schlitztiefe ab A.
4. Beide axialen Kanten der seitlichen Aussparung ab A.
5. Kopf- und Stiftdurchmesser des Gegenstücks.

## Funktionsfragen

- Vorhandenes Teil exakt nachbauen oder verändern?
- Wird der Stift eingeschoben und anschließend verdreht? In welche Richtung, und wie wird unbeabsichtigtes Lösen verhindert?
- Was greift am anderen Rohrende an? Ein Foto der gesamten Fackel-Vorrichtung würde die Schnittstelle klären.
- Besteht Kontakt zu Brennstoff oder relevanter Wärme, oder ist das Rohr nur Teil der Halterung?
- Materialgüte, Oberfläche, Stückzahl und gewünschtes Fertigungsverfahren?
- Welche Kräfte und welches Spiel sind im Betrieb zu erwarten?

Die Linealfotos liefern Hinweise, keine belastbaren Passungsmaße: Perspektive, Nullpunkt und Abstand zwischen Lineal und Bauteil sind zu berücksichtigen.

## Bildquellen und Herkunft

16 Originaldateien, 14 unterschiedliche Inhalte. 07 ist bytegleich mit 02; 12 mit 03. Prüfsummen beziehen sich auf die Originale, nicht auf die Vorschauen. Vorschauen: maximal 1000 Pixel Kantenlänge, neu als JPEG gespeichert. Originaldateien bleiben außerhalb dieses Repositories verfügbar; sie wurden nicht verändert.

### Foto 10 · Rohrlänge mit Lineal

Rohrlänge mit Lineal

### Foto 11 · Schlitztiefe mit Lineal

Schlitztiefe mit Lineal

### Foto 13 · Seitliche Aussparung mit Lineal

Seitliche Aussparung mit Lineal

### Foto 14 · Kopflänge mit Lineal

Kopflänge mit Lineal

### Foto 15 · Rohr und Ausschnitt ohne Gegenstück

Rohr und Ausschnitt ohne Gegenstück

### Foto 16 · Kopf mit Lineal aus weiterer Ansicht

Kopf mit Lineal aus weiterer Ansicht

### Foto 01 · Montiertes Rohr und Stift

Montiertes Rohr und Stift

### Foto 02 · Separater Erdspieß

Separater Erdspieß

### Foto 03 · Kopf mit Lineal

Kopf mit Lineal

### Foto 04 · Schlitzbereich mit Lineal

Schlitzbereich mit Lineal

### Foto 05 · Rohrstirnseite mit Lineal

Rohrstirnseite mit Lineal

### Foto 06 · Rohr und Erdspieß nebeneinander

Rohr und Erdspieß nebeneinander

### Foto 08 · Erdspieß mit Längenvergleich

Erdspieß mit Längenvergleich

### Foto 09 · Radialer Stift mit Lineal

Radialer Stift mit Lineal

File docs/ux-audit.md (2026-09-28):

# UX-/Gestaltungsaudit · 28.09.2026

## Konkrete Regression

Die Desktopansicht vor dieser Korrektur zeigte den Modellbereich erst nach rund 760 px: große Heroüberschrift, separater Statuskasten mit Akzentkante, acht gerahmte Links und danach wieder Karten. Hauptseite und Dokumentseiten hatten verschiedene Navigations- und Typografiesysteme. Das erschwerte den Einstieg und verteilte dieselben Aussagen über mehrere Flächen.

## Korrekturmaßstab

- Eine Hauptnavigation auf allen sechs aktuellen Seiten, aktiver Ort eindeutig; Sprunglinks nur für die drei Arbeitsbereiche der Modellseite.
- Kurzer Seitenkopf. Modell vor langen Erläuterungen, keine zusätzliche Entscheidungskarte vor dem Viewer.
- Flächen durch Abstand, Typografie und dünne Trennlinien gliedern. Keine dekorativen Rahmen, Rundungen, Schatten oder Akzentstreifen um Inhalte und Links.
- Sichtbare Hauptaktionen: Plattenwahl und Montage. Seltener benötigte Anzeigeoptionen gezielt öffnen. Montage-Steuerung nur im Montage-Modus.
- Fachinhalte vollständig auf den passenden Seiten, doppelte Zusammenfassungen von Budget/Stand/Montage von der Hauptseite entfernt.
- Gemeinsame Tabellen, Lesebreite und Druckausgabe. Breite Fachtabellen seitlich scrollbar, nicht die gesamte Seite.
- Kein Sticky-Verhalten. Mobile Bedienelemente mindestens 44 px hoch; sichtbarer Tastaturfokus.
- Ausfallzustand zeigt eine beschriftete bestehende Prüfzeichnung und einen kurzen Hinweis. Keine leere Modellfläche mit großer Fehlerkarte.

## Prüfung und Grenze

DOM-Integration prüft erhaltene Platten-/Download-/Navigations-/Montagefunktion. Modellidentitäten, Posen, generierte Seiten und lokale Links bleiben geprüft. Visuelle Prüfung der veröffentlichten Haupt- und Dokumentseiten im verfügbaren Browser; WebGL dort nicht verfügbar. Daher keine Behauptung einer neuen visuellen Prüfung des gerenderten 3D-Modells. Das Layout und die dokumentierte Ersatzansicht sind getrennt prüfbar.

Keine Geometrie-, Kosten-, Festigkeits- oder Freigabeänderung. Original D02 und Variantenarchiv behalten ihren historischen Darstellungsstand; die sechs aktuellen D-V03-Seiten verwenden das gemeinsame Template.

Nutzerkorrektur zur Farbgebung: zurück zu Weiß, kühlem Hellgrau, dunkler Schrift und sparsamem Blau. Grün aus aktueller Oberfläche sowie Viewer-Hintergrund/Boden entfernt. Materialfarben der CAD-Teile bleiben erhalten.

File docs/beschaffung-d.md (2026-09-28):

# D-V03 – Beschaffungsrecherche

[Gemeinsamer Stand, Stückliste und nächste Entscheidungen](entscheidungen-d.md)

Rechercheabruf: **28.09.2026**. Öffentliche Händlerseiten, keine Kontaktaufnahme und keine Bestellung. Preise sind abgerufene Anzeigen einschließlich ggf. älterer Suchindexstände, keine verbindlichen Angebote oder reservierten Bestände. Vor Bestellung im Warenkorb erneut prüfen. Schwarz ist eine Oberflächenanforderung, keine Werkstoffbestimmung.

## Ergebnis und Kompatibilität

Platte und Rundvollmaterial sind als gewöhnliche Halbzeuge erhältlich. Der geschätzte Kopf Ø24 kann aus Ø25 gedreht werden; nicht einfach Ø25 in ein Rohr mit nominal Ø25 innen stecken. Alternativ Rohr 28×1,5 mit nominal Ø25 innen: außen und Wandstärke ändern sich, daher keine stille Ersetzung des D-V03-Rohrs 27×1. Stift 4×20 ist ein Normteilkandidat, aber **kein identischer Ersatz** für den Konzeptstift 4×21: bei 4 mm Sitz verbleiben 16 statt 17 mm Überstand. Kürzerer Überstand, reale Fase und Sicherung sind neu zu prüfen.

## Artikelmatrix entlang der fünf Positionen

Alle Beträge EUR brutto, außer ausdrücklich anders genannt. „Offen“ heißt: nicht öffentlich verifiziert. Mindestmenge hier bezeichnet die kleinste belegte Verkaufsmenge, nicht eine garantierte Mindestauftragssumme.

| Pos. | Händler / konkreter Artikel | Material und Maße | Preis / Kaufmenge | Lieferung / Privatverkauf / offene Punkte |
|---|---|---|---|---|
| 1 | [Stahl-Shop24 SBL111-7](https://www.stahl-shop24.de/Stahl-Blech-150x150x5mm) | S235JR+N, roh, 150×150×5; Längentoleranz ±1 mm | 5,99 / Platte | Einzelstück im Verbrauchershop; Versand 8,90 je Bestellung, Abholung Crinitzberg nach Bereitstellung; Senkung/Bohrung fehlen |
| 1 | [Blechscout 150×150×5](https://www.blechscout.de/stahlplatte-quadratisch/Staerke-5-mm-69/stahlplatte-150x150-mm-816.html?language=de) | Stahlplatte 5 mm | Preis offen | Artikel im Suchindex gefunden, direkter Abruf fehlgeschlagen; Lieferbedingungen nicht bestätigt |
| 1 | [Stahl24 Zuschnitt](https://stahl24.de/products/stahlblech) | Stahlblech, unter anderem 5/8 mm auswählbar | 150×150-Konfiguration offen | Zuschnitt ohne Mindestmenge beworben; Endpreis/Versand offen. 9 mm nicht in ausgewählter Stärkenliste; nicht durch 10 mm ersetzen |
| 2 | [Stahl-Shop24 SRD111-1](https://www.stahl-shop24.de/Rundstahl-25mm-1000mm) | S235JR+C/+SH, gezogen h9, Ø25×1000 | 10,78 / 1-m-Stab | Verbraucherbestellung; zusammen mit Platte ein Versand. Ablängen, Ø24 drehen, planen, Gewinde und Stiftsitz, schwarze Oberfläche erforderlich |
| 2 | [Stahl-Shop24 ARD109-1](https://www.stahl-shop24.de/Alu-Rundstab-25mm-1000mm) | EN AW-6060 T66, Vollmaterial Ø25×1000 | 17,23 / Stab | Gleiche Versandbasis; Aluminium ist Materialalternative, Gewindetragfähigkeit und Oberfläche nicht freigegeben |
| 2 | [Metallparadies Rundstahl Ø25](https://www.metallparadies.de/rundstahl-25-mm.html) | S235JR warmgewalzt, Wunschlänge | Konfigurationspreis offen | Toleranz/Bearbeitungszugabe beachten; ±0,5 mm im Durchmesser laut Seite. Privatverkauf, Mindestwert und Versand noch prüfen |
| 3 | [RST S-A1-DIN7-M4X20-PAPA](https://www.rst-versand.de/Zylinderstift-M420-A1-DIN7-UNI1707_1) | DIN-7-Kandidat Ø4×20; **Titel A1, Beschreibung A2 widersprüchlich** | 0,17 einzeln / 1,54 für 10 | Verbraucherangebot; 1–3 Tage angezeigt; Versand ab 5,90. Werkstoff vor Auswahl klären. Kein Gewindestift trotz Shopbezeichnung „M4“ |
| 3 | [Theo DIN 7 Ø4×20](https://www.theo-schrauben.de/DIN-7-Zylinderstifte-Form-A-Toleranzfeld-m6-Edelstahl-14305-4-m6x20-200-Stueck) | 1.4305, Form A, m6 | 10,61 für 200 (Suchindex) | Großes Restpaket bei 1/5/10; Versand und Endpreis offen |
| 3 | [Würth 027004 20](https://eshop.wuerth.de/Zylinderstift-ungehaertet-DIN-7-Edelstahl-A4-blank-STI-ZYL-DIN7-UNGEH-M6-A4-4X20/027004%2020.sku/de/DE/EUR/) | DIN 7, A4, Ø4×20, m6 | Preis/VE nach Anmeldung | Nur Gewerbe; kein Privatkundenweg |
| 4 | [NormReich 7991A2-M080X020VISK](https://www.normreich.de/1x-Senkkopfschraube-M8x20-DIN-7991-A2) | A2, M8×20 Vollgewinde, P1,25; dk16, k4,4, SW5 laut Händler | 0,16 einzeln; ab10 ca.0,15/St. | Sofort verfügbar angezeigt; Verbraucherangebot; Versand offen. Festigkeitsklasse A2 allein nicht vollständig spezifiziert |
| 4 | [Norm-genau 100432](https://www.norm-genau.de/Senkkopfschraube-M8x20-Edelstahl-A2-V2A-DIN7991-10-Stk.) | A2, M8×20, DIN7991/ISO10642 angeboten, 700 N/mm² laut Seite | 5,32 für10 **inklusive Versand** | 1–3 Tage angezeigt; Rest9/5/0 bei 1/5/10. Kopfkontur vor Einbau abgleichen |
| 4 | [Dunken 1064210.9820](https://www.dunken.de/schrauben/senkschrauben/din-7991-iso-10642/iso-10642-senkschraube-109-m-8-x-20.html) | Stahl10.9, ISO10642, M8×20 | 0,595 einzeln, ab10 0,1714/St.; Versand7,90 | Korrosionsschutz und Voll-/Teilgewinde offen; angezeigter Liefertermin August ist veraltet |
| 5 | [DOLD / Aluprofile-Express Alu6060-RURO-28x1,5-Z](https://www.aluprofile-express.de/Rundrohr-28x15mm-Aluminium-EN-AW-6060-T66-AlMgSi05-0347kg-m-Zuschnitt-20-6000mm) | EN AW-6060 T66, pressblank, 28×1,5, Zuschnitt20–6000 mm | 5,00/m +0,50/Schnitt +3,00 Logistik angezeigt; 180 mm rechnerisch1,40 vor Logistik/Versand | Verbraucherangebot; 5–6 Werktage angezeigt. 3-Euro-Logistik-Zuordnung und Versand noch im konfigurierten Warenkorb bestätigen |
| 5 | [ATREON Artikel14541](https://www.atreon.de/aluminium-rundrohr-28x1-5--en-aw-6060-/) | AW6060, 28×1,5, Stablänge6m | 25,26/Stab inkl. MwSt. | 3–10 Arbeitstage angezeigt; Zuschnitt, Mindermenge und Langgutversand offen. Für Kleinserie große Restlänge |
| 5 | [IBL arr6060028015](https://shop.ibl-raimund.de/Alu/Rundrohre/Metallbau-AlMgSi0-5-6060/Rundrohre-AlMgSi0-5-6060-F22-ADxWD-28x1-5-mm.html) | AW6060 T66, 28×1,5, Zuschnitt/Restposten | 3,31 bei1m angezeigt, Steuerbasis offen | Restpostenstände August2026 nicht als verfügbar übernehmen; Mindestwert, Privatverkauf und Versand offen |

Die 5-mm-Platte ist damit konkret bepreist. 8-mm-Zuschnitt und insbesondere 9-mm-Platte bleiben Angebotslücken. Vorgebohrte Ankerplatten mit zusätzlichen Löchern sind keine identischen Ersatzteile. Ein Baumarkt-Alurohr 25×1,5 (OBI3324928) hat nur Ø22 innen und passt nicht über den Ø24-Kopf: ausdrücklich ausgeschlossen.

## Regionale Kontaktliste

Für alle folgenden Kandidaten außer ausdrücklich belegten Angaben: Preis, exakte Maße/Legierung am Lager, Mindestauftrag und Fertigung dieser Kleinserie **offen**. Kein Händler wurde kontaktiert. Ein Serviceangebot ist noch keine Zusage für unser Bauteil.

| Region / Anbieter | Kontakt / Adresse | Belegtes Angebot und Rolle | Privat / Abholung / Versand |
|---|---|---|---|
| Nürnberg · JERA | Hahnenbalz35, 90411; +49 911955905-0; nl-nuernberg@jera-metall.de; [Produkte/Service](https://www.jera-metall-nuernberg.de/) | Alu-Stangen, Platten, Edelstahlrohre; [Zuschnitte](https://www.jera-metall-nuernberg.de/bearbeitung/zuschnitte/); Dreh-/Frästeile und Oberflächenservice | Großhandel; Privat/Kleinauftrag und Abholung offen; Lieferung belegt |
| Nürnberg · Herrmann | Gartenstr.4–6,90443;0911263755;info@herrmann-buntmetall.de; [Kontakt](https://www.herrmann-buntmetall.de/kontakt.html) | [Schneide-Center](https://www.herrmann-buntmetall.de/service.html), Stangen/Platten, Kleinmengen ausdrücklich möglich | Privat/Abholung offen; Paket bis2m/40kg, auch Spedition; Preise offen |
| Wendelstein · RACKL | Nibelungenstr.15a,90530;0912929412-0;info@rackl-nuernberg.de; [Service](https://rackl-nuernberg.de/) | NE-Halbzeuge, Sägen ab Einzelstück; Bearbeitung/Beschichtung über Netzwerk | Privat/Abholung offen; Logistik angeboten |
| Forchheim · Prechtel | Daimlerstr.12,91301;0919170530;info@prechtel-gmbh.de; [Kontakt](https://prechtel-forchheim.de/kontakt) | Eisenlager, Befestigungstechnik, Werkzeuge; möglicher Sammelbezug Platte/Rundmaterial/Schraube | Laden/Eisenlager Mo–Fr7–17; Privatstatus, Kleinmenge, konkreter Zuschnitt und Versandpreis offen |
| Herzogenaurach · Metallbau Wein | Nelkenstr.2,91074;09132772689;info@metallbau-wein.de; [Kontakt](https://www.metallbau-wein.de/impressum/) | [Werkstatt](https://www.metallbau-wein.de/) für Metallkonstruktionen, Kleinreparaturen; Fertigungskandidat, kein verifizierter Halbzeugshop | Kleinauftrag, Drehen/Schlitzfräsen, Privatannahme, Abholung/Versand und Preis offen |
| Erlangen · Würth | Am Weichselgarten30,91058;091319330790;nl.erlangen@wuerth.com; [Niederlassung](https://www.wuerth.de/web/de/awkg/niederlassungen/niederlassung.php?branch=500707) | Normteile/Werkzeug, Click & Collect | **Kein Verbraucher-Verkauf.** Deshalb aus privatem Kostenwarenkorb ausgeschlossen |
| Erlangen · HORNBACH | Zum Hutacker6,91056; [Markt/Kontakt](https://www.hornbach.de/mein-markt/baumarkt-hornbach-erlangen/) | Ergänzender Einzelhandelsweg für Werkzeug/Oberfläche; projektgenaue Artikel noch nicht belegt | Privat ja; Abholung/Versand artikelabhängig; keine Zuschnittzusage für Metall |
| Fürth · HORNBACH | Magazinstr.90,90763; [Markt/Kontakt](https://www.hornbach.de/mein-markt/baumarkt-hornbach-fuerth/) | Ergänzender Einzelhandelsweg; kein verifizierter passender Vollmaterialbestand | Privat ja; lokale Verfügbarkeit/Versand offen |

Suchtreffer Tabrizi/Fürth betrifft Kunststoffverarbeitung und wird nicht als Metallquelle geführt. Schrotthändler-Annahme von Privatmaterial belegt keinen Verkauf geeigneter neuer Halbzeuge. Für Fürth wurde daher keine unbelegte passende Metallquelle behauptet.

## Onlinekontakte und Versandbelege

- Stahl-Shop24 / Döhler & Behr, Gewerbepark6–8,08147 Crinitzberg, info@stahl-shop24.de: [Versand8,90 und Abholung](https://www.stahl-shop24.de/Zahlung-und-Versand/).
- RST, Grothues22,48351 Everswinkel,025829029270,info@rst-versand.de: Kontakt und Versand ab5,90 auf Artikelseite.
- NormReich, Im Vorderen Burgfeld14,74348 Lauffen,071332339499: Kontakt auf verlinktem Artikel.
- DOLD, Schleifmattstr.2,77716 Haslach,078329744670,info@aluprofile-express.de: [Kontaktbeleg](https://www.aluprofile-express.de/Online-Widerrufsformular).
- IBL, Benzstr.5,69221 Dossenheim,0622170980-0,u.raimund@ibl-raimund.de: Kontakt auf Artikel.
- Weitere Anbieter: Kontakt über die verlinkten Artikel; fehlende Versandpreise/Abholoptionen bleiben offen.

## Vor einem beauftragten Angebot klären

Werkstoffpaarung einschließlich Korrosion und Wärme; fertige Passmaße nach Oberfläche; Stiftsitz und Sicherung; reale Schraubenkopfkontur; sichere Senkung insbesondere bei5mm; gewünschte Stückzahl und Fertigungsanteil. Für Werkstätten Positionen getrennt angeben: Rohmaterial, Rüsten, Drehen/Planen, Bohren/Senken, Direktgewinde, Stiftsitz, Rohrschlitz, Entgraten, Oberfläche, Montage, Prüfung, Versand und Restmaterialrückgabe. [Kostenmodell](kosten-d.md).

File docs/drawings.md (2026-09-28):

> Historische Originalreferenz, kein aktueller D-V03-Nachweis. Aktuell: [Entscheidungskette](entscheidungen-d.md) und [D-V03](sockel-d.md).

# Klassische technische Prüfzeichnungen D02

Die PDF unter `web/assets/werkstattzeichnungen-D02.pdf` enthält drei A3-Querformatblätter. Ziel ist eine gut lesbare Werkstattdarstellung in vertrauter Zeichenpraxis, keine dekorative Retro-Grafik.

## Darstellungsregeln

- Schwarze Vektorlinien; sichtbare Kanten 0,5 mm, Maßlinien 0,25 mm, Achsen und verdeckte Kanten 0,18 mm.
- Millimeter, geschlossene Maßpfeile, Durchmesserzeichen, Maßhilfslinien, Achsen als Strichpunktlinie, verdeckte Kanten gestrichelt.
- Hauptansichten 1:1; lokale Details ausdrücklich 3:1 bzw. 2:1. Separate Blickrichtungen sind beschriftet. Beim Rohr steht die Ansicht vom linken Ende rechts (Projektionsmethode 1).
- Rahmen, Schriftfeld, Zeichnungsnummern, Revision, Blattzählung, Werkstoff- und Prüfstatus; Zusammenbau mit Stückliste.
- Sämtliche Maße unterliegen dem deutlich sichtbaren Hinweis „unbestätigter Foto-Entwurf“. Keine Maßtoleranz, Passung oder Oberflächenanforderung ist stillschweigend ergänzt.

Historischer Bezug: ISO 128:1982 beschreibt allgemeine Darstellungsgrundsätze technischer Zeichnungen. Die DIN-Media-Ersatzhistorie nennt DIN 406-1:1977-04 und DIN 406-2:1981-08 als Vorgänger der späteren DIN 406-10. Die vollständigen historischen Normtexte wurden nicht für eine Konformitätsprüfung herangezogen. Deshalb wird ausdrücklich keine vollständige Normkonformität nach einer bestimmten Ausgabe behauptet.

Quellen:
- https://www.iso.org/standard/3938.html
- https://www.dinmedia.de/de/norm/din-406-10/1990706

## Neu erzeugen

```sh
python3 -m pip install -r model/requirements.txt
python3 model/build.py
python3 model/drawings.py
```

Der Zeichnungsgenerator nutzt dieselben STEP-Solids und dieselbe Parameterdatei wie der Viewer. Vor dem Zeichnen prüft er Parameter- und Gesamt-STEP-Prüfsummen gegen die Metadaten. Orthogonale Kantenprojektionen stammen aus OCCT mit verdeckter-Kanten-Ermittlung (HLR); Kurven werden für die PDF als fein abgetastete Vektorzüge ausgegeben. Kein Nachzeichnen aus Screenshots.

Die PDF-Erzeugung benötigt zusätzlich DejaVu Sans unter `/usr/share/fonts/truetype/dejavu/`. Der Blattaufbau ist auf die Proportionen D02 abgestimmt. Nach Maßänderungen alle Blätter erneut auf Layout und Maßzuordnung prüfen.

## Prüfung und Grenzen

Drei A3-Seiten, eingebettete Schrift, sichtbare Revisions- und Prüfkennzeichnung, Druckkontrollstrecke 50 mm. Alle Seiten gerendert und visuell geprüft. Einzelteilmaße aus D02; abgeleitete Gesamtlänge 130 als Hilfsmaß geklammert. Der vorläufige Schlitzradius R2,5 ist explizit eine Modellannahme. Die gemeinsame STEP-Datei bleibt unverändert.

Vor Verwendung zur Fertigung sind direkte Messungen, Material, Passungen, Toleranzen, Rauheit, Kanten und Herstellverfahren zu klären. Die Zeichnungen dienen jetzt der gemeinsamen Papierprüfung.

## Direkte Webansicht

Der Viewer enthält eine Werkstattansicht mit drei Blatt-Schaltflächen, Zoom (1 bis 4-fach), Einpassen und einer verschiebbaren Vorschau. Die PNGs sind aus derselben PDF gerendert; zum Drucken die Vektor-PDF nutzen. Nach Neuerzeugung der PDF Vorschauen aktualisieren:

```sh
pdftoppm -scale-to 2200 -png web/assets/werkstattzeichnungen-D02.pdf web/assets/zeichnung-D02
```

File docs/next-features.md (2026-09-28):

# Nächste Ausbaustufen – verbindlicher Arbeitsplan

Aufgenommen am 28.09.2026 nach Nutzerauftrag. Aktuell gewählt: D-V03. Fortschritt siehe unten; reale Freigaben bleiben offen. Keine Bestellung oder Kontaktaufnahme mit Händlern beauftragt.

## 1. Funktion vor Inszenierung prüfen

Nutzerbeschreibung: Rohr auf den schwarzen Kopf schieben, radialen Zapfen im offenen Schlitz führen und Rohr verdrehen, bis der Zapfen in der seitlichen Nut sitzt. Das ist das beabsichtigte Steck-Dreh-Prinzip. Ein selbsttätiges Einrasten ist nicht allein durch die seitliche Nut nachgewiesen.

- Koordinaten und Blickrichtung definieren; Einsteckweg, Drehrichtung und Endlage am Original klären.
- Kollisionsprüfung entlang des gesamten Bewegungswegs, nicht nur in zwei Endlagen. Spiel, Beschichtung und Toleranzen berücksichtigen.
- Axiale Sicherung und Sicherung gegen Zurückdrehen separat prüfen: Anschlag, Hinterschnitt, Rastung oder Vorspannung? Keine nicht vorhandene Rastfunktion animieren.
- Bedienmoment darf die Sockelverschraubung nicht lösen. Klemmung/Losdrehsicherung entsprechend prüfen.
- Sichtbare Abnahme: dokumentierte Bewegungsfolge mit Kontaktstellen und offenen Punkten; praktischer Funktionsversuch am Muster.

## 2. Beschaffungsstückliste auf gängige Teile ausrichten

- Alltagstaugliche Standardhalbzeuge (z. B. handelsübliche Aluminium- oder Stahlrohre, Rundmaterial, Platten) und Normschrauben priorisieren.
- Keine geschätzten Fotodurchmesser als zwingende Beschaffungsmaße behandeln. Falls Ø24/Ø27 etc. nicht günstig verfügbar sind: gesamte Paarung auf verfügbare Abmessungen umkonstruieren, Passung neu prüfen.
- Fachhandel, üblicher Metallhandel und Baumarkt prüfen; Spezialanbieter nur als begründete Ausnahme. Verfügbarkeit nicht pauschal bei „jedem Händler“ behaupten.
- Je Position: Material/Legierung, Abmessung/Norm, Länge/Menge, Kaufteil oder Bearbeitungsteil, mindestens zwei Bezugsquellen wenn möglich, Bruttopreis, Mindestmenge, Versand, Abrufdatum, Ersatzartikel.
- Werkstoffpaarung, Korrosion, Wandstärke, Gewindetragfähigkeit und Fügeverfahren berücksichtigen. Direktes Gewinde im Vollmaterial und Stiftsitz werkstoffgerecht auslegen; keine Buchse beschaffen.
- Eigene Konstruktion von Kaufteilen nur als vereinfachte Darstellung, nicht als Fertigungsauftrag.

## 3. Gesamtkostenrechnung

- Material, Bestellmengen, Reststücke/Verschnitt, Schrauben, Querstift und Beschichtung.
- Zuschnitt, Bohren/Senken, Gewinde, Stiftbohrung und Stiftsicherung, Fräsen des Schlitzes, Nacharbeit und Montage.
- Rüstkosten, Versand pro Lieferant, Mindestbestellwerte, Werkzeuge/Hilfsmittel und Prüfaufwand.
- Stückkosten für 1 / 5 / 10 Stück; Einmalkosten separat. Eigenleistung und beauftragte Werkstatt getrennt.
- Brutto-Gesamtpreis mit klarer Menge; niedrig/mittel/hoch und Preisstand. Angebote von eigenen Schätzungen unterscheiden.

## 4. Montageanleitung

- Explosionsbild mit Positionsnummern entsprechend Stückliste; Werkzeuge und benötigte Teile.
- Reihenfolge: Direktes Sacklochgewinde und Stiftsitz fertigen; Querstift sichern; Auflage prüfen; Adapter auf Platte; Senkschraube von unten einsetzen; nach festgelegtem Verfahren anziehen; Bodenbündigkeit kontrollieren; Rohr aufsetzen und verdrehen; Verriegelung und Stand prüfen.
- Anzugsmoment und Schraubensicherung erst nach Werkstoff-/Schraubenauswahl. Zugang von unten vor dem Aufstellen darstellen.
- Demontage, Korrosionspflege und wiederkehrende Sichtprüfung; druckbare Anleitung und synchronisierte Webschritte.

## 5. Gesamtanimation – Mechanik und Produktwirkung

- Zwei Modi: langsame erklärende Montage mit Pause/Schrittsteuerung und kurze ästhetische Produktdemonstration.
- Szenen: Teile geordnet präsentieren → Massive Aufnahme mit direktem Gewinde und separatem Querstift erklären → Platte zum Verschrauben anheben/umdrehen → Adapter positionieren → Schraube von unten einführen und drehen → Platte plan absetzen → Rohr axial aufschieben → Rohr um Kopf drehen → bestätigte Endlage zeigen → fertiges Produkt ruhig präsentieren.
- Stiftsicherung nicht als magisches Einrasten zeigen; Fertigungs- und Benutzermontage unterscheiden.
- Schnitt/Transparenz gezielt einsetzen, so dass verdeckte Kontakte sichtbar werden. Beleuchtung, Kamerafahrten und Materialdarstellung konsistent halten.
- Animation aus denselben CAD-Teilen, mit validierten Bewegungswegen; keine optischen Tricks zum Verdecken von Kollisionen. Modellannahmen sichtbar kennzeichnen.
- Responsive, touchfähig, reduzierte Bewegung respektieren; Start/Pause, Zeitleiste, Wiederholung, einzelne Schritte. Videoexport als spätere Ausgabe.

## Reihenfolge

Laufende D-V03-Korrektur fertigstellen → Funktionsprüfung und Standardteile-Recherche gemeinsam durchführen → Geometrie auf verfügbare Teile abstimmen → Kosten und Anleitung → Animation auf geprüfter Mechanik. Pro Runde ein sichtbares, nachvollziehbares Ergebnis.

## Ergänzung: regionale und überregionale Recherche in der Breite

Vom Nutzer ausdrücklich gewünscht: Klein- und Großraum Erlangen in Bayern; Suchradius einschließend Fürth, Nürnberg, Herzogenaurach und Forchheim. Parallel überregionale Internethändler. Für jedes benötigte Halbzeug und Normteil konkrete Artikel-/Zuschnittlinks suchen, keine bloße Liste allgemeiner Händlerstartseiten.

Je Händler: Name, Ort/Adresse, Website, belegter Telefon-/E-Mail-Kontakt oder Kontaktseite, Sortiment/Zuschnittmöglichkeiten, Privatkundenverkauf, Mindestmengen, Abholung, Versand. Ungeklärtes ausdrücklich offen lassen. Preis, Verfügbarkeit und Datenblatt pro Artikel mit Abrufdatum. Mehrere Alternativen vergleichen; keine Verfügbarkeit bei jedem Händler behaupten. Kontaktaufnahme, Reservierung und Bestellung erfolgen erst nach gesondertem Auftrag.

Ergebnisformat: Beschaffungsmatrix nach Stücklistenposition plus regionale Kontaktliste, online Artikelalternativen, wirtschaftlicher Warenkorb je Stückzahl und Hinweise auf erforderliche Maßanpassungen. Keine vorschnelle Bestellung aufgrund der unbestätigten D-V03-Konzeptmaße.

## Fortschritt dieser Fortsetzung

- D-V03 öffentlich für5/8/9mm geladen; Teile exakt plate/adapter/pin/screw/tube.
- Nominale Rohrbewegung und Gegenproben: [Mechanik](mechanik-d.md), reproduzierbarer STEP-Prüfbericht.
- Konzeptanimation mit8Schritten, Pause, Zeitleiste, Replay, langsamem Modus und Kurzdemo eingebaut; keine Verriegelungsbehauptung.
- [Beschaffung](beschaffung-d.md): zwei oder mehr Artikelkandidaten je Position; regionale Kontaktliste. 8/9mm-Endpreis, einige Versandwerte und Privatkundenbedingungen weiterhin offen.
- [Kosten](kosten-d.md):1/5/10-Stück-Szenarien einschließlich Restmengen, Eigenleistung und Werkstatt; Schätzungen von Anzeigenpreisen getrennt.
- [Montageanleitung](montage-d.md) mit Werkzeugen, Fertigung, Benutzermontage, Prüfung, Demontage und Pflege, druckbar als HTML.
- Noch zu tun: reale Maße und Funktion, Rückdrehsicherung, Stiftsitz, Werkstoffe/Oberfläche, reale Schraubenkopfkontur, belastbare Angebote, Stand-/Belastungsnachweis. Keine Fertigungsfreigabe.

## Konvergenz nach Audit · aktueller Vorrang

Die [Entscheidungskette](entscheidungen-d.md) führt den aktuellen Arbeitsstand und die nächsten realen Nachweise. Darstellung und Downloads bleiben D-V03; Kandidaten bleiben getrennt, bis ihre Kompatibilität geprüft ist. Keine visuelle Fertigstellung als mechanische Freigabe behandeln.

## Später beauftragt, jetzt ausdrücklich zurückgestellt

Frontend-Modifikationen ohne neue Modellgenerierung: zunächst Umfang definieren (Ansicht/Materialdarstellung gegenüber maßverändernder Vorschau). Temporäre Vorschau, Rücksetzen und Vergleich anbieten. Maßänderung muss bestehende Prüfwerte als nicht anwendbar kennzeichnen; keine unveränderten STEP/PDF als Vorschau-Export ausgeben. Reale CAD-Neuberechnung und erneute Prüfung bleiben getrennte Vorgänge. Noch nicht implementiert.

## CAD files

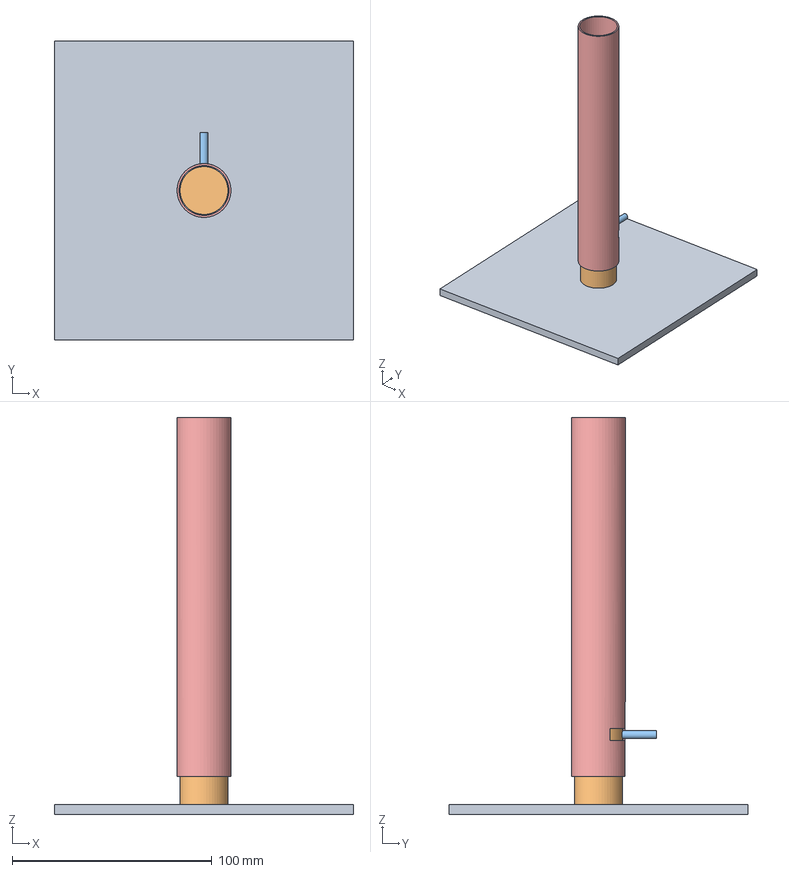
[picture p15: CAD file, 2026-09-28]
web/assets/sockel-d/assembly-5.step
150.0 x 150.0 x 199.0 mm

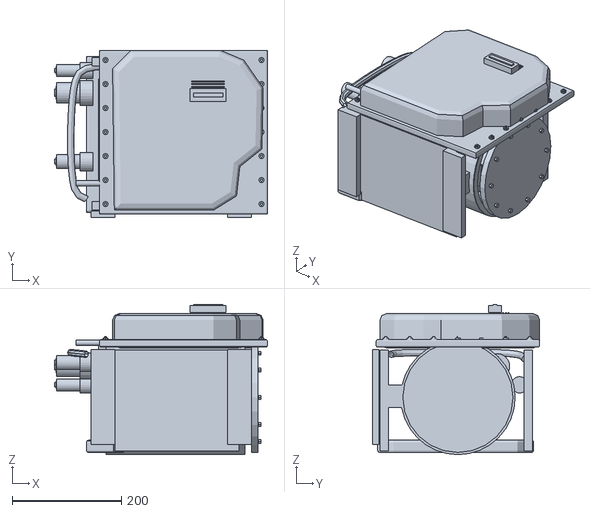
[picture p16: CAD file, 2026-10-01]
web/assets/xray-demo/assembly.stl
390.5 x 307.0 x 275.5

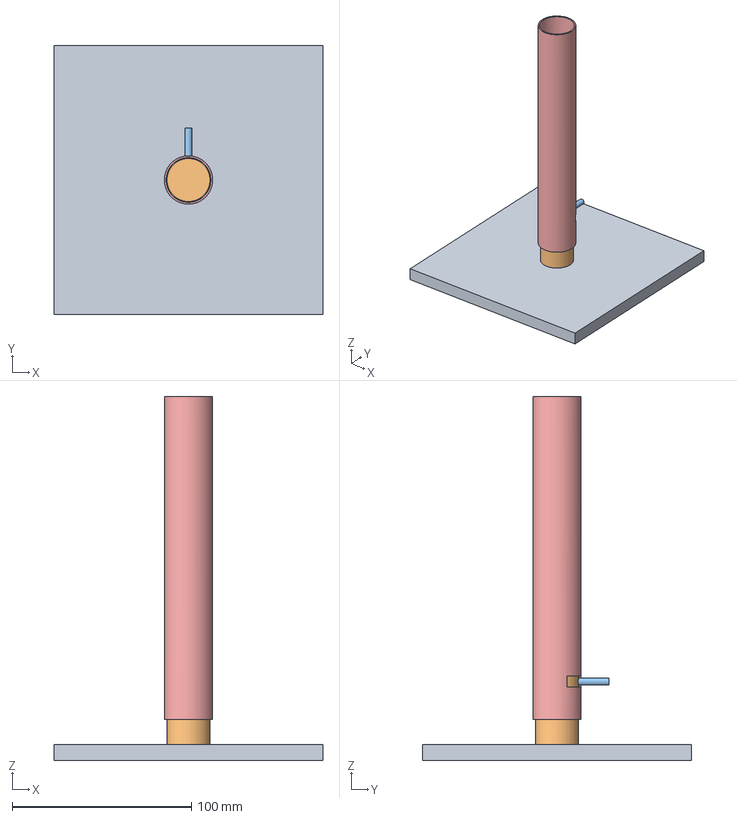
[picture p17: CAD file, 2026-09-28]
web/assets/sockel-d/assembly-9.step
150.0 x 150.0 x 203.0 mm

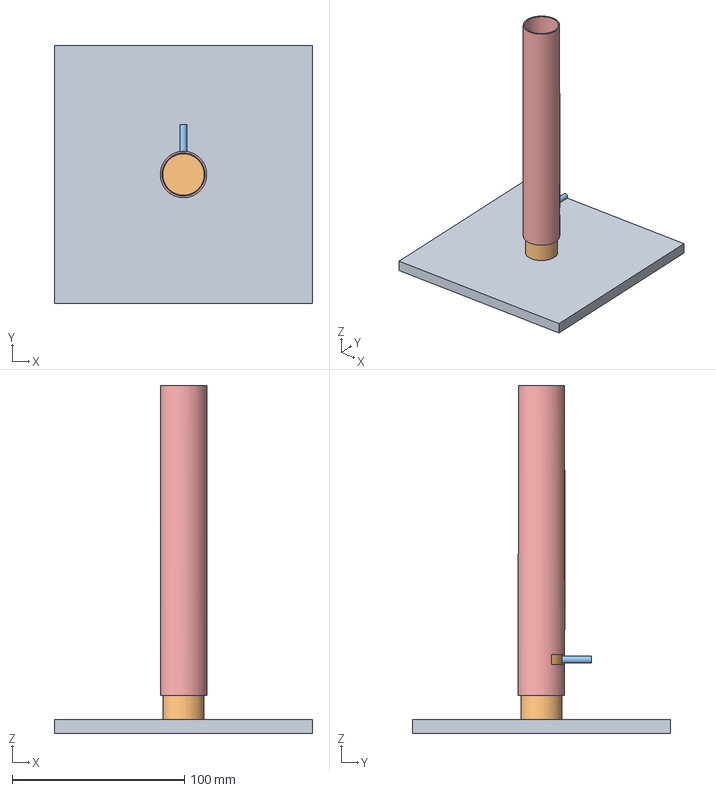
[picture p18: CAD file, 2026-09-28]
web/assets/sockel-d/assembly-8.step
150.0 x 150.0 x 202.0 mm

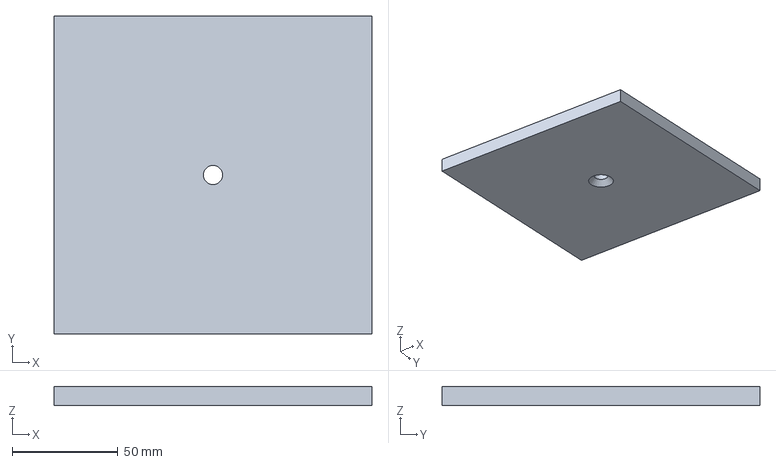
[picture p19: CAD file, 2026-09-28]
web/assets/sockel-d/plate-9.step
150.0 x 150.0 x 9.00 mm

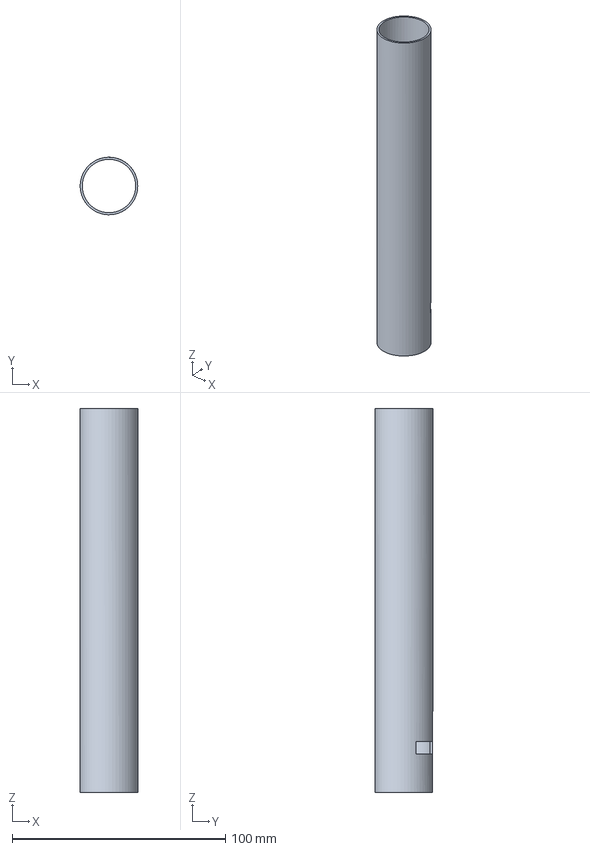
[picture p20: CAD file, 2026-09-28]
web/assets/tube-draft.step
27.0 x 27.0 x 180.0 mm

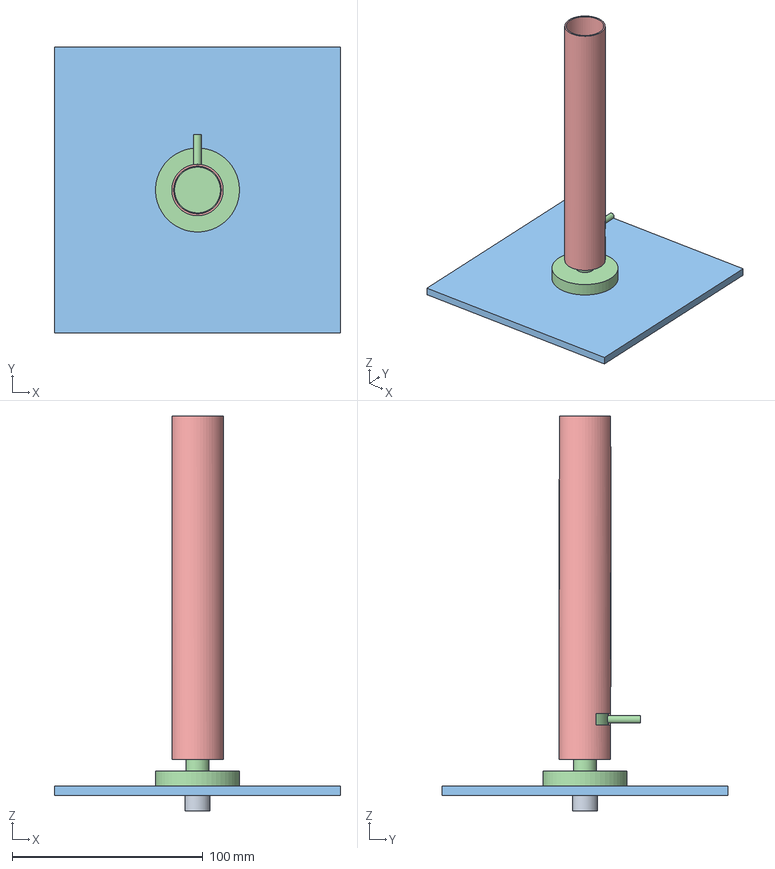
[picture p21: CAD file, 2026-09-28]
web/assets/variants/B-concept.step
150.0 x 150.0 x 207.0 mm

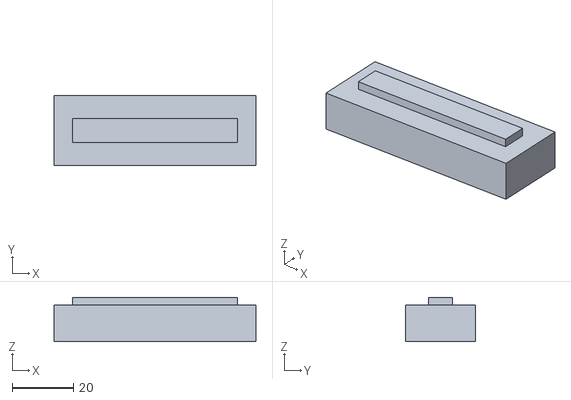
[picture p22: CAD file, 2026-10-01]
web/assets/xray-demo/window.stl
66.0 x 23.0 x 14.5

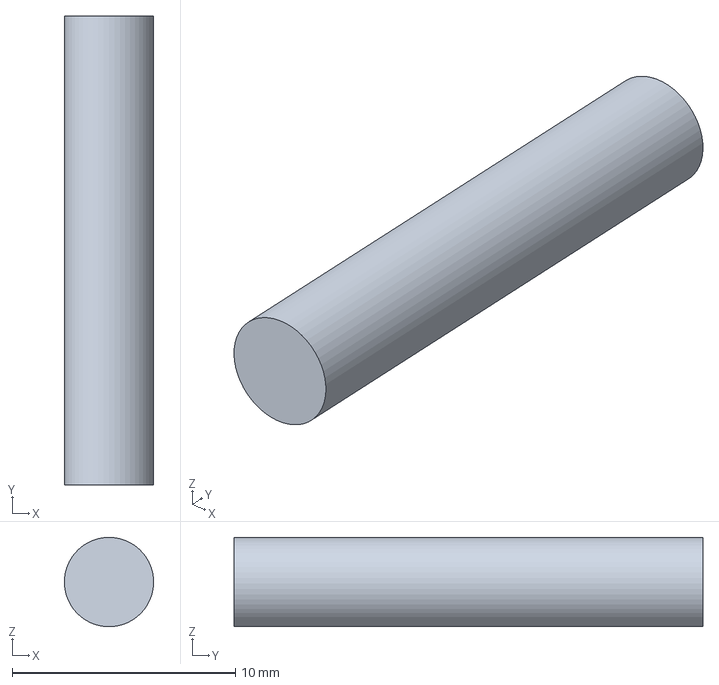
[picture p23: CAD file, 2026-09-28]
web/assets/sockel-d/pin-9.step
4.00 x 21.0 x 4.00 mm

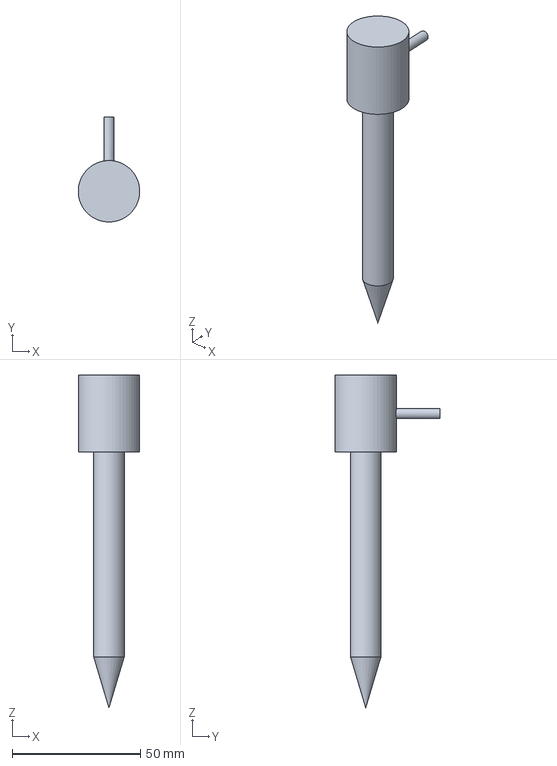
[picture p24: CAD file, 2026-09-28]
web/assets/spike-draft.step
24.0 x 41.0 x 130.0 mm

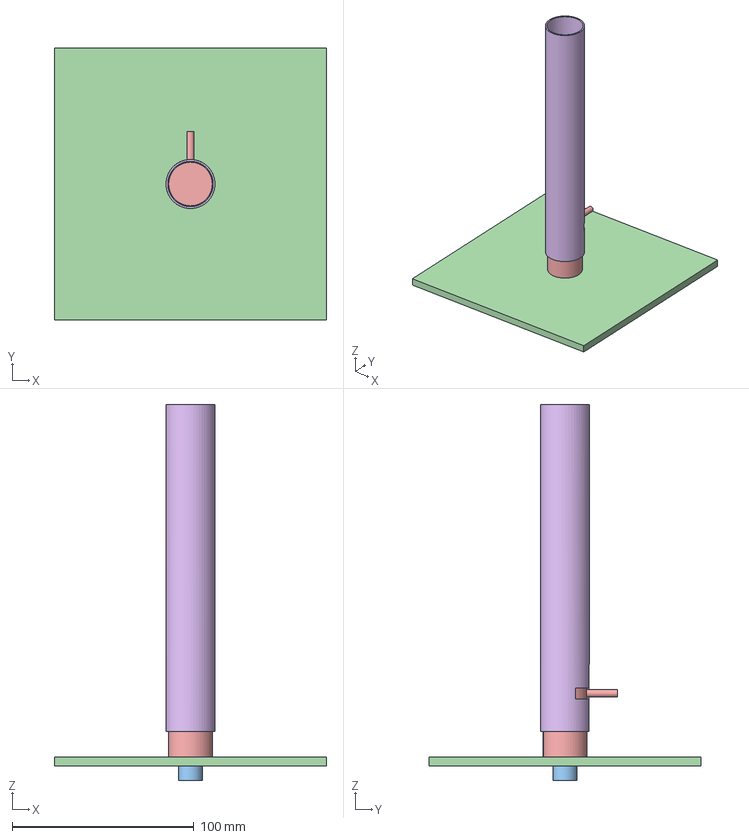
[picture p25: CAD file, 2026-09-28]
web/assets/variants/D-concept.step
150.0 x 150.0 x 207.0 mm

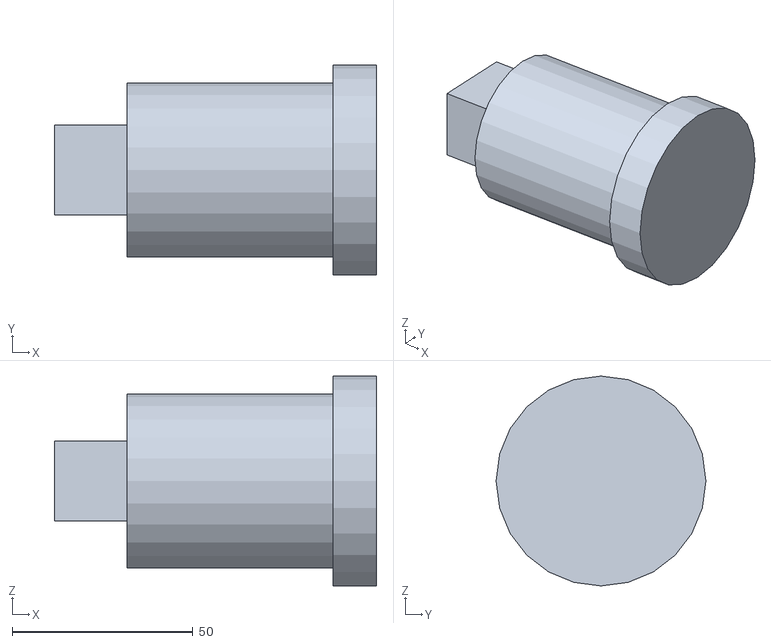
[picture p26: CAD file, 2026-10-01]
web/assets/xray-demo/cathode.stl
89.0 x 58.0 x 58.0

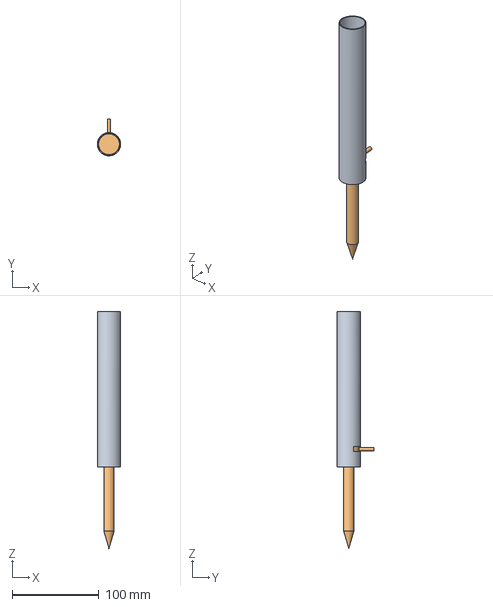
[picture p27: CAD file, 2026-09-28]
web/assets/connector-draft.step
27.0 x 42.5 x 274.0 mm

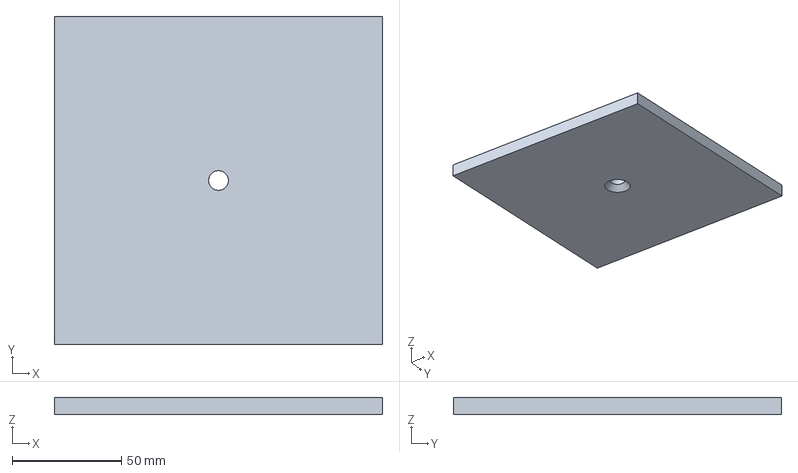
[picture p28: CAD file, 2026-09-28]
web/assets/sockel-d/plate-8.step
150.0 x 150.0 x 8.00 mm

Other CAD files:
web/assets/variants/A-concept.step
web/assets/xray-demo/cover.stl
web/assets/sockel-d/tube-5.step
web/assets/variants/C-concept.step
web/assets/sockel-d/adapter-5.step
web/assets/sockel-d/adapter-8.step
web/assets/sockel-d/adapter-9.step
web/assets/sockel-d/pin-5.step
web/assets/sockel-d/pin-8.step
web/assets/sockel-d/plate-5.step
web/assets/sockel-d/screw-5.step
web/assets/sockel-d/screw-8.step
web/assets/sockel-d/screw-9.step
web/assets/sockel-d/tube-8.step
web/assets/sockel-d/tube-9.step
web/assets/xray-demo/anode.stl
web/assets/xray-demo/base.stl
web/assets/xray-demo/bearing.stl
web/assets/xray-demo/carrier.stl
web/assets/xray-demo/cooler.stl
web/assets/xray-demo/endcap.stl
web/assets/xray-demo/envelope.stl
web/assets/xray-demo/housing.stl

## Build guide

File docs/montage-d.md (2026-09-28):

# Montage- und Prüfanleitung D-V03

[Gemeinsamer Stand, Stückliste und nächste Entscheidungen](entscheidungen-d.md)

Stand 28.09.2026 · **Konzeptanleitung, keine Fertigungs- oder Betriebsfreigabe.** Für kalte, unbeladene Bauteile. Fackel/Brennstoffbehälter, oberer Anschluss und Standsicherheit sind noch nicht ausgelegt. Die Nummern entsprechen Viewer und Stückliste.

## Teile und Vorbereitung

| Pos. | Teil / Menge | Vor Einbau prüfen |
|---|---|---|
| 1 | Grundplatte150×150×5/8/9;1 | Stärke, Ebenheit, gratfreie Unterseite, mittige Bohrung/Senkung passend zu realer Schraube |
| 2 | Massive Aufnahme;1 | Planfläche, fertiger Außendurchmesser, direktes Sacklochgewinde, ausreichende wirksame Gewindelänge |
| 3 | Radialer Stift;1 | Durchmesser, Überstand, Sitz und verbindlich festgelegte Sicherung |
| 4 | Senkschraube;1 | Gewinde, Länge inklusive Kopf, Kopfkontur, Festigkeitsklasse, Werkzeugaufnahme |
| 5 | Geschlitztes Fackelrohr;1 | Innenmaß/Ovalität, Schlitz und Abzweig, Gratfreiheit, oberer Fackelanschluss |

Benötigt: Messschieber, Tiefenmessmittel, Richtkante und Fühlerlehre, passende Einspann-/Montageauflagen, zum Kaufteil passender Innensechskantschlüssel (KandidatSW5), geeignetes Drehmomentwerkzeug nach festgelegtem Anziehverfahren, Markierstift und Reinigungstuch. Stiftmontagewerkzeug und Schraubensicherung hängen von der noch offenen Auslegung ab. Kein geratenes Drehmoment anwenden.

## Fertigung – von der Benutzermontage trennen

1. Werkstoff und Oberfläche festlegen. Rohmaterial ablängen; Aufnahme drehen/planen. Fertigmaße nach Beschichtung beurteilen.
2. Axiales Gewindesackloch nach Werkzeug-/Werkstoffvorgaben herstellen. **Die glatte Ø8-CAD-Hülle ist kein Kernlochmaß.** Kernloch, Bohrspitze, Auslauf, Spanraum und vollständige tragende Gewindelänge festlegen; anschließend reinigen und prüfen.
3. Radialen Stiftsitz herstellen. Stift entsprechend festgelegtem Verfahren einsetzen und gegen Wandern sichern. Das Modell mit4mm Sitz benennt keine freigegebene Presspassung. Bloßes Einstecken genügt nicht als Sicherungsnachweis.
4. Platte bohren und für das konkrete Kaufteil senken. Nicht allein nach dem idealisierten Kopf nacharbeiten. Kopf muss im fertig beschichteten Zustand vollständig oberhalb der unteren Plattenebene bleiben.
5. Rohr ablängen, Längsschlitz und seitliche Aussparung fertigen, sämtliche Schnittkanten entgraten. Geometrieänderungen durch andere Standardhalbzeuge gemeinsam nachprüfen.
6. Oberfläche herstellen; Gewinde, Kontakt-/Passflächen und Stiftsitz nach vereinbartem Beschichtungsplan behandeln. Gewinde und Schlitz dürfen nicht durch Beschichtung zugesetzt werden. Vor Montage vollständig aushärten lassen.

## Acht Schritte wie in der Animation

1. **Vorbereiten:** Teile anhand Positionen sortieren. Platte auf geeigneten Auflagen fixieren, damit von unten Zugang besteht. Die animierten35mm sind nur eine Darstellungshöhe, keine Werkzeugfreiraumvorgabe.
2. **Stift prüfen:** Gesicherten Stift der fertig bearbeiteten Aufnahme kontrollieren. Im Viewer wird seine radiale Einsetzrichtung separat erklärt; daraus folgt kein Sicherungsverfahren.
3. **Aufnahme aufsetzen:** Saubere Planfläche mittig auf die Platte setzen. Vollmaterial mit direktem Innengewinde; keine zusätzliche Buchse einsetzen.
4. **Verschrauben:** Schraube von unten zuerst von Hand ansetzen. Aufnahme gegen Mitdrehen halten. Erst nach Freigabe von Schraube/Werkstoff/Vorspannung nach festgelegtem Verfahren anziehen. Sicherstellen, dass die Spitze nicht im Sackloch anschlägt; geometrische Überdeckung ist nicht gleich tragende Gewindelänge. Kontrollstrich zwischen Aufnahme und Platte anbringen.
5. **Absetzen:** Auf ebener Prüffläche absetzen. Richtkante über den Schraubenkopf führen; kein Kontakt/Überstand, kein Kippeln durch Grat oder Beschichtung. CAD-Ziel0,2mm Rückstand ist kein gemessener Istwert.
6. **Ausrichten:** Offenen Rohrschlitz mittig zum Stift ausrichten. Aufnahme und Platte festhalten.
7. **Aufschieben:** Ohne Verkanten axial absenken, bis der Stift den seitlichen Abzweig erreicht. Bei Klemmen stoppen; nicht mit Kraft oder Hammer weiterbewegen.
8. **Verdrehen und prüfen:** Im aktuellen Modell von oben gegen den Uhrzeigersinn. Am Original Richtung bestätigen. Animation endet bei50° vor dem Modellanschlag≈55,8°. Nicht auf65° zwingen. Axiales Spiel prüfen, nicht unkontrolliert belasten. **Zurückdrehen ist frei; es gibt keine bestätigte Rastung.** Aufnahme darf dabei nicht mitdrehen.

## Prüfprotokoll vor Freigabe

| Prüfung | Soll / Beurteilung | Ist / Datum / Prüfer |
|---|---|---|
| Reale Werkstoffe und Kaufteile identifiziert | Belege und vollständige Spezifikation vorhanden | offen |
| Gewinde, Stiftsitz, Anziehverfahren freigegeben | Keine unbelegte Passung/Vorspannung | offen |
| Unterseite auf Richtkante | Kein Schraubenüberstand; ebene Auflage | offen |
| Schraubenspitze / Sackloch | Kein Grundkontakt; ausreichende tragende Gewindelänge | offen |
| Steck-Dreh-Weg wiederholt | Kein Klemmen; Stift wandert nicht; Winkel/Spiel erfasst | offen |
| Sockel-Kontrollstrich | Keine Relativdrehung bei beiden Bedienrichtungen | offen |
| Rückdrehsicherung | Fehlend → vor Betrieb klären | offen |
| Standprüfung mit vollständiger Fackel | Lasten/Untergrund und Prüfmaßstab vorher festlegen | offen |

## Lösen und Pflege

Fackel vollständig abkühlen lassen. Rohr abstützen, Aufnahme festhalten, bis zur Schlitzöffnung zurückdrehen und senkrecht abziehen. Bei Schwergängigkeit Ursache prüfen. Zum Lösen der Sockelschraube Platte wieder sicher anheben, Aufnahme halten und Werkzeug von unten ansetzen. Vor erneutem Aufbau Stiftsitz, Schlitzränder, Korrosion, Risse, Gewinde, Beschichtung, Kopfversenkung und Kontrollstrich prüfen. Lockere oder beschädigte Teile nicht weiter verwenden. Sicherungsmittel nach Herstellervorgabe erneuern, falls ein solches später festgelegt wird.

[Mechanische Herleitung](mechanik-d.md) · [Beschaffung](beschaffung-d.md) · [Kosten](kosten-d.md)

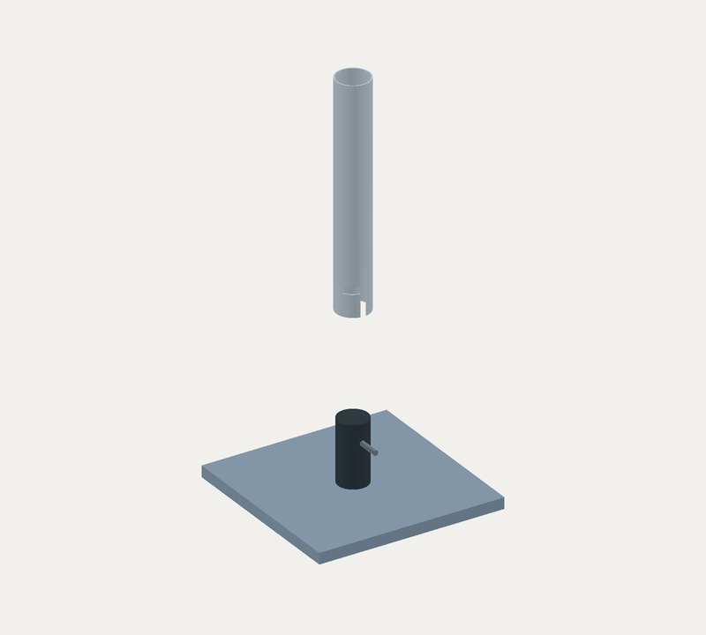
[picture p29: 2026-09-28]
web/assets/ux/step-4-9.png

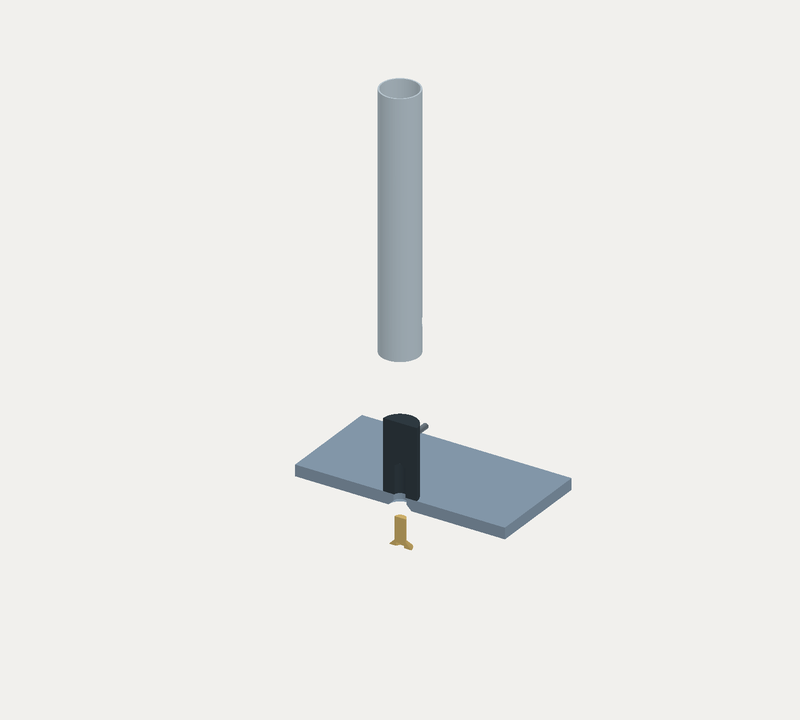
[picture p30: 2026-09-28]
web/assets/ux/step-2-8.png

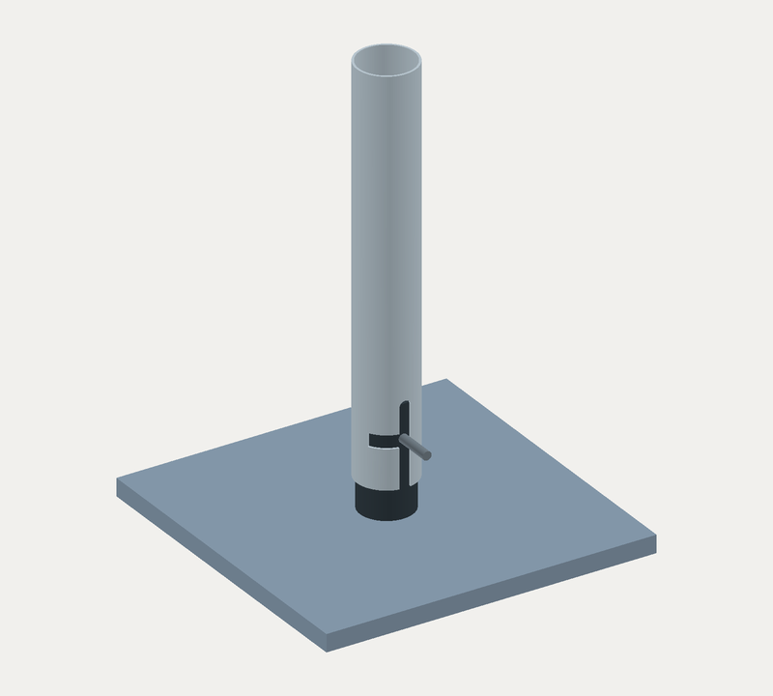
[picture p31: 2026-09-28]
web/assets/ux/assembly-8.png

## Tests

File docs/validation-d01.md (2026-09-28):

> Historische Originalreferenz, kein aktueller D-V03-Nachweis. Aktuell: [Entscheidungskette](entscheidungen-d.md) und [D-V03](sockel-d.md).

# Prüfung D01

28.09.2026: CadQuery 2.7.0 erzeugt einen gültigen Solid. STEP wieder eingelesen; Volumenabweichung unter 1e-8 relativ.

Browsermesh: 1448 Dreiecke. Nach Zusammenführung identischer Positionen (Rundung auf 1e-5 mm) alle Kanten mit zwei angrenzenden Dreiecken. Netzvolumen 14433,129 mm³ gegenüber CAD 14440,782 mm³; relative Abweichung 0,053 %. Dies beweist keine maximale Oberflächenabweichung oder Fertigungstoleranz.

Chromium/Playwright: Modell geladen, keine JavaScript-Laufzeitfehler; Schlitzdetail, Transparenz, Kantenumschaltung und Fotoauswahl betätigt. Desktop 1440×1100 und mobile Fenstergröße 390×844 geprüft, kein horizontaler Seitenüberlauf. Screenshots visuell geprüft. Keine Prüfung auf echtem iPhone/Safari.

Direkte Maße, Material, Passung und Drehrichtung bleiben unbestätigt. Seitenzweig vereinfacht. Keine Fertigungsfreigabe.

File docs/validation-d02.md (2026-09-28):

> Historische Originalreferenz, kein aktueller D-V03-Nachweis. Aktuell: [Entscheidungskette](entscheidungen-d.md) und [D-V03](sockel-d.md).

# Prüfung D02

- Zwei gültige CAD-Solids; gemeinsamer STEP-Rückimport erhält zwei Solids und Volumen (relative Abweichung < 1e-8).
- Keine Überschneidung in illustrativer Montagelage; reale Passung und Verriegelung bleiben ungeprüft.
- Geschlossene Browsermeshes nach Zusammenführen identischer Randpunkte (1e-5 mm Raster). Degeneriertes Dreieck an der Kegelspitze beim Export entfernt.
- Mesh-Volumenabweichung zum CAD: Rohr 0,0530 %, Gegenstück 0,0439 %.
- Browserprüfung: Desktop und 390 px, keine JavaScript-Fehler oder horizontales Überlaufen. Ansichten, Transparenz, Kanten und Fotoauswahl geprüft.
- Alle 16 Modellparameter bleiben Foto-Schätzungen. Schwarz ist die beobachtete Farbe, keine Werkstoffangabe.

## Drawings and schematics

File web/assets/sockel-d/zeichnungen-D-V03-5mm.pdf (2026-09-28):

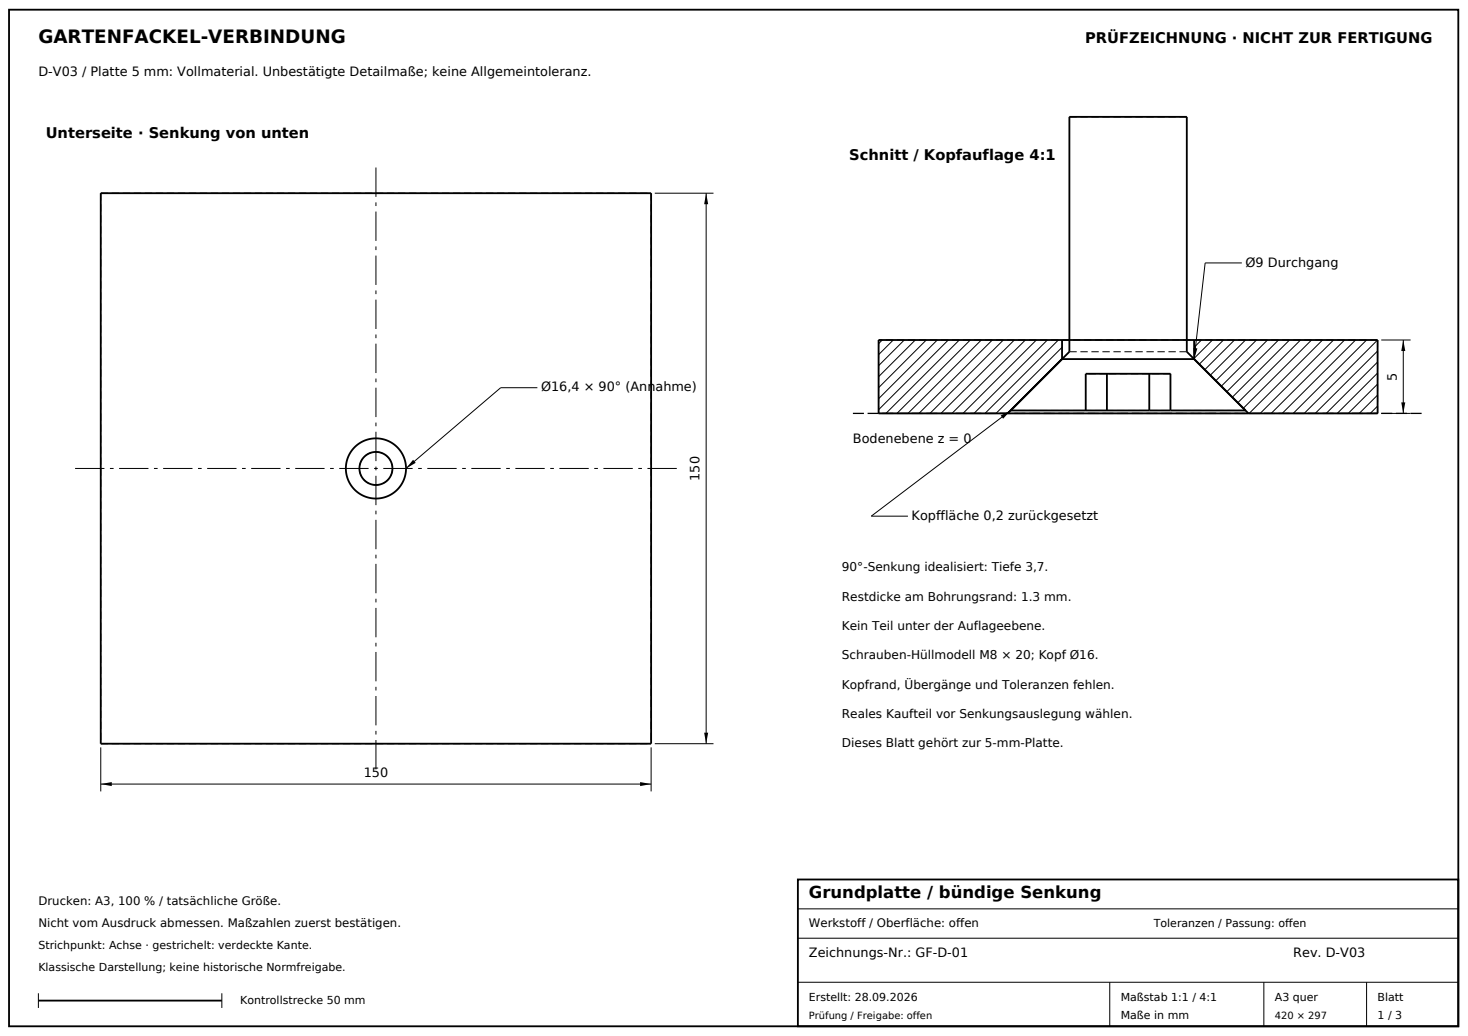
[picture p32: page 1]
GARTENFACKEL-VERBINDUNG; PRÜFZEICHNUNG · NICHT ZUR FERTIGUNG; Werkstoff / Oberfläche: offen; Toleranzen / Passung: offen; Zeichnungs-Nr.: GF-D-01; Rev. D-V03; Erstellt: 28.09.2026; A3 quer; Blatt; Kontrollstrecke 50 mm; Ø16,4 × 90° (Annahme); Schnitt / Kopfauflage 4:1; Bodenebene z = 0; Kopffläche 0,2 zurückgesetzt; Ø9 Durchgang

D-V03 / Platte 5 mm: Vollmaterial. Unbestätigte Detailmaße; keine Allgemeintoleranz.

Unterseite · Senkung von unten

90°-Senkung idealisiert: Tiefe 3,7.

Restdicke am Bohrungsrand: 1.3 mm.

Kein Teil unter der Auflageebene.

Schrauben-Hüllmodell M8 × 20; Kopf Ø16.

Kopfrand, Übergänge und Toleranzen fehlen.

Reales Kaufteil vor Senkungsauslegung wählen.

Dieses Blatt gehört zur 5-mm-Platte.

Grundplatte / bündige Senkung

Drucken: A3, 100 % / tatsächliche Größe.
Nicht vom Ausdruck abmessen. Maßzahlen zuerst bestätigen.

Strichpunkt: Achse · gestrichelt: verdeckte Kante.

Klassische Darstellung; keine historische Normfreigabe.

Maßstab 1:1 / 4:1
Maße in mm

Prüfung / Freigabe: offen

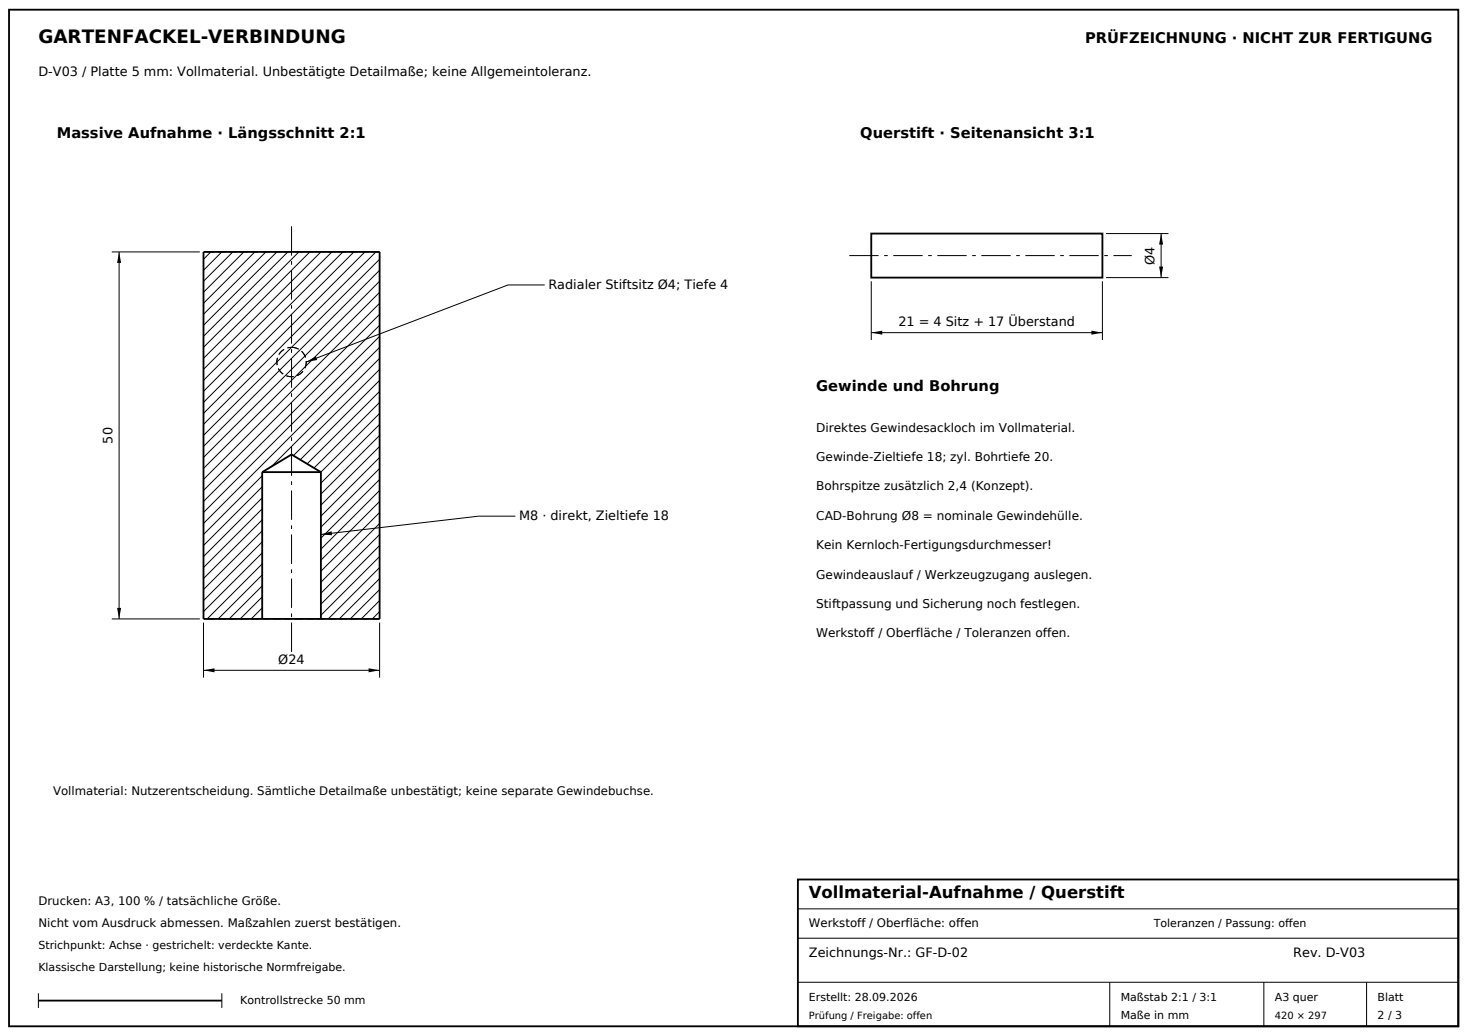
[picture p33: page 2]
Werkstoff / Oberfläche: offen; Toleranzen / Passung: offen; Zeichnungs-Nr.: GF-D-02; Rev. D-V03; Maßstab 2:1 / 3:1; M8 · direkt, Zieltiefe 18; Querstift · Seitenansicht 3:1; 21 = 4 Sitz + 17 Überstand

D-V03 / Platte 5 mm: Vollmaterial. Unbestätigte Detailmaße; keine Allgemeintoleranz.

Massive Aufnahme · Längsschnitt 2:1 50

Radialer Stiftsitz Ø4; Tiefe 4

Gewinde und Bohrung

Direktes Gewindesackloch im Vollmaterial.

Gewinde-Zieltiefe 18; zyl. Bohrtiefe 20.

Bohrspitze zusätzlich 2,4 (Konzept).

CAD-Bohrung Ø8 = nominale Gewindehülle.

Kein Kernloch-Fertigungsdurchmesser!

Gewindeauslauf / Werkzeugzugang auslegen.

Stiftpassung und Sicherung noch festlegen.

Werkstoff / Oberfläche / Toleranzen offen.

Vollmaterial: Nutzerentscheidung. Sämtliche Detailmaße unbestätigt; keine separate Gewindebuchse.

Vollmaterial-Aufnahme / Querstift

Drucken: A3, 100 % / tatsächliche Größe.
Nicht vom Ausdruck abmessen. Maßzahlen zuerst bestätigen.

Strichpunkt: Achse · gestrichelt: verdeckte Kante.

Klassische Darstellung; keine historische Normfreigabe.

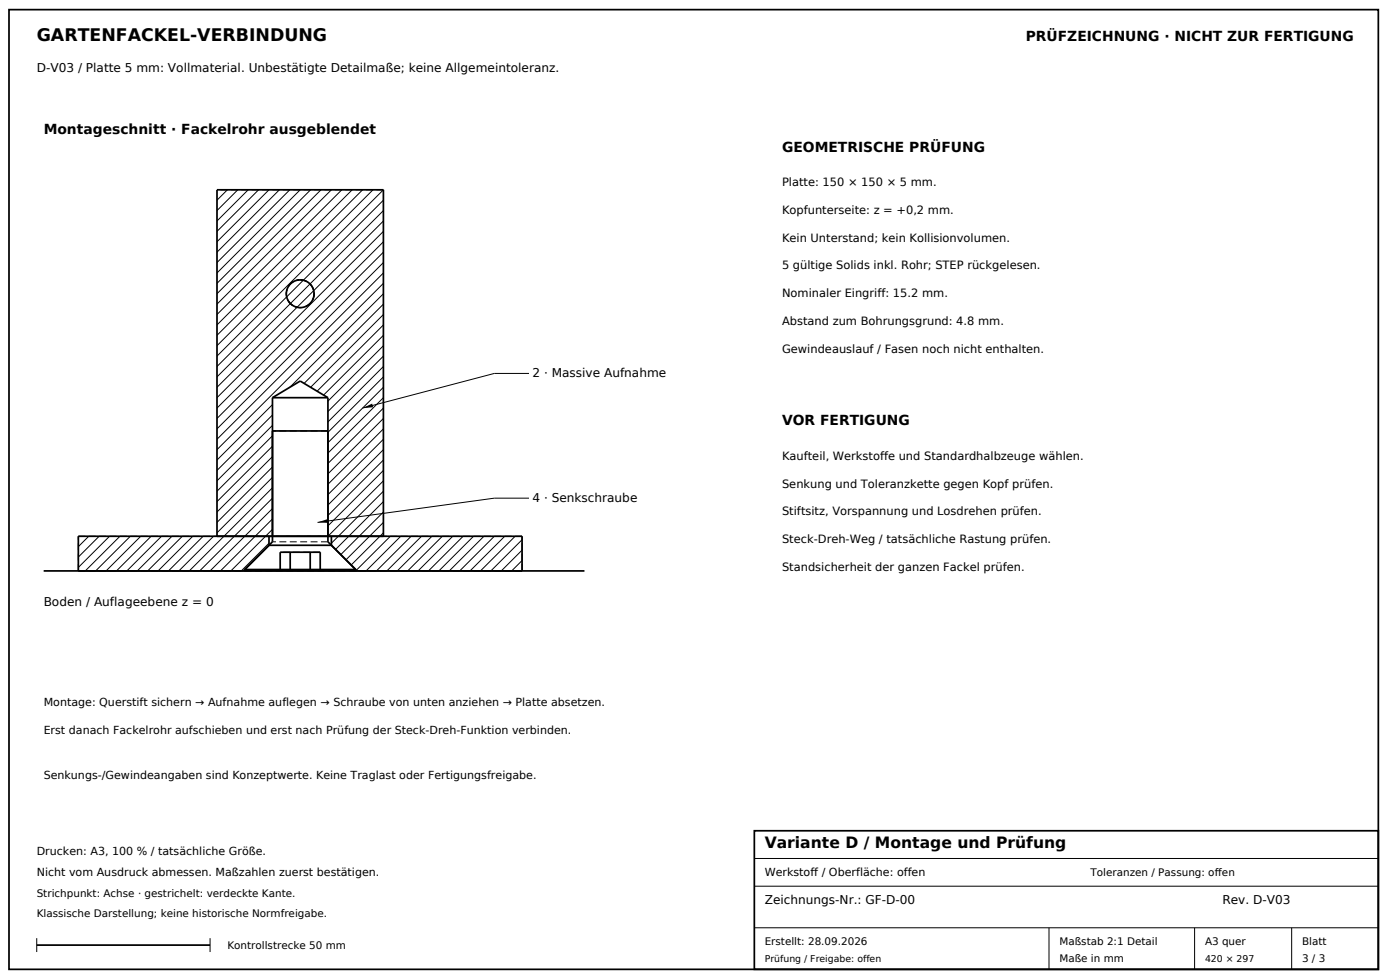
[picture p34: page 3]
Werkstoff / Oberfläche: offen; Toleranzen / Passung: offen; Zeichnungs-Nr.: GF-D-00; Rev. D-V03; Maßstab 2:1 Detail; Boden / Auflageebene z = 0; 2 · Massive Aufnahme; 4 · Senkschraube; GEOMETRISCHE PRÜFUNG; Platte: 150 × 150 × 5 mm.; Kopfunterseite: z = +0,2 mm.; VOR FERTIGUNG

D-V03 / Platte 5 mm: Vollmaterial. Unbestätigte Detailmaße; keine Allgemeintoleranz.

Montageschnitt · Fackelrohr ausgeblendet

Kein Unterstand; kein Kollisionvolumen.

5 gültige Solids inkl. Rohr; STEP rückgelesen.

Nominaler Eingriff: 15.2 mm.

Abstand zum Bohrungsgrund: 4.8 mm.

Gewindeauslauf / Fasen noch nicht enthalten.

Kaufteil, Werkstoffe und Standardhalbzeuge wählen.

Senkung und Toleranzkette gegen Kopf prüfen.

Stiftsitz, Vorspannung und Losdrehen prüfen.

Steck-Dreh-Weg / tatsächliche Rastung prüfen.

Standsicherheit der ganzen Fackel prüfen.

Montage: Querstift sichern → Aufnahme auflegen → Schraube von unten anziehen → Platte absetzen.

Erst danach Fackelrohr aufschieben und erst nach Prüfung der Steck-Dreh-Funktion verbinden.

Senkungs-/Gewindeangaben sind Konzeptwerte. Keine Traglast oder Fertigungsfreigabe.

Variante D / Montage und Prüfung

Drucken: A3, 100 % / tatsächliche Größe.
Nicht vom Ausdruck abmessen. Maßzahlen zuerst bestätigen.

Strichpunkt: Achse · gestrichelt: verdeckte Kante.

Klassische Darstellung; keine historische Normfreigabe.

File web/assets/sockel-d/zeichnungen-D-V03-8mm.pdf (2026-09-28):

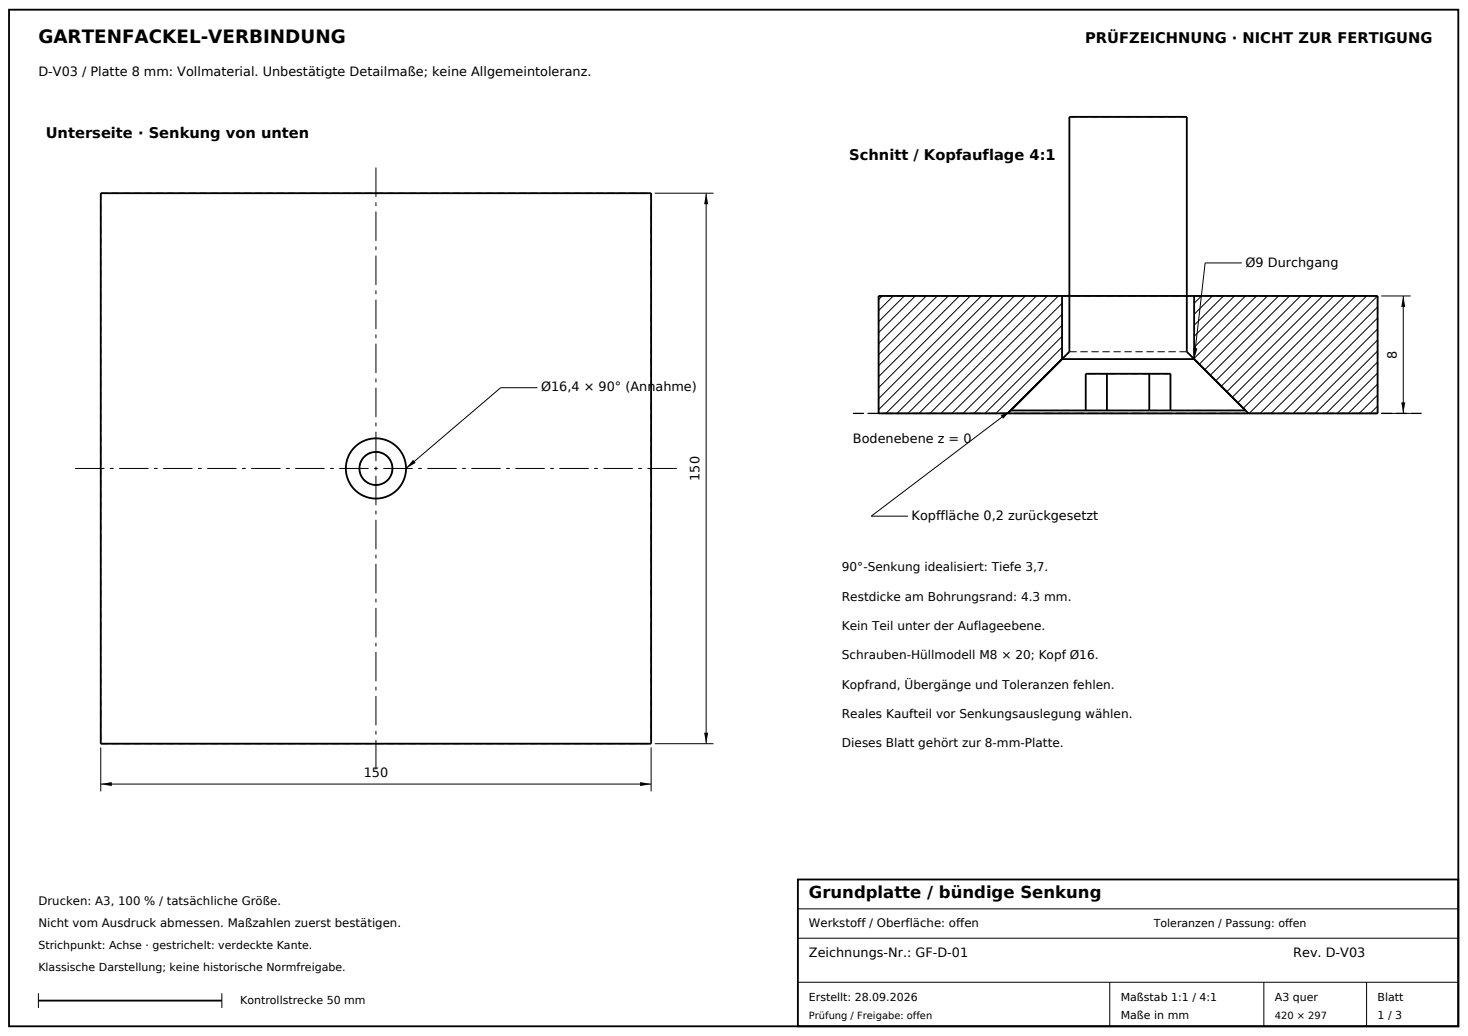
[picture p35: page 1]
GARTENFACKEL-VERBINDUNG; PRÜFZEICHNUNG · NICHT ZUR FERTIGUNG; Werkstoff / Oberfläche: offen; Toleranzen / Passung: offen; Zeichnungs-Nr.: GF-D-01; Rev. D-V03; Erstellt: 28.09.2026; A3 quer; Blatt; Kontrollstrecke 50 mm; Ø16,4 × 90° (Annahme); Schnitt / Kopfauflage 4:1; Bodenebene z = 0; Kopffläche 0,2 zurückgesetzt; Ø9 Durchgang

D-V03 / Platte 8 mm: Vollmaterial. Unbestätigte Detailmaße; keine Allgemeintoleranz.

Unterseite · Senkung von unten

90°-Senkung idealisiert: Tiefe 3,7.

Restdicke am Bohrungsrand: 4.3 mm.

Kein Teil unter der Auflageebene.

Schrauben-Hüllmodell M8 × 20; Kopf Ø16.

Kopfrand, Übergänge und Toleranzen fehlen.

Reales Kaufteil vor Senkungsauslegung wählen.

Dieses Blatt gehört zur 8-mm-Platte.

Grundplatte / bündige Senkung

Drucken: A3, 100 % / tatsächliche Größe.
Nicht vom Ausdruck abmessen. Maßzahlen zuerst bestätigen.

Strichpunkt: Achse · gestrichelt: verdeckte Kante.

Klassische Darstellung; keine historische Normfreigabe.

Maßstab 1:1 / 4:1
Maße in mm

Prüfung / Freigabe: offen

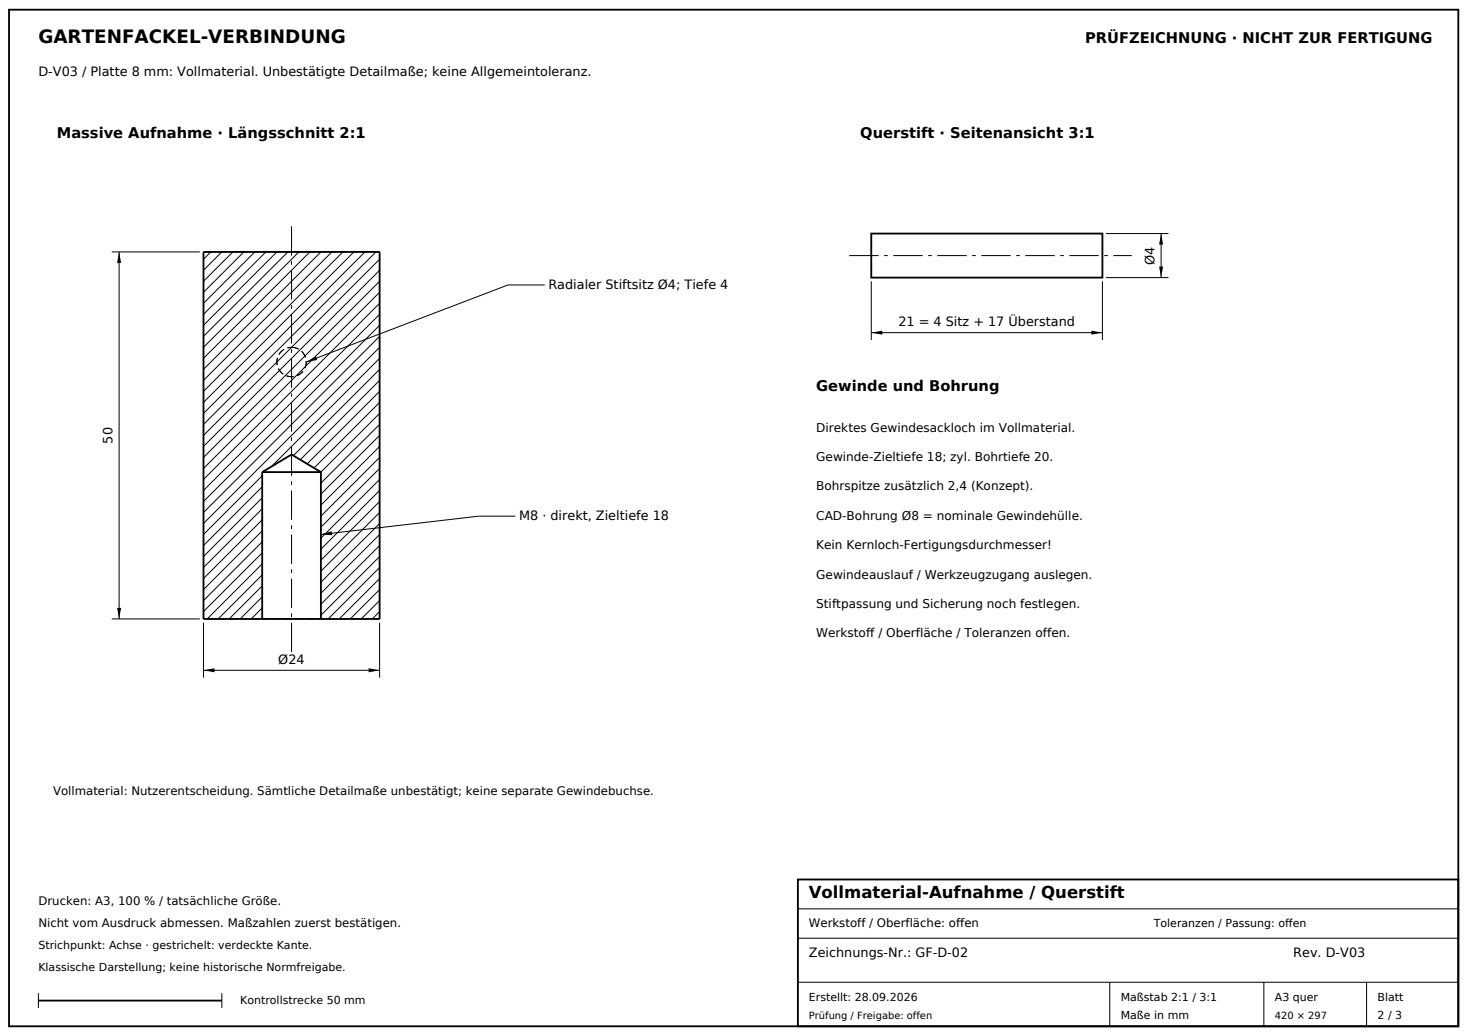
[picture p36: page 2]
Werkstoff / Oberfläche: offen; Toleranzen / Passung: offen; Zeichnungs-Nr.: GF-D-02; Rev. D-V03; Maßstab 2:1 / 3:1; M8 · direkt, Zieltiefe 18; Querstift · Seitenansicht 3:1; 21 = 4 Sitz + 17 Überstand

D-V03 / Platte 8 mm: Vollmaterial. Unbestätigte Detailmaße; keine Allgemeintoleranz.

Massive Aufnahme · Längsschnitt 2:1 50

Radialer Stiftsitz Ø4; Tiefe 4

Gewinde und Bohrung

Direktes Gewindesackloch im Vollmaterial.

Gewinde-Zieltiefe 18; zyl. Bohrtiefe 20.

Bohrspitze zusätzlich 2,4 (Konzept).

CAD-Bohrung Ø8 = nominale Gewindehülle.

Kein Kernloch-Fertigungsdurchmesser!

Gewindeauslauf / Werkzeugzugang auslegen.

Stiftpassung und Sicherung noch festlegen.

Werkstoff / Oberfläche / Toleranzen offen.

Vollmaterial: Nutzerentscheidung. Sämtliche Detailmaße unbestätigt; keine separate Gewindebuchse.

Vollmaterial-Aufnahme / Querstift

Drucken: A3, 100 % / tatsächliche Größe.
Nicht vom Ausdruck abmessen. Maßzahlen zuerst bestätigen.

Strichpunkt: Achse · gestrichelt: verdeckte Kante.

Klassische Darstellung; keine historische Normfreigabe.

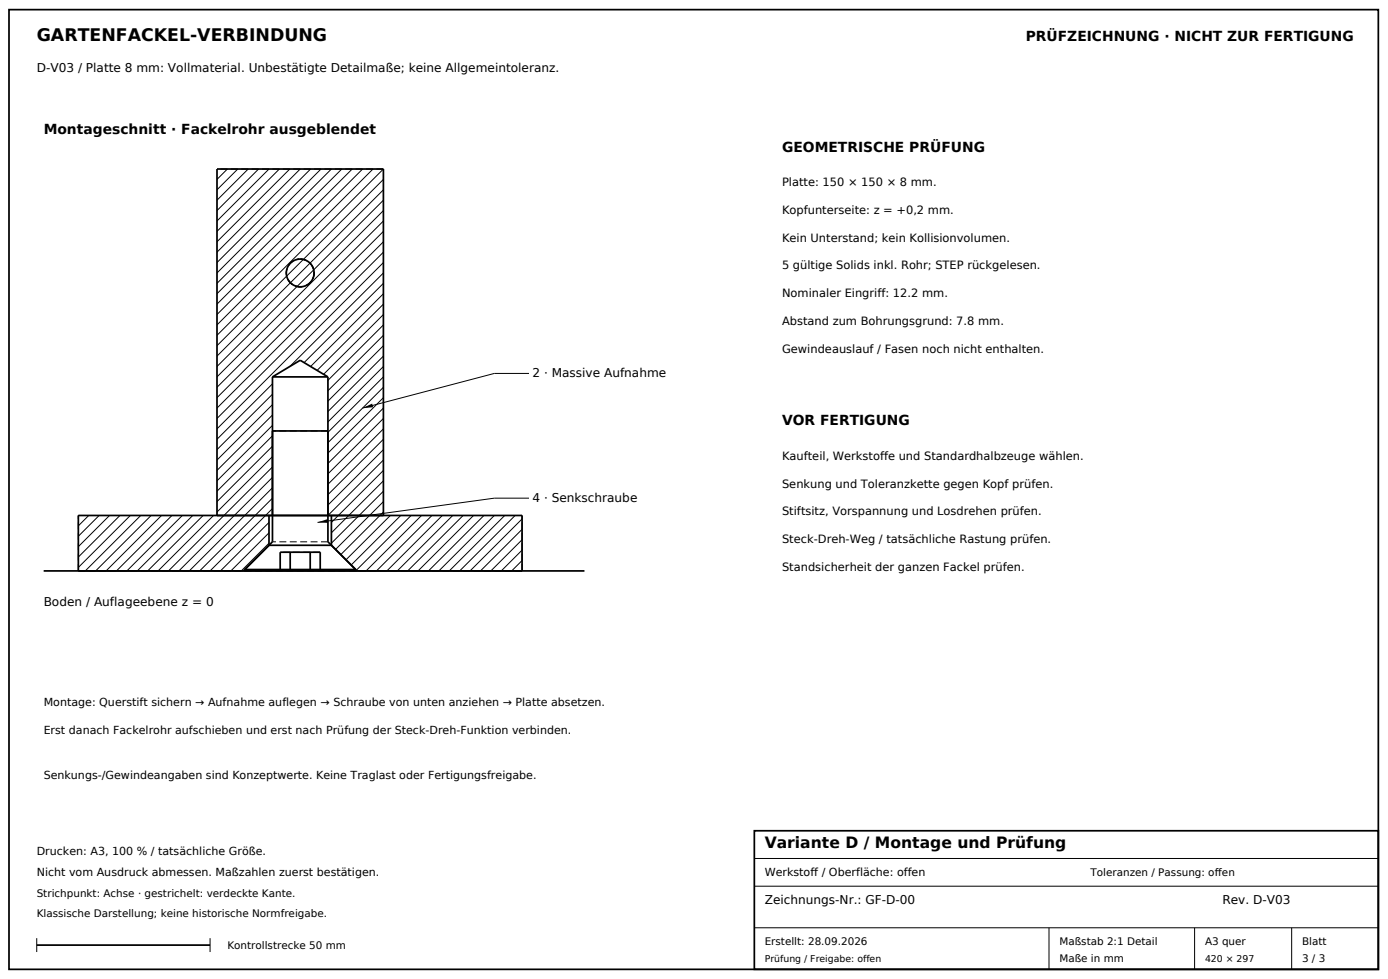
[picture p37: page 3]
Werkstoff / Oberfläche: offen; Toleranzen / Passung: offen; Zeichnungs-Nr.: GF-D-00; Rev. D-V03; Maßstab 2:1 Detail; Boden / Auflageebene z = 0; 2 · Massive Aufnahme; 4 · Senkschraube; GEOMETRISCHE PRÜFUNG; Platte: 150 × 150 × 8 mm.; Kopfunterseite: z = +0,2 mm.; VOR FERTIGUNG

D-V03 / Platte 8 mm: Vollmaterial. Unbestätigte Detailmaße; keine Allgemeintoleranz.

Montageschnitt · Fackelrohr ausgeblendet

Kein Unterstand; kein Kollisionvolumen.

5 gültige Solids inkl. Rohr; STEP rückgelesen.

Nominaler Eingriff: 12.2 mm.

Abstand zum Bohrungsgrund: 7.8 mm.

Gewindeauslauf / Fasen noch nicht enthalten.

Kaufteil, Werkstoffe und Standardhalbzeuge wählen.

Senkung und Toleranzkette gegen Kopf prüfen.

Stiftsitz, Vorspannung und Losdrehen prüfen.

Steck-Dreh-Weg / tatsächliche Rastung prüfen.

Standsicherheit der ganzen Fackel prüfen.

Montage: Querstift sichern → Aufnahme auflegen → Schraube von unten anziehen → Platte absetzen.

Erst danach Fackelrohr aufschieben und erst nach Prüfung der Steck-Dreh-Funktion verbinden.

Senkungs-/Gewindeangaben sind Konzeptwerte. Keine Traglast oder Fertigungsfreigabe.

Variante D / Montage und Prüfung

Drucken: A3, 100 % / tatsächliche Größe.
Nicht vom Ausdruck abmessen. Maßzahlen zuerst bestätigen.

Strichpunkt: Achse · gestrichelt: verdeckte Kante.

Klassische Darstellung; keine historische Normfreigabe.

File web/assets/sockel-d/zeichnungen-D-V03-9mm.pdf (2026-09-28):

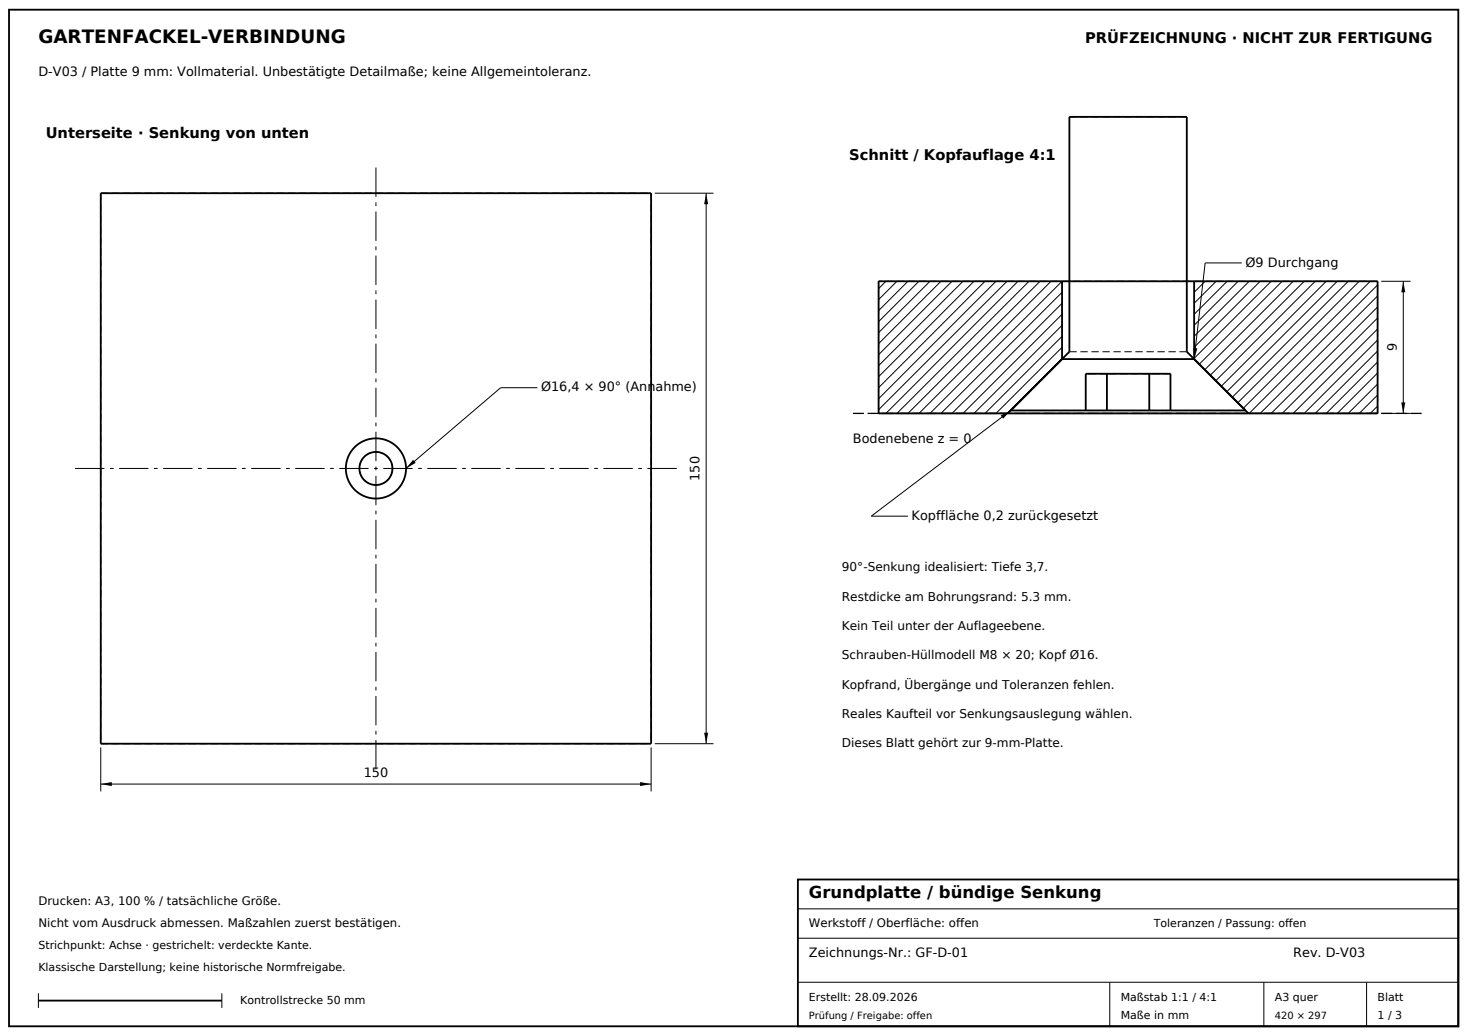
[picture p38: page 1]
GARTENFACKEL-VERBINDUNG; PRÜFZEICHNUNG · NICHT ZUR FERTIGUNG; Werkstoff / Oberfläche: offen; Toleranzen / Passung: offen; Zeichnungs-Nr.: GF-D-01; Rev. D-V03; Erstellt: 28.09.2026; A3 quer; Blatt; Kontrollstrecke 50 mm; Ø16,4 × 90° (Annahme); Schnitt / Kopfauflage 4:1; Bodenebene z = 0; Kopffläche 0,2 zurückgesetzt; Ø9 Durchgang

D-V03 / Platte 9 mm: Vollmaterial. Unbestätigte Detailmaße; keine Allgemeintoleranz.

Unterseite · Senkung von unten

90°-Senkung idealisiert: Tiefe 3,7.

Restdicke am Bohrungsrand: 5.3 mm.

Kein Teil unter der Auflageebene.

Schrauben-Hüllmodell M8 × 20; Kopf Ø16.

Kopfrand, Übergänge und Toleranzen fehlen.

Reales Kaufteil vor Senkungsauslegung wählen.

Dieses Blatt gehört zur 9-mm-Platte.

Grundplatte / bündige Senkung

Drucken: A3, 100 % / tatsächliche Größe.
Nicht vom Ausdruck abmessen. Maßzahlen zuerst bestätigen.

Strichpunkt: Achse · gestrichelt: verdeckte Kante.

Klassische Darstellung; keine historische Normfreigabe.

Maßstab 1:1 / 4:1
Maße in mm

Prüfung / Freigabe: offen

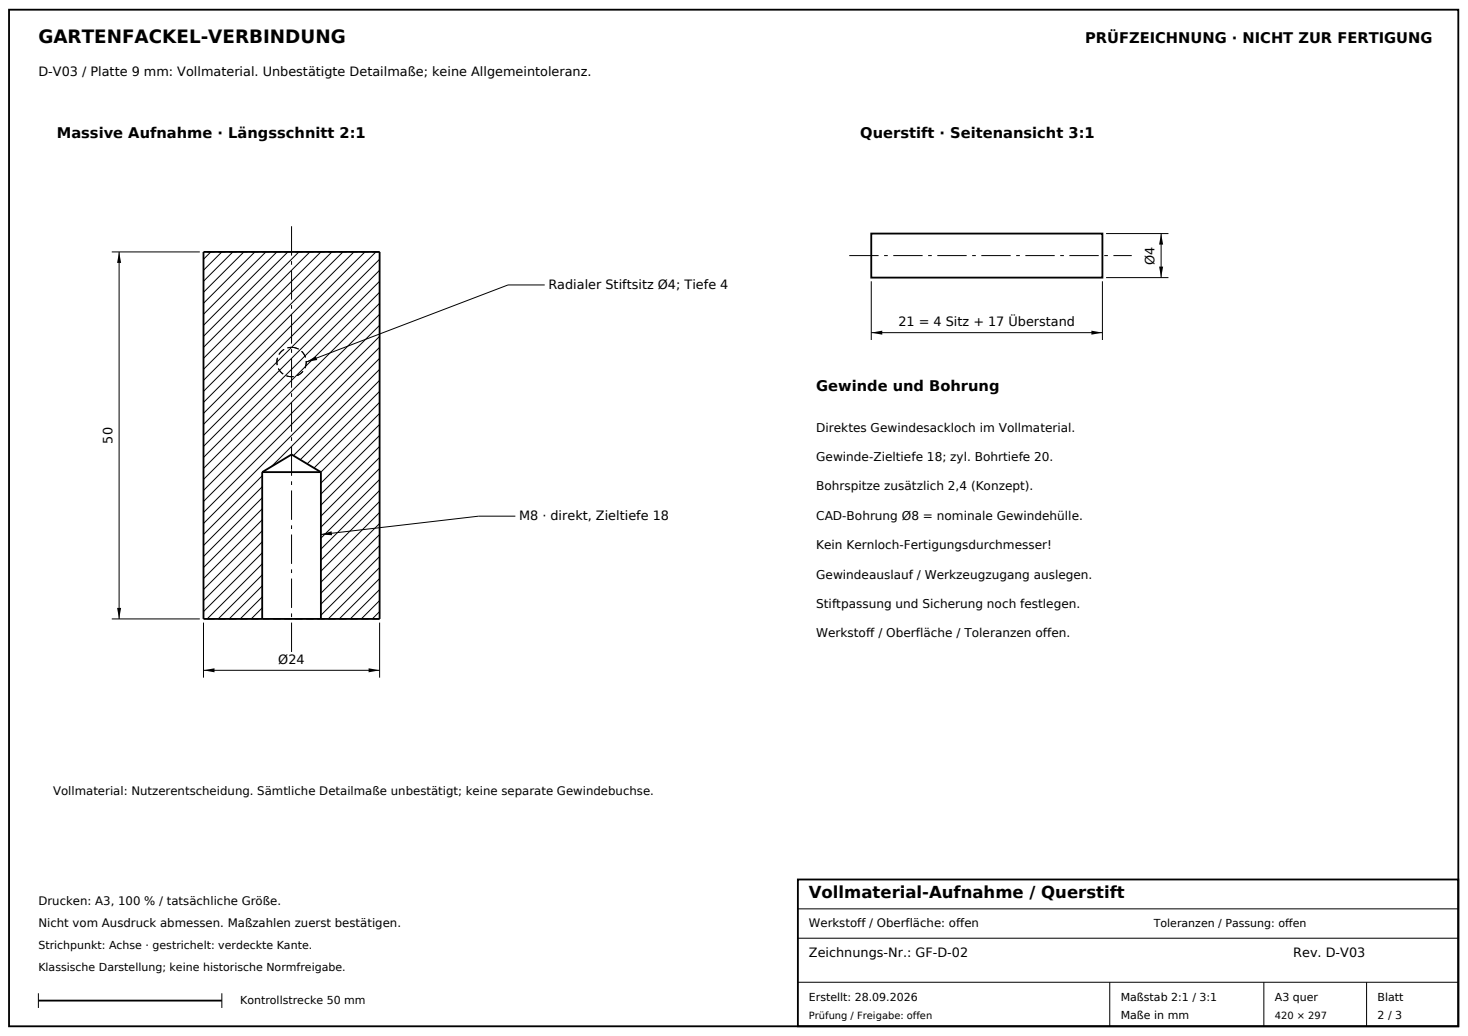
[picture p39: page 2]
Werkstoff / Oberfläche: offen; Toleranzen / Passung: offen; Zeichnungs-Nr.: GF-D-02; Rev. D-V03; Maßstab 2:1 / 3:1; M8 · direkt, Zieltiefe 18; Querstift · Seitenansicht 3:1; 21 = 4 Sitz + 17 Überstand

D-V03 / Platte 9 mm: Vollmaterial. Unbestätigte Detailmaße; keine Allgemeintoleranz.

Massive Aufnahme · Längsschnitt 2:1 50

Radialer Stiftsitz Ø4; Tiefe 4

Gewinde und Bohrung

Direktes Gewindesackloch im Vollmaterial.

Gewinde-Zieltiefe 18; zyl. Bohrtiefe 20.

Bohrspitze zusätzlich 2,4 (Konzept).

CAD-Bohrung Ø8 = nominale Gewindehülle.

Kein Kernloch-Fertigungsdurchmesser!

Gewindeauslauf / Werkzeugzugang auslegen.

Stiftpassung und Sicherung noch festlegen.

Werkstoff / Oberfläche / Toleranzen offen.

Vollmaterial: Nutzerentscheidung. Sämtliche Detailmaße unbestätigt; keine separate Gewindebuchse.

Vollmaterial-Aufnahme / Querstift

Drucken: A3, 100 % / tatsächliche Größe.
Nicht vom Ausdruck abmessen. Maßzahlen zuerst bestätigen.

Strichpunkt: Achse · gestrichelt: verdeckte Kante.

Klassische Darstellung; keine historische Normfreigabe.

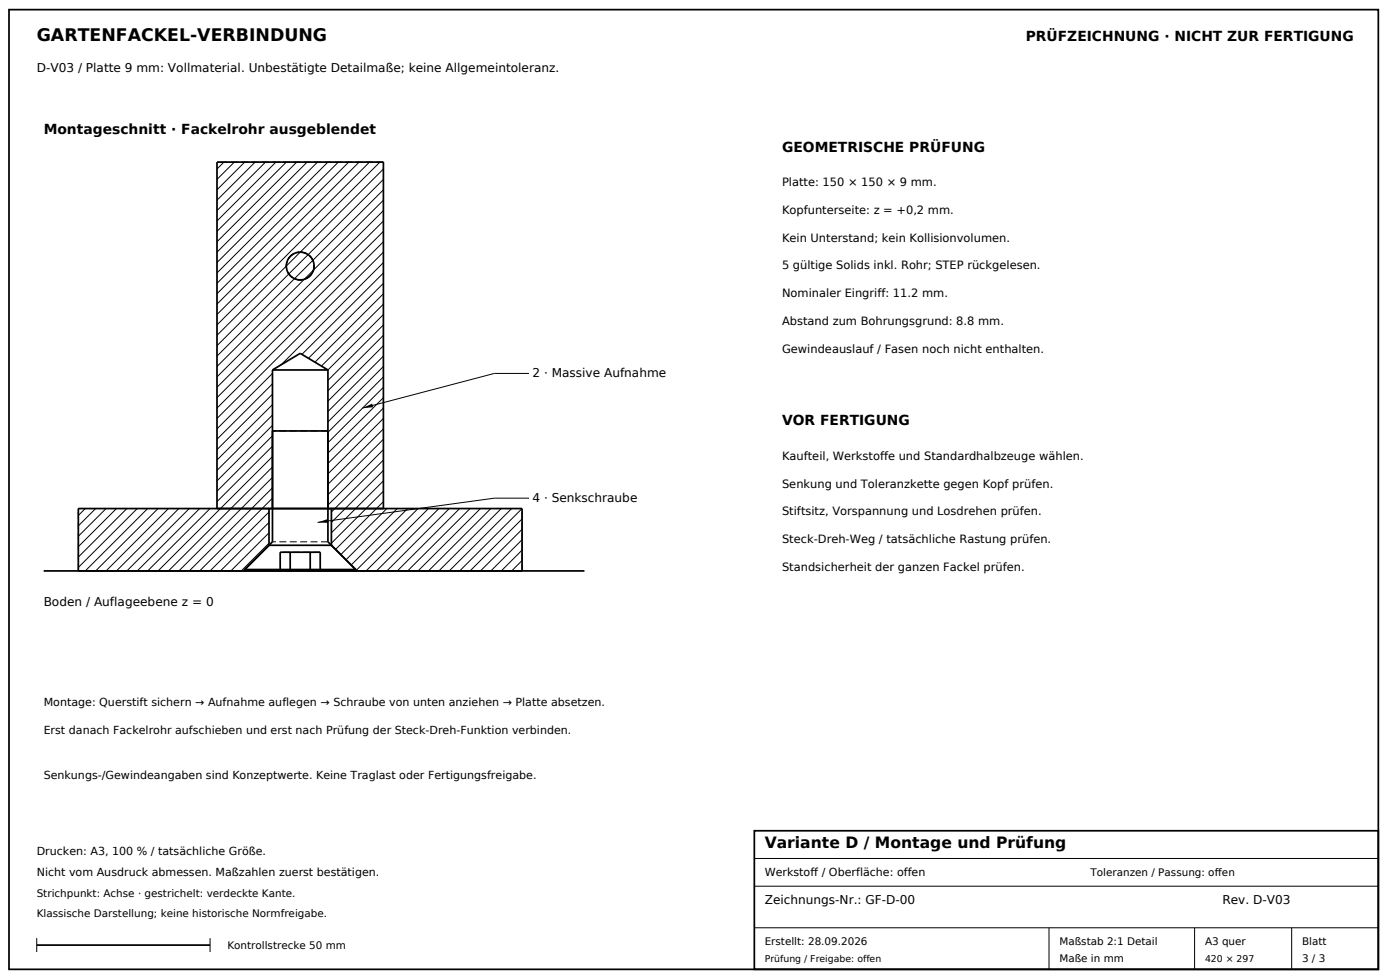
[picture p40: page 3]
Werkstoff / Oberfläche: offen; Toleranzen / Passung: offen; Zeichnungs-Nr.: GF-D-00; Rev. D-V03; Maßstab 2:1 Detail; Boden / Auflageebene z = 0; 2 · Massive Aufnahme; 4 · Senkschraube; GEOMETRISCHE PRÜFUNG; Platte: 150 × 150 × 9 mm.; Kopfunterseite: z = +0,2 mm.; VOR FERTIGUNG

D-V03 / Platte 9 mm: Vollmaterial. Unbestätigte Detailmaße; keine Allgemeintoleranz.

Montageschnitt · Fackelrohr ausgeblendet

Kein Unterstand; kein Kollisionvolumen.

5 gültige Solids inkl. Rohr; STEP rückgelesen.

Nominaler Eingriff: 11.2 mm.

Abstand zum Bohrungsgrund: 8.8 mm.

Gewindeauslauf / Fasen noch nicht enthalten.

Kaufteil, Werkstoffe und Standardhalbzeuge wählen.

Senkung und Toleranzkette gegen Kopf prüfen.

Stiftsitz, Vorspannung und Losdrehen prüfen.

Steck-Dreh-Weg / tatsächliche Rastung prüfen.

Standsicherheit der ganzen Fackel prüfen.

Montage: Querstift sichern → Aufnahme auflegen → Schraube von unten anziehen → Platte absetzen.

Erst danach Fackelrohr aufschieben und erst nach Prüfung der Steck-Dreh-Funktion verbinden.

Senkungs-/Gewindeangaben sind Konzeptwerte. Keine Traglast oder Fertigungsfreigabe.

Variante D / Montage und Prüfung

Drucken: A3, 100 % / tatsächliche Größe.
Nicht vom Ausdruck abmessen. Maßzahlen zuerst bestätigen.

Strichpunkt: Achse · gestrichelt: verdeckte Kante.

Klassische Darstellung; keine historische Normfreigabe.

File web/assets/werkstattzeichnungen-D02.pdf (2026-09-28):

GARTENFACKEL-VERBINDUNG | PRÜFZEICHNUNG · NICHT ZUR FERTIGUNG

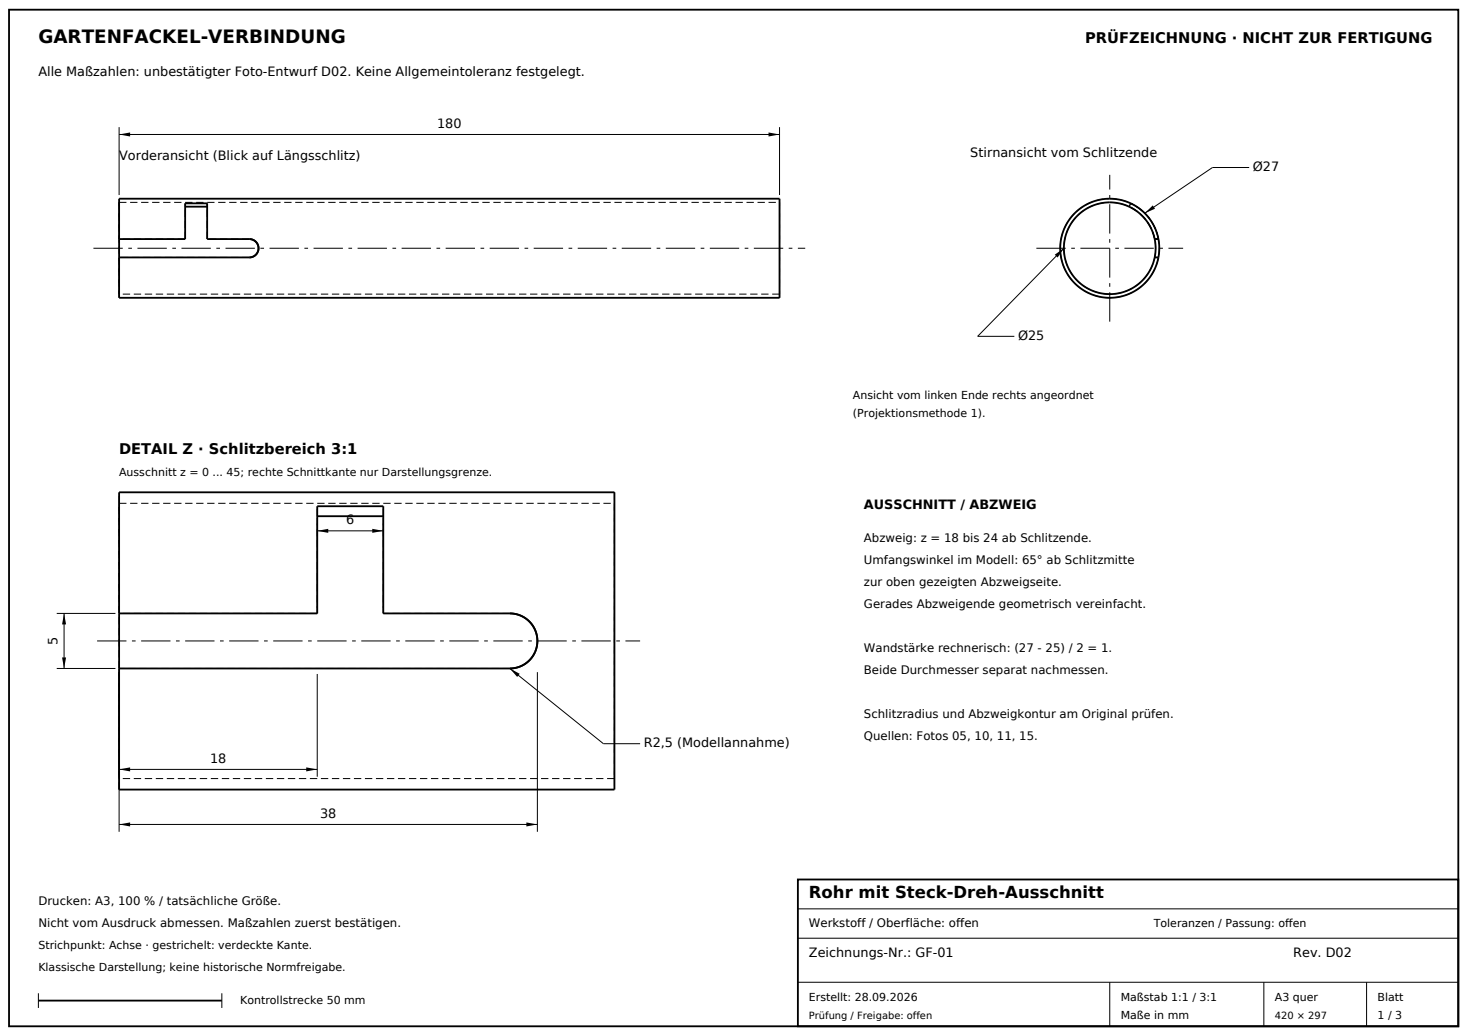
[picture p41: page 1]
Werkstoff / Oberfläche: offen; Toleranzen / Passung: offen; Zeichnungs-Nr.: GF-01; Rev. D02; Erstellt: 28.09.2026; A3 quer; Blatt; Kontrollstrecke 50 mm; DETAIL Z · Schlitzbereich 3:1; R2,5 (Modellannahme); AUSSCHNITT / ABZWEIG

Alle Maßzahlen: unbestätigter Foto-Entwurf D02. Keine Allgemeintoleranz festgelegt.

Vorderansicht (Blick auf Längsschlitz)

Stirnansicht vom Schlitzende

Ansicht vom linken Ende rechts angeordnet
(Projektionsmethode 1).

Ausschnitt z = 0 ... 45; rechte Schnittkante nur Darstellungsgrenze.

Abzweig: z = 18 bis 24 ab Schlitzende.
Umfangswinkel im Modell: 65° ab Schlitzmitte
zur oben gezeigten Abzweigseite.
Gerades Abzweigende geometrisch vereinfacht.

Wandstärke rechnerisch: (27 - 25) / 2 = 1.
Beide Durchmesser separat nachmessen.

Schlitzradius und Abzweigkontur am Original prüfen.
Quellen: Fotos 05, 10, 11, 15.

Rohr mit Steck-Dreh-Ausschnitt

Drucken: A3, 100 % / tatsächliche Größe.
Nicht vom Ausdruck abmessen. Maßzahlen zuerst bestätigen.

Strichpunkt: Achse · gestrichelt: verdeckte Kante.

Klassische Darstellung; keine historische Normfreigabe.

Maßstab 1:1 / 3:1
Maße in mm

Prüfung / Freigabe: offen

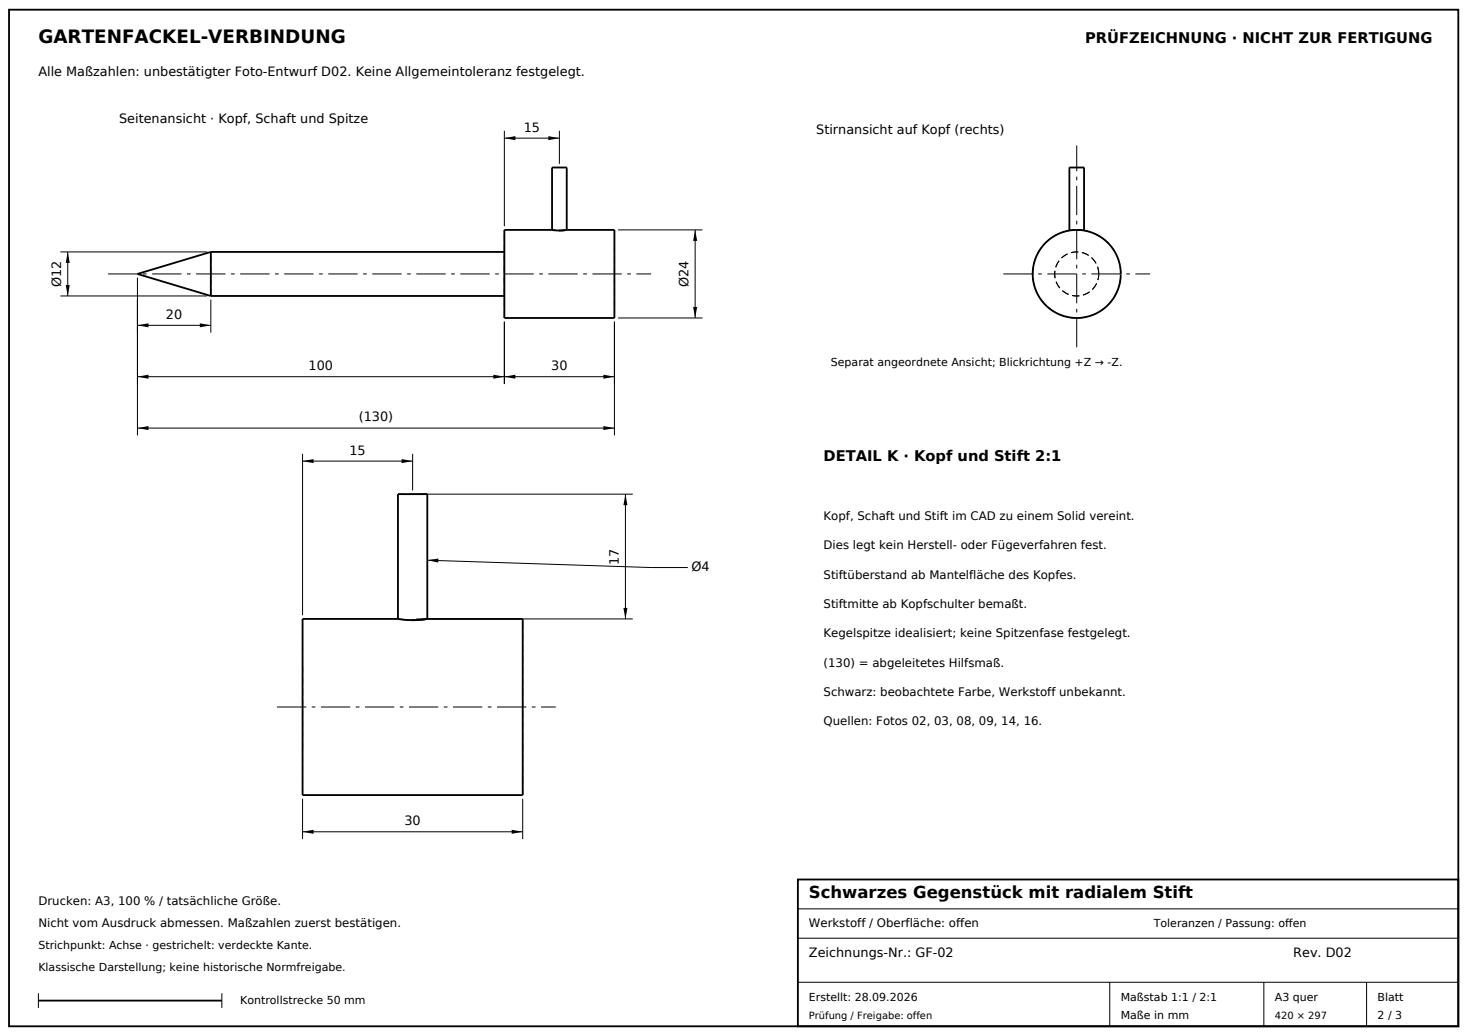
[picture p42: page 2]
Werkstoff / Oberfläche: offen; Toleranzen / Passung: offen; Zeichnungs-Nr.: GF-02; Rev. D02; Maßstab 1:1 / 2:1; (130) = abgeleitetes Hilfsmaß.; Quellen: Fotos 02, 03, 08, 09, 14, 16.

Alle Maßzahlen: unbestätigter Foto-Entwurf D02. Keine Allgemeintoleranz festgelegt.

Seitenansicht · Kopf, Schaft und Spitze

Stirnansicht auf Kopf (rechts)

Separat angeordnete Ansicht; Blickrichtung +Z → -Z.

DETAIL K · Kopf und Stift 2:1

Kopf, Schaft und Stift im CAD zu einem Solid vereint.

Dies legt kein Herstell- oder Fügeverfahren fest.

Stiftüberstand ab Mantelfläche des Kopfes.

Stiftmitte ab Kopfschulter bemaßt.

Kegelspitze idealisiert; keine Spitzenfase festgelegt.

Schwarz: beobachtete Farbe, Werkstoff unbekannt.

Schwarzes Gegenstück mit radialem Stift

Drucken: A3, 100 % / tatsächliche Größe.
Nicht vom Ausdruck abmessen. Maßzahlen zuerst bestätigen.

Strichpunkt: Achse · gestrichelt: verdeckte Kante.

Klassische Darstellung; keine historische Normfreigabe.

### Zusammengesteckt · illustrative Lage, nicht als Verriegelung bestätigt

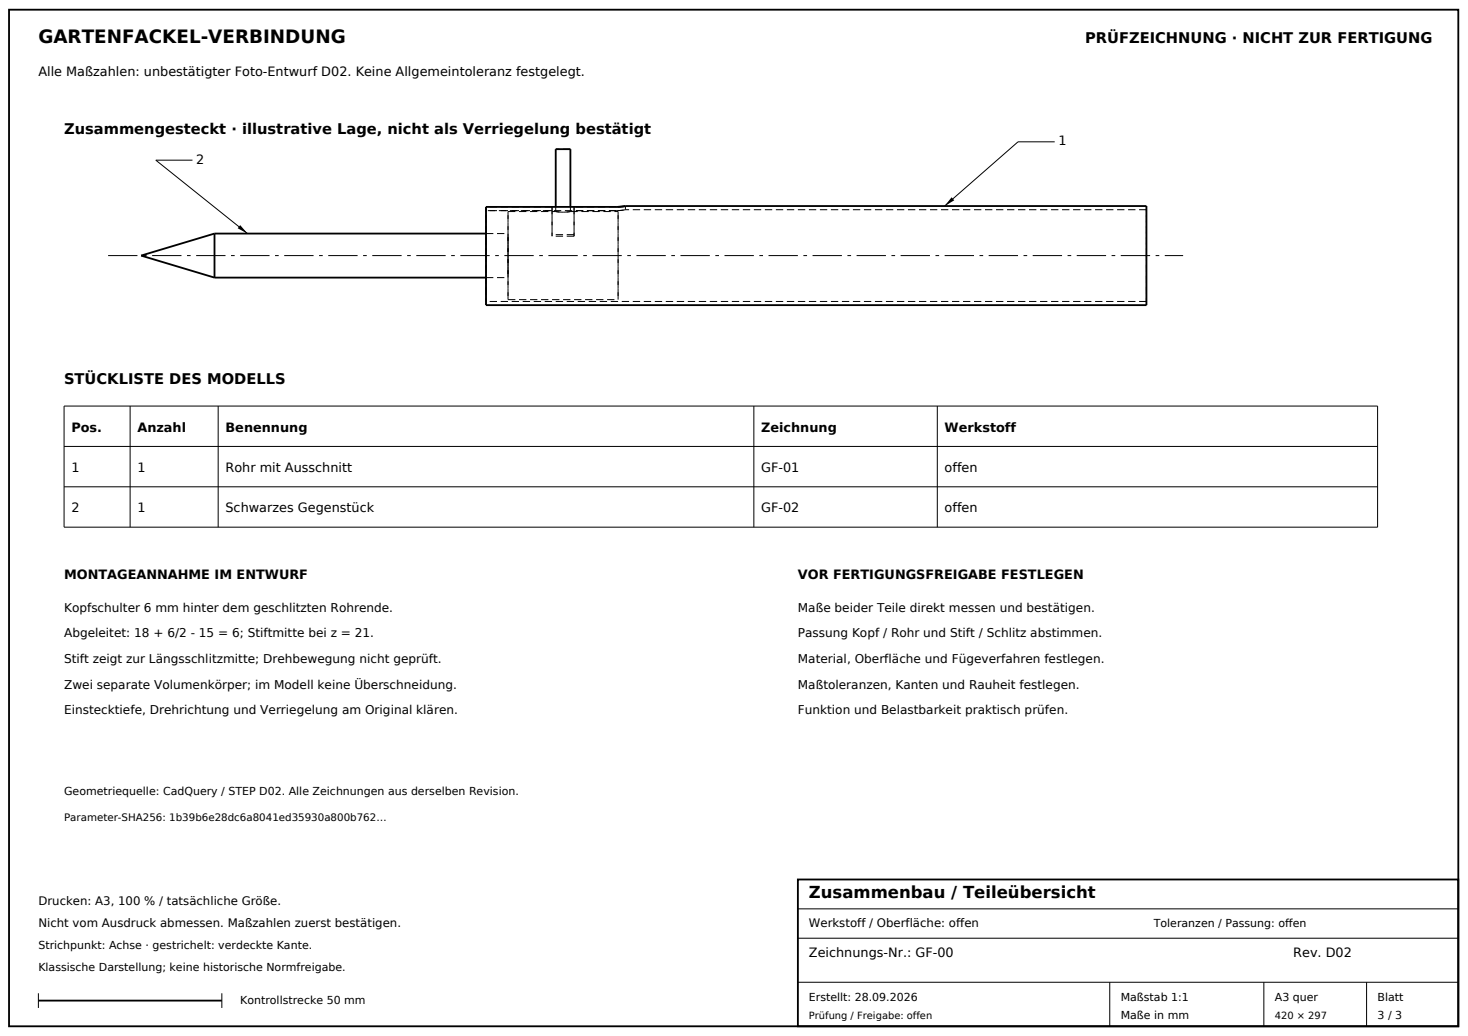
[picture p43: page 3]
Zusammenbau / Teileübersicht; Werkstoff / Oberfläche: offen; Toleranzen / Passung: offen; Zeichnungs-Nr.: GF-00; Rev. D02; Maßstab 1:1; Parameter-SHA256: 1b39b6e28dc6a8041ed35930a800b762…

Alle Maßzahlen: unbestätigter Foto-Entwurf D02. Keine Allgemeintoleranz festgelegt.

STÜCKLISTE DES MODELLS

Pos. | Anzahl | Benennung | Zeichnung | Werkstoff

1 | 1 | Rohr mit Ausschnitt | GF-01 | offen

2 | 1 | Schwarzes Gegenstück | GF-02 | offen

MONTAGEANNAHME IM ENTWURF

VOR FERTIGUNGSFREIGABE FESTLEGEN

Kopfschulter 6 mm hinter dem geschlitzten Rohrende.

Maße beider Teile direkt messen und bestätigen.

Abgeleitet: 18 + 6/2 - 15 = 6; Stiftmitte bei z = 21.

Passung Kopf / Rohr und Stift / Schlitz abstimmen.

Stift zeigt zur Längsschlitzmitte; Drehbewegung nicht geprüft.

Material, Oberfläche und Fügeverfahren festlegen.

Zwei separate Volumenkörper; im Modell keine Überschneidung.

Maßtoleranzen, Kanten und Rauheit festlegen.

Einstecktiefe, Drehrichtung und Verriegelung am Original klären.

Funktion und Belastbarkeit praktisch prüfen.

Geometriequelle: CadQuery / STEP D02. Alle Zeichnungen aus derselben Revision.

Drucken: A3, 100 % / tatsächliche Größe.
Nicht vom Ausdruck abmessen. Maßzahlen zuerst bestätigen.

Strichpunkt: Achse · gestrichelt: verdeckte Kante.

Klassische Darstellung; keine historische Normfreigabe.

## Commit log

2026-09-28 Document connector scope, photo inventory, measurement plan and CAD workflow
2026-09-28 Specify engineering viewer, CAD provenance and quality checks
2026-09-28 Record lightweight reusable photo-to-CAD workflow
2026-09-28 Build D01 CAD draft and tested Three.js viewer with Pages deployment
    [connector-draft.step]
2026-09-28 Fix D02: model both connector parts and publish assembly viewer
    [connector-draft.step, spike-draft.step, tube-draft.step]
2026-09-28 Add classical A3 technical review drawings for both parts and assembly
2026-09-28 Add four CAD pedestal concepts with section views, costs and 150x150x5 plate assumption
    [A-concept.step, B-concept.step, C-concept.step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]
2026-09-28 Select variant D with recessed screw, CAD checks, drawings and procurement roadmap
    [adapter-5.step, adapter-8.step, adapter-9.step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]
2026-09-28 D-V03 solid-stock adapter with direct blind thread; update all deliverables and session handover
    [adapter-5.step, adapter-8.step, adapter-9.step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]
2026-09-28 D-V03: check assembly motion, add guided montage and sourced procurement/cost scenarios
2026-09-28 Repair truncated 8 mm assembly preview from unchanged PDF and refresh image cache
2026-09-28 Keep screw section aligned with the explanatory cutting plane
2026-09-28 Unify D-V03 decision chain and repair viewer state, fallback and animation semantics
2026-09-28 Restore a clean model-first layout and unify all current document templates
2026-09-28 Add separate mobile UX preview with three task areas and CAD-derived images
2026-09-28 Record project verification and keep review frames on the requested release
2026-09-28 feat: connect scene exploration, clipping, assembly cues and shareable views
2026-10-01 Add isolated fictional One More Thing X-ray demo with liquid-metal bearing and principle animation
    [anode.stl, assembly.stl, base.stl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]
2026-10-01 Add responsive XR demo review frame
2026-10-01 Refine narrow-view camera and SVG face rendering; record XR demo checks
2026-10-01 Propagate review revision into demo frame to avoid stale QA pages
2026-10-01 Redesign XR demo as Vectron-inspired visual study with regenerated models and sheets
    [anode.stl, assembly.stl, base.stl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]
